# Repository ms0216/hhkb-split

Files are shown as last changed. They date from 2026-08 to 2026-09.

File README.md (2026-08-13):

# hhkb-split

**HHKB Professional HYBRID Type-S（PD-KB800WNS / US配列 / 無刻印）の使い勝手を、
完全分割型で再現する自作キーボード。**

> **開発中です。** 実機での動作確認はまだ済んでいません。
> 現状は「CAD とファームウェアがビルドを通り、寸法と配列が実機調査で裏付けられている」段階です。
> 3Dプリント・基板発注・組み立ては未実施。

## 基本方針

**HHKB オリジナルの使い勝手を極力踏襲する。** 分割にするために必要な変更だけを加え、
それ以外は変えない。この方針は [tools/test_invariants.py](tools/test_invariants.py) に
テストとして書き下してあり、設計の都合で妥協しようとすると機械的に落ちる。

守っているもの:

| 項目 | 値 | 根拠 |
|---|---|---|
| キーピッチ | 19.05mm | 実機公称 |
| 打鍵面の傾斜 | 7.3° | 実機ノギス実測 |
| 手前端の高さ | 17.5mm | 実測 17mm と別レビュー約18mm の中間 |
| キートップ高さ（各段） | 26.7 / 29.2 / 31.6 / 35.6 / 40.0mm | 公称全高 40mm から導出 |
| チルト脚 | 0 / 3 / 6° の3段階 | 実機と同一 |
| 行ずれ | HHKB と同一（格子配列にしない） | 実機 |
| 最下段 | 外側 1u / スペース寄り 1.5u | QMK info.json + KLE 図 |
| 電源 | 単3 × 2 | 実機と同じ思想（リポにしない） |

変更したもの:

- **打鍵感** — 静電容量無接点（Topre）→ MX 互換 + ホットスワップソケット
- **分割** — 6u スペースを 3u + 3u に分割。**左右とも Space**。キーは増やさない（60 → 61）
- **Mac/Win 切替** — 実機の DIP スイッチ相当をソフトウェアで実現
- **無線** — 左右間も Bluetooth。TRRS 有線は障害時の予備でしかない

## 構成

```
layout/        HHKB オリジナルと分割版のキー配列（JSON）
tools/         配列読み込み・CAD生成・検証（Python / build123d）
config/        ZMK ファームウェア設定
docs/hardware/ 実機の寸法調査と、その出典・失敗した調査経路の記録
build/         生成された STL（未印刷）
```

### tools/

パラメトリック CAD。`build123d`（OCCT）でモデルを生成し、`trimesh` で
メッシュ健全性を、OrcaSlicer CLI で実際にスライスできるかを検証する。

```bash
python -m pytest tools          # 全検査（約 14 分。件数は --collect-only で数える）
python tools/gen_case.py        # ケースを生成
python tools/verify.py          # メッシュとスライスの検証
```

[tools/interface.py](tools/interface.py) は**プレート・ケース・基板が共有する境界**を
1 箇所に集めたもの。ケースは刷り直せるが基板は発注し直すと高くつくので、
ここを凍結してから発注する。

### config/

ZMK。ボードは **Seeed Studio XIAO nRF52840**（技適 211-220207）。
XIAO は GPIO が 11 本しかなく普通のマトリクスに 1 本足りないため、列の駆動に
シフトレジスタ **SN74LVC595APWR** を使う（ZMK 公式が推奨する手段）。**74HC595 では打ち止め時に規格外**（動作電圧の下限 2.0V に対し、レールは 1.8V まで下がる）と分かって差し替えた。キーごとにダイオード 1 個の
ごく普通の行×列マトリクスなので、同時押しでゴーストが出ない。
当初はチャープレックス方式で設計していたが、基板発注前に破棄した
（[判断根拠](docs/hardware/decisions/2026-08-07-keyscan.md)）。

| シールド | 用途 |
|---|---|
| `hhkb_split_left` / `hhkb_split_right` | 本番。4レイヤー × 61キー |
| `proto_direct` | 疎通確認（XIAO 1個・キー2個）（[手順書](docs/hardware/task-c1-smoke-test.md)）✅ 実機確認済 |
| `proto_matrix` | マトリクス配線とゴースト試験の治具（[手順書](docs/hardware/task-c2-keyscan.md)）✅ 実機確認済 |

ビルドは GitHub Actions（ZMK 公式の再利用ワークフロー）。Actions の成果物から
`.uf2` をダウンロードして書き込む。

### 検証タスクの手順書

実機で確かめる作業は、配置図と判定基準つきの手順書にしてある。

| タスク | 内容 | 状態 |
|---|---|---|
| [C1](docs/hardware/task-c1-smoke-test.md) | 疎通確認（XIAO・書き込み・ZMK が実機で動くか） | ✅ 合格 |
| [C2](docs/hardware/task-c2-keyscan.md) | キースキャン（マトリクス・ゴースト・シフトレジスタ。治具は 74HC595、本番は 74LVC595） | ✅ C2-a 合格 / ⬜ C2-b |
| [C3](docs/hardware/task-c3-ble-split.md) | BLE 分割（左右同時押しが崩れないか） | ⬜ |
| [C4・C5](docs/hardware/task-c4-c5-power.md) | 乾電池給電・逆流の測定・電池残量 | ⬜ |
| [C6](docs/hardware/task-c6-confirm-on-real-hhkb.md) | 実機の DIP スイッチとキーマップを確認 | ⬜ **部品不要** |
| [B3](docs/hardware/task-b3-print-and-compare.md) | 3Dプリントして実機と比べる | ⬜ **部品不要** |

書き込みでつまずいたときは [xiao-flash-recovery.md](docs/hardware/xiao-flash-recovery.md)。

### docs/hardware/

実機を分解せず、公開情報だけから寸法を確定させた記録。
[reference-sources.md](docs/hardware/reference-sources.md) には**失敗した調査経路 11 件**も
残してある（例: PFU 公式記事に載っていた側面写真 4 枚が、よく見ると HHKB ではなく
MX 軸のキーボードだった）。同じ穴に落ちないため。

## 進捗

| フェーズ | 状態 |
|---|---|
| A. 実機寸法の確定 | ✅ 完了 |
| B. 機構設計（プレート・ケース） | ✅ STL 生成・検証済み / ⬜ 未印刷（[B3](docs/hardware/task-b3-print-and-compare.md)） |
| C. 電気・ファームウェア検証 | 🔶 進行中（**C1・C2-a 合格**。C2-b は 74HC595（治具用。本番は 74LVC595）待ち、C3〜C5 は部品待ち） |
| D. 基板設計（KiCad → JLCPCB） | 🔶 D1・D2a 完了（外形・キー配置・マトリクス）。[詳細](pcb/README.md) |
| E. 組み立て・実機調整 | ⬜ 未着手 |

## ライセンス

未定。

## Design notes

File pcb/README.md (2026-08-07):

# 基板（KiCad）

## 現在の状態

| 段階 | 内容 | 状態 |
|---|---|---|
| D1 | 外形・キー配置・取付穴 | ✅ 完了。DRC 違反 0 |
| D2a | マトリクス（61キー ＋ 61ダイオード ＋ 行列のネット） | ✅ 完了 |
| D3a | マトリクスの配線（行・列・スイッチ→ダイオード） | ✅ 左は違反 0 / ⚠️ 右に 5 件（下記） |
| D2b | XIAO・74HC595・電源の搭載 | ⬜ 3D 実装の検討が要る（下記） |
| D3 | 配線（行・列・電源） | ⬜ |
| D4 | JLCPCB 向け出力（ガーバー・BOM・CPL） | ⬜ |

マトリクスは配線済み（**未配線 0**）。左半分は DRC 違反 0。

### 右半分に残る 5 件

すべて `hole_clearance`（配線が穴に近すぎる）で、原因は特定済み。

列のバスは行間の空きを横に渡るが、**スタビライザーの穴がその帯に食い込んで
いる**（キー中心 +6.2〜10.2mm）。9 列ぶんの通り道を 0.8mm 間隔で並べると、
穴を避けきれない列が出る。

取りうる手:
  1. 穴に当たる区間だけ迂回させる（自動配線の作り込み）
  2. 配線幅と間隔を詰めて通り道を増やす（JLCPCB の最小は 0.127mm）
  3. 該当箇所だけ KiCad の GUI で手直しする

**左半分が完全に通っているので、方式の問題ではない。**

### D2b でまず決めること — XIAO をどこに置くか

XIAO は基板の**裏面**に付く（表に置くとキーキャップと当たる）。ところが
USB-C は実機と同じく**背面**に出す必要があり、基板の裏の背面側には
**電池室（幅 109mm）**が横断している。左半分では電池の外側に
15mm ほどしか残らず、XIAO の 17.8mm が入らない。

取りうる案:
  1. USB-C を基板端のコネクタとして別に載せ、XIAO は空いている隅に置く
  2. 電池を左右に振り分けて中央を空ける（ケースの作り直しが要る）
  3. USB の位置を実機と変える（使い勝手の方針に反するので最後）

**ケースの 3D モデルと合わせて検討する必要がある。** 実測（Task C4）で
電源部の構成が確定してから着手するのが順序として正しい。

## 生成のしかた

`pcbnew` は KiCad 同梱の Python にしか無いので、そちらで動かす。

```bash
/Applications/KiCad/KiCad.app/Contents/Frameworks/Python.framework/Versions/3.9/bin/python3.9 \
    tools/gen_pcb.py
```

## 検証のしかた

```bash
# デザインルール検査（違反があれば終了コードが非 0）
/Applications/KiCad/KiCad.app/Contents/MacOS/kicad-cli pcb drc \
    --severity-error --exit-code-violations pcb/hhkb_split_left.kicad_pcb

# 生成物が設計値と一致するか（通常の pytest から実行できる）
python -m pytest tools/test_pcb.py

# 目で見る
/Applications/KiCad/KiCad.app/Contents/MacOS/kicad-cli pcb render \
    --output /tmp/pcb.png --side top pcb/hhkb_split_left.kicad_pcb
```

`.kicad_pcb` はテキスト（S 式）なので、`tools/test_pcb.py` は pcbnew 無しで
読める。**生成した基板を読み返して、プレート・ケースと突き合わせる**のが要点。
別々に生成される以上、同じ設計値から導いていても座標変換を間違えれば静かに
ずれる。ずれたまま発注すると数万円が無駄になる。

## 寸法

| | 左 | 右 |
|---|---|---|
| 基板 | 140.36 × 102.00mm | 173.70 × 102.00mm |
| スイッチ | 27 | 34 |
| スタビライザー | 2 | 2 |
| 取付穴 | 7 | 7 |

外形はプレートより片側 3.0mm 小さい（`interface.PCB_INSET`）。ケースの
側壁 2.4mm の内側に収める必要があるため。

奥行 102.00mm ＝ プレート 108.00mm − 6.0mm。プレートの 108.00mm は
HHKB 実機の本体奥行そのもの。

## ライブラリ

`lib/` を参照。KiCad 標準に無い 3.00u とホットスワップソケットだけを
kiswitch から取り込み、寸法を規格値と照合してある。

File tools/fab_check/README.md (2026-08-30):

# 発注前の結線検証（fab-checklist §6・§7 の視点 B）

板の実体から全パッドの位置とネットを抜き、外部資料（TI / Seeed / Hirose）と
ファームの dtsi に突き合わせて、証拠ページを作る。2026-08-28。

    KPY=/Applications/KiCad/KiCad.app/Contents/Frameworks/Python.framework/Versions/3.9/bin/python3.9
    "$KPY" tools/fab_check/dump_pads.py       # → build/fab_check/pads.json
    .venv/bin/python3 tools/fab_check/evidence.py   # → evidence.json と注釈画像
    .venv/bin/python3 tools/fab_check/report.py     # → build/fab_check/report.html

1:1 印刷用 PDF は `kicad-cli pcb export pdf --layers "Edge.Cuts,B.Cu,F.Cu,B.Fab,F.Fab,B.SilkS,F.SilkS"`。

## 1:1 PDF を測り直すとき（2026-08-30）

`build/fab_check/*_1to1_*.pdf` は `--scale 1`（既定）で **実寸**。300dpi に
ラスタライズして外形（Edge.Cuts）を測ると設計値と一致する:
left 138.52×97.45（設計 138.36×97.40）、daughterboard 21.08×32.09（設計 21.0×32.0）。
差の 0.1mm 弱は外形線の太さ（0.1mm）が線の外側にはみ出す分。

⚠️ **二値化のしきい値に注意。**角の円弧は細くアンチエイリアスされるので、
`< 200` で拾うと角が落ち、**left が 131×93、daughterboard が 18×30 に見えて
「1:1 でない」という誤った結論が出る**（実際に一度出した）。**`< 250` で拾うこと。**
測り方そのものは 100mm 角の合成 PDF で校正した（誤差 0.01mm）。

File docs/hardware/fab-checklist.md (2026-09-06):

# 発注の直前に見るもの

**ここに記録が無いと `pytest` が落ちる。**製造ファイル（`pcb/fab/`）が
存在するのに、下の各節が書かれていなければ
`tools/test_invariants.py` が止める。**黙って発注できないようにしてある。**

書いたら消さないこと。次に発注するときの記録になる。

---

## 発注履歴

| 日付 | 対象 | 実装枚数 | 表面処理 | 備考 |
|---|---|---|---|---|
| **2026-09-03** | **左・子基板**（右は未発注） | 左 5 / 子基板 5 | 有鉛 HASL | §1 の目視確認済みで発注。注文番号は非公開（このリポジトリは公開）。右は左の検証を経てから。**2026-09-04: JLC エンジニア調整後の「Confirm Parts Placement」図を拡大して再照合**——左 D1/D11/D12 の帯が下端・U1 の Pin 1 が右下・J_DB 口が奥、子基板 D_PWR の帯が左端・J_MAIN 口が手前。発注前の図・KiCad のパッド座標と全一致。子基板 Assembled 4 / Unassembled 0 |

---

## 0. 発注フォームで選ぶもの（**ファイルには入っていない**・2026-09-02）

ガーバー・BOM・CPL に書かれず、**発注ページで人が選ぶ値**。ここに無いと
毎回思い出すことになる。

| 項目 | 値 | 根拠 |
|---|---|---|
| 層数 / 厚さ | **2 層 / 1.6mm** | `envelopes.PCB_T = 1.6`。ケース・プレート・ソケットの落ち込みが全部この値で計算されている。**1.2 や 2.0 を選ぶとプレートからソケットまでの寸法が狂う** |
| 銅厚 | 1oz（既定） | `pcb_rules.JLC` は 1oz の能力値 |
| 表面処理 | **HASL（有鉛・¥0）**。無鉛 HASL は +¥222（2026-09-03 実測）。ENIG は任意 | 最細ピッチは FFC の 0.5mm。HASL で実装実績のある範囲。板はケースの中で、部品はんだは JLC が付けるので有鉛で機能上の差なし（2026-09-03 に利用者が有鉛を選択） |
| 注文番号の印字 | **Remove Order Number** を選ぶ（または任意の場所） | 選ばないと JLC が空いた所にシルクで番号を刷る。表面はキーの下で見えないが、裏面のシルクに重なりうる |
| 実装面 | **Bottom（裏面のみ）** | 3 枚とも SMD は全部 B.Cu。F_Paste は空（→ 1b） |
| 実装枚数 | 主基板は板 5 枚のうち **2 枚**を実装（→ 5.）。**子基板は 5 枚全部**（1 台に 2 枚要るので 2 枚だと予備 0。部品が安く差額は数百円。2026-09-03） | |
| 「Confirm Parts Placement」 | **Yes** | 第 1 節の目視はここで出るプレビューでやる |
| PCBA の区分 | **Economic**（Standard を選ばない） | Standard は部品〜板端 ≥2.5mm と 70×70mm 以上が条件。実測: 左 D24・右 D9/D31 が板端 1.40mm、子基板 J_MAIN 0.55mm、子基板は 21×32mm。Economic は 0.3mm・10×10mm〜・片面で、3 枚とも B 面のみなので足りる（[JLC PCBA capabilities](https://jlcpcb.com/capabilities/pcb-assembly-capabilities)・2026-09-02 §8b） |

## 0b. ⚠️ 実際の発注道具（Fabrication Toolkit）を本番の板に通した（2026-09-02）

**`export_fab.py` で直しても、発注は別の道具で作る**（#52）。その道具
（bennymeg/JLC-Plugin-for-KiCad。`~/Documents/KiCad/10.0/3rdparty/plugins/`）
の CLI を **本番の板 3 枚に実際に通して出力を読んだ。**3 つ出ていた:

| 出ていたもの | 何が起きたか | 直し |
|---|---|---|
| **BOM の LCSC Part # が全行空** | 番号は `parts.py` にしかなく、板には無かった。JLC は値と footprint から自動で候補を出すが、**FH12・BAT46W・74LVC595 は別品が当たりうる** | フットプリントに `LCSC` フィールドを焼き込む |
| **ソケット 61 個が CPL で `top`** | プラグインは `fp.GetLayer()` で面を決める。**1b と同じ穴・道具違い** | `FT Layer Override = bottom` フィールド（プラグインが読む上書き） |
| **XIAO（U_MCU）が BOM と CPL に載る** | 利用者がピンソケットで載せる部品。JLC に実装させない | `exclude_from_bom` `exclude_from_pos_files` 属性 |

道具は `tools/fab_fields.py`。`finalize_pcb.py` と `gen_daughterboard.py` が
保存前に呼ぶ。**直した板でもう一度プラグインを通し、BOM 全行に番号・
CPL 134 点すべて `bottom`・XIAO 無しを確認した。**さらに
**プラグインの CPL（回転・座標・面）と `export_fab.py` の CPL を 134 点
突き合わせて差 0**——別の作者の実装どうしが一致した。

検査: `test_every_assembled_part_carries_its_lcsc_number_on_the_board` /
`test_parts_soldered_on_the_other_side_say_so_for_the_fab_tool` /
`test_the_xiao_is_not_handed_to_the_assembler`。**3 つとも故意に壊して
赤になることを確認した。**

**実際に回したコマンド（2026-09-03・左と子基板）**。`cli.py` は相対 import なので
**プラグインのディレクトリからモジュールとして**呼ぶ。出力先は `pcb/production/` 1 か所で
**板ごとに上書きされる**ので、1 枚回すたびにサブフォルダへ移す。最後に wxWidgets の
assert が出るが出力はできている（出来た物を見て判定する）。

```
cd ~/Documents/KiCad/10.0/3rdparty/plugins
KPY=/Applications/KiCad/KiCad.app/Contents/Frameworks/Python.framework/Versions/3.9/bin/python3.9
"$KPY" -m com_github_bennymeg_JLC-Plugin-for-KiCad.cli -p <repo>/pcb/hhkb_split_left.kicad_pcb -t -nI
mv <repo>/pcb/production/{bom.csv,positions.csv,designators.csv,netlist.ipc,hhkb_split_left.zip} <repo>/pcb/production/left/
```

発注ページへ上げるのは zip・`bom.csv`・`positions.csv` の 3 つ。`designators.csv` は使わない
（XIAO が載っているが BOM/CPL には無い）。

⚠️ プラグインは **`-t`（Apply automatic position/rotation translations）を
付けて**回すこと。付けないと TSSOP の 270° 補正が入らない（CLI では `-t`、
GUI ではチェックボックス）。

## 1. 配置プレビューで部品の向きを見る（**機械では確認できない**）

**KiCad のフットプリントの向きと JLCPCB のライブラリの向きは一致しない。**
`tools/export_fab.py` は共有されている補正表（matthewlai/JLCKicadTools）を
当てているが、**それが JLCPCB にとって正しいかは、こちらからは検証できない。**

JLCPCB の発注ページに部品を並べた**配置プレビュー**が出る。そこで見る。

| 見るもの | 何が起きうるか |
|---|---|
| **74LVC595（U1・右は U2 も）** | 補正 270 度を当てている。**ずれていたら 90 度単位で回っている** |
| **ダイオード 62 個（D1〜61 + D_PWR）** | **向きが逆だと 1 つも反応しない。**カソード（帯）が行の側。**2026-08-16 判明・未対応**: `ROTATION_DB`（出典 matthewlai/JLCKicadTools）に SOD 系の補正値が 1 件も無く、無補正のまま出している。同ツールの Issue #28 で「同じ SOD パッケージでも LCSC 品番により向きが違う」既知の限界が報告済み。JLCPCB の配置プレビューで D_PWR（B5819W・C7420330）を目視すると「+」マークが出るが、**これが Pin 1 を指すのか、KiCad 側のカソード位置と何度ズレているのかは未確定**（JLCPCB の UI にツールチップ等の裏付けが無い）。**この基板は `export_fab.py` を使わず、別の KiCad プラグインで CPL を作る運用**なので、このリポジトリの `ROTATION_DB` を直しても実際の発注には効かない。**発注前に必ず配置プレビューで目視し、カソード（帯）が V3V3 側に来ているか確認すること**（[open-gaps #52](open-gaps.md)。旧 #42・GND スタブの #42 と衝突していたので 2026-08-24 に改番） |
| **FFC コネクタ（J_DB・J_MAIN）** | ⚠️ **「向き」には 2 つの意味がある**（2026-09-01・利用者の指摘で分けた）。**①ピン配置は確認済み**——KiCad 公式フットプリントのピッチ 0.500mm・12 極が Hirose の公表スペック（12 極 / 0.5mm / 全長 10.1mm / bottom contact）と一致し、**J_MAIN pin n ↔ J_DB pin 13−n が 12 本すべて同じネット**（→ §7）。**②実装の回転だけが未確認**——補正表に無く、JLCPCB が何度回して載せるかはこちらから検証できない。**配置プレビューで見るのはこちら** |
| **ホットスワップソケット（SW1〜）** | **補正表に無い。**確認していない。61 個ある。⚠️ **2026-09-01 追加: 面も見ること。**このリポジトリの `export_fab.py` は**ソケット 61 個を `top`（表面）と書いていた**（→ 1b）。直したが、**実際の発注は別プラグインで作る運用**（#52）で、**そちらも同じ間違いを出していた（2026-09-02 に実際に通して確認・→ 0b で修正済み）**。**配置プレビューを裏面（Bottom）に切り替えて、ソケット 61 個がそこに並ぶことを見る。**表面に並んでいたら CPL の Layer 列を手で `bottom` に直す |

0805 と 1206 の受動部品は向きが無いので見なくてよい。

**2026-08-30: SOD-123 は 62 個すべて同じフットプリント**（マトリクスの BAT46W も D_PWR の B5819W も `D_SOD-123`・パッド 1=K）。**どれか 1 個で向きが読めれば、62 個すべてに同じ結論が使える。**

| 見る部品 | 面 | 回転 | 帯(K)が来る側 |
|---|---|---|---|
| 子基板 D_PWR | B.Cu | 180° | V3V3 側（+X） |
| 左 D1 / 右 D1 | B.Cu | 90° | ROW 側（+Y・手前） |

逆向きだと **D_PWR は電池で動かず**（USB では動く）、**マトリクスはキーが 1 つも入らない**。

### 確認したら、ここに書く

<!-- 下の見出しをそのまま残して、日付と結果を書くこと -->

**2026-09-03 確認済み（左・子基板。発注ページの 3D 配置プレビュー・Bottom 表示・利用者のスクリーンショットを私が KiCad の板のパッド座標と突き合わせた）**

前提: JLCPCB の Bottom 表示は**裏から見た絵**（X だけ裏返り、Y はそのまま。裏面シルク "SSKB LEFT" が正しく読める）。

| 部品 | KiCad の板（pcbnew でパッド座標を読んだ） | JLCPCB の 3D プレビュー | 判定 |
|---|---|---|---|
| **左 D1**（BAT46W・SOD-123・62 個の代表） | Pin 1=K（ROW_C）が y=65.55、Pin 2=A（SW1_D）が y=62.25 → **帯は手前（画面の下）** | 3D 本体の灰色の帯が**下端**。シルク枠も下端だけ閉じている。「+」はアノード側の上パッド | ✅ 一致 |
| **子基板 D_PWR**（B5819W・同じ SOD-123） | Pin 1=K（V3V3）が x=153.16（+X）→ Bottom で裏返って**画面の左端** | 帯（白線）と三角の先が**左端**。「−」が左・「+」が右 | ✅ 一致 |
| **左 U1**（74LVC595・TSSOP-16） | Pin 1（COL1）が (192.28, 91.0) ＝ 左下 → Bottom で**右下** | 3D の Pin 1 の黒点が**右下**。シルクの三角も右下 | ✅ 一致 |
| **左 J_DB**（FH12） | パッド列 y=85.38 が中心 83.525 より手前 → **口は奥向き** | 金色のピンが下（手前）、口が上（奥） | ✅ 一致 |
| **子基板 J_MAIN**（FH12） | パッド列 y=109.15 が中心 111.0 より奥 → **口は手前向き**（J_DB と逆で、2 枚を並べるとケーブルが直線） | ピンが上（板の内側）、口が下（板の端） | ✅ 一致 |
| **ソケット 27 個** | パッドは B.Cu | Bottom にマゼンタの形で 27 個。3D モデルが無いだけで実装対象（CPL 57 点＝27+27+3） | ✅ |
| **XIAO（U_MCU）** | 発注しない | BOM・CPL とも無し。14 穴は空 | ✅ |

**「+」マークの意味（#52 の未確定だったもの）**: 62 個ともアノード側のパッドに「+」、D_PWR にはカソード側に「−」が出た。**「+」＝ Pin 1 ではなく、＝アノード**。判定は 3D 本体の帯で行い、「+」はその裏付けにだけ使った。

右基板は未発注（今回は左＋子基板だけ）。右を出すときは U1/U2 と D1 と J_DB を同じ手順で見ること。

---

## 1b. ⚠️ CPL の実装面が間違っていた（2026-09-01 発見・修正済み）

**61 個のホットスワップソケットが「表面に実装せよ」という指示で出ていた。**
実際にはんだ付けするのは**裏面**（パッドが B.Cu にある）。

**原因**: `export_fab.py` が実装面を `fp.IsFlipped()` で決めていた。
それは**フットプリントを置いた側**であって、**はんだ付けする側ではない**。
ホットスワップソケットはこの 2 つが食い違う——上流 perigoso のフットプリントは
`(layer "F.Cu")` に置きつつ、パッドを `(layers "B.Cu" "B.Mask" "B.Paste")` と
裏に宣言している（**キーは表から挿し、ソケットは裏から付ける**部品だから）。

**噛み合っていなかった証拠**: ペーストは `B_Paste` にしか無く
（左 140 / 右 186 / 子 20 フラッシュ）、**`F_Paste` は 3 枚とも空**。
それなのに CPL は左 27 点・右 34 点を `top` と書いていた。

**直し方**: **SMD パッドが実際にどちらの銅箔に載っているか**（`IsOnLayer(B_Cu)`）で
決めるようにした。⚠️ **`pad.GetLayerName()` は使えない**——
裏面のパッドでも `F.Cu` を返す（`build/fab_check/pads.json` もこれで
誤った面を記録している）。`IsOnLayer()` で見ること。

**確認**: 3 枚 134 点すべてで「CPL の面 ＝ パッドの面」を照合し、**食い違い 0**。
CPL は全点 `bottom` になり、`B_Paste` しか無いことと噛み合った。

⚠️ ソケットの回転が 0.0 → 180.0 に変わった（裏面の式 `(-rot+180)%360`）。
**ソケットは `ROTATION_UNVERIFIED` に入っているので、いずれにせよ
配置プレビューでの目視が要る**（第 1 節）。

## 2. 在庫と価格をもう一度見る

```
.venv/bin/python3 tools/jlcpcb_lookup.py --parts
```

**在庫は動く。**FFC コネクタ（C88360）が最も薄い。前回 2,868 個で、
必要なのは 15 個。**在庫 0 の部品を指定しかけたことが実際にある。**

| 確認日 | 結果 |
|---|---|
| 2026-08-24 | **全 7 品番在庫あり。**最薄は C88360（FFC）2,408 個。ほか C52287685（595）2,443 / C49352235（ソケット）21,949 / C54110（BAT46W）30,501 / C8598（B5819W）628k / C49678・C17514（0805）3.2M〜18.8M |
| **2026-08-31** | **全 7 品番在庫あり。**最薄は C88360（FFC）**1,916 個**（→ 2b）。ほか C52287685（595）2,326 / C49352235（ソケット）22,981 / C54110（BAT46W）25,497 / C8598（B5819W）589k / C49678・C17514（0805）2.9M〜18.2M。**5 セット実装しても在庫倍率は最小 75 倍**（ソケット）で数量は問題ない |

## 2b. ⚠️ FFC コネクタ（C88360）の在庫が減り続けている（2026-08-31 発見）

**数量は足りている。危ないのは「板を作ってから品切れる」こと。**

| 日付 | 在庫 |
|---|---|
| 2026-08-11 | 2,868 |
| 2026-08-24 | 2,408 |
| **2026-08-31** | **1,916** |

**20 日で 952 個減（1 日 48 個）。このペースなら約 40 日で 0。**
必要なのは 1 セット 3 個／5 セット 15 個なので**数量は全く問題ない**が、
**Extended 部品は再入荷が読めない。**

**なぜ他の部品と違って危ないか**: このフットプリントは
**Hirose FH12-12S-0.5SH の形に固定されている**（信号パッド 12×0.5mm ピッチ・
金具 2 個が (±4.65, +1.4)・パッド列は中心から y −1.85）。
JLCPCB には 12P 0.5mm の代替が多数あるが（05A20L12P・0.5K-A-12PB など、
在庫 1 万個超で単価も 1/3）、**どれも金具の位置やピンの並び（staggered など）が
違い、そのままでは載らない。**代替に替えるなら**基板の作り直し**になる。

**→ 対策は「在庫があるうちに発注する」だけ。**
⚠️ **この部品は JLCPCB が実装してくる。**利用者が別途買うものではない
（2026-09-01 に「確保とはどういうこと？」と聞かれた。**書き方が悪かった**）。
心配しているのは **JLCPCB の在庫**で、**発注が遅れて 0 になると
「その部品だけ実装されずに届く」か「発注できない」**という話。

**いま 1,916 個・必要 15 個・1 日 48 個減 → 数週間以内に発注すれば問題ない。**

## 2c. 在庫が切れたときの代替（2026-09-01 に調べた）

**「在庫があるか」だけでなく「切れたらどうするか」まで見た。**
Extended 部品は再入荷が読めないので、代わりが効くかどうかで危険度が変わる。

| 部品 | 在庫の減り | 代替 | 危険度 |
|---|---|---|---|
| **FFC コネクタ** C88360 | **1 日 48 個・約 40 日で 0** | **無い。**12P 0.5mm の代替は多数あるが（在庫 1 万個超・単価 1/3 の品もある）、**金具の位置とピンの並びが違って載らない**。替えるなら基板の作り直し | **★★ 高** |
| 74LVC595 C52287685 | 1 日 17 個・約 137 日で 0 | **ある。[C426713](https://jlcpcb.com) Nexperia 74LVC595APW,118 / TSSOP-16・在庫 3,592（本命より多い）・$0.2806。**同じ TSSOP-16 でピン配置も同じ。電源範囲 **1.2〜3.6V** でレール下限 1.83V の内側（TI は 1.1V。どちらも足りる） | 低 |
| ソケット C49352235 | 在庫 22,981（必要 305） | 未調査だが在庫が厚い | 低 |
| BAT46W C54110 | 在庫 25,497（必要 305） | バックアップは 1N4148W（C81598・Basic）。**`circuit.MATRIX_DIODE_VF` を 0.55 へ戻すと打ち止めが 1.20V/本に上がる**（parts-audit §2） | 低 |
| 0805・B5819W | 数十万〜数百万 | いくらでもある | 無 |

**→ 危ないのは FFC コネクタ 1 つだけ。**ただし**やることは「早めに発注する」だけ**で、
**利用者が別途買うものは無い**（7 品番すべて JLCPCB が実装してくる）。
在庫が切れて困るのは、**代替が無い**この 1 品番だけ、という意味。

## 3. FFC ケーブルの向き

`open-gaps` #19。**✅ 2026-08-16 決着: A タイプ（同面）・80mm**
（uxcell 20 本入り）。買うだけ。残りは `FFC_RIBBON_W` / `FFC_SLACK` の実測。

## 4. アンテナの risk を承知する

`open-gaps` #23。**✅ 2026-08-23 決着**——手 0（アルミ箔で地板を模擬・実測）で
E の差 −7dB・共振なしを確認し、**「### 承知して発注する」の節は作成済み**
（`pytest` と `export_fab.py` の門は開いている）。発注時に読み直すだけ。

## 4b. 生成のリハーサル（記録）

| 日付 | 結果 |
|---|---|
| 2026-08-25 | `export_fab.py` を通しで実行: **3 基板とも門 3 つ（アンテナ承知・部品表・回路図一致）を通過**。左 ガーバー 11 / BOM 5 行 / CPL 57 点、右 11 / 5 / 73、子基板 11 / 3 / 4。警告は「回転が未確認」（FFC コネクタとホットスワップソケット）のみ＝第 1 節の目視項目そのもの。出力は発注時に作り直すので削除した（残すと第 1 節の記録が無い限り pytest が落ちる） |
| 2026-08-27 | #49 露出後の板で再実行: 3 基板とも門を通過（左 11 / 5 / 60、右 11 / 5 / 73、子基板 11 / 3 / 4）。**B.Mask ガーバーに露出ビアの開口があることを座標で確認**（左 5 点・右 6 点すべて）。警告は前回と同じ回転未確認のみ。出力は削除 |
| 2026-08-28 | SPARE/SPARE2 露出＋右ビア径統一後に再実行: 3 基板とも門を通過（左 11 / 5 / 57、右 11 / 5 / 73、子基板 11 / 3 / 4）。**B.Mask の開口を SPARE/SPARE2 の 4 点で座標確認。**警告は回転未確認のみ。出力は削除 |

## 6. 595 と XIAO のピン配置を、独立した 4 視点で確認する（**A・B・D 済・2026-08-30**）

**利用者の指示（2026-08-28）: 「0Ω では救えない。その代わり、絶対に間違えが
ないことを複数の視点で確認する」。**間違っていたら板の作り直しになる 2 部品。
1 つの視点が壊れても別の視点で捕まるよう、**情報源が互いに独立**なものを選ぶ。
済んだ視点は日付と見た物を書く。

| 視点 | 何と何を突き合わせるか | 済 |
|---|---|---|
| A. データシート ↔ `pinmap.py` | TI SCASE93A Table 4-1 と [tools/pinmap.py](../../tools/pinmap.py)（ピン名→番号）。Seeed 公式ピン配置図と `XIAO_nRF52840.kicad_mod`（座標・名前） | 2026-08-28 機械照合（前回の回答）。**ただし同じ人が同じ表を読んだ 1 視点** |
| B. フットプリントの 1 番ピンの位置 ↔ 部品の実物写真 | `render_pcb.py --zoom U1`（右は U2 も）で 1 番ピンの丸印と、**LCSC C52287685 の商品写真のマーク**の向き。SPI_SCK が 11 番、VCC が 16 番に来ているかを**シルクの位置で**読む | |
| C. 回路図 ↔ 板（KiCad の突き合わせ） | `export_fab.py` の門 3「回路図一致」＋ **KiCad GUI で U1 の各ピンをクリックしてネット名を読む**（表示はデータシートのピン名で出る） | |
| D. Seeed 公式 KiCad ライブラリ（別の作者・別の出所） | `Seeed-Studio/OPL_Kicad_Library` の `XIAO-nRF52840-DIP.kicad_mod`（14 穴の座標）＋ `Seeed_Studio_XIAO_Series.kicad_sym`（ピン番号→名前: 1=D0 … 11=D10, 12=3V3_OUT, 13=GND, 14=VBUS）＋ フットプリントの USB の出っ張り（+x 端）を、自作 `XIAO_nRF52840.kicad_mod` と**鏡像・回転 8 通りで照合**。**鏡像なし・90° 回転で 14 穴すべて誤差 0.000mm、USB は自作の奥側**（`build/fab_check/xiao_vs_seeed.json`）。1:1 印刷案は取り下げ（足のパターンが対称で向きの誤りを検出できない） | **2026-08-30 済** |

視点 A が私の照合、B〜D は**別の物理的な情報源**（写真・GUI・実物）。
**2026-08-30 再実行（#19/#49 後の板で）**——`tools/fab_check/` の 3 本を通し、**595 48 パッド全一致（左 U1・右 U1/U2）・XIAO 14 パッド全一致（Seeed 座標と誤差 0.000mm）・キー 61 個の経路が dtsi と全一致・FFC 12 本が鏡像で 1 対 1**。板を作り直しても結線は不変であることを確認した。
**1:1 PDF も 6 本すべて出し直した**（08-28 のものは #19/#49 前の板だった）。実寸であることを外形の実測で確認（left 138.52×97.45 / 設計 138.36×97.40）。
**2026-09-03 再々実行（#53 のスタビ回転・#56 のスペース移動後の板で）**——`tools/fab_check/` の 3 本: **595 48 パッド一致・XIAO 14 パッド一致・61 キーの経路が dtsi と一致**（`evidence.json` の `u595_ok / xiao_ok / chain_ok` すべて true）。1:1 PDF 6 本も出し直し、Edge.Cuts だけを 300dpi で測って **left 138.51×97.45 / right 171.79×97.45 / 子基板 21.08×32.09**（設計 138.36 / 171.70 / 21.0。差は線の太さ分）。⚠️ 全層入りの PDF で測ると F.Fab の `MountingHole` の文字が外形の外にはみ出して **147.4mm に見える**——測るときは Edge.Cuts だけを出すこと。
**2026-08-28: 視点 B の機械版を実施**——板の全パッドを抜いて TI / Seeed の表と突き合わせ、48+14 パッド一致・61 キーの経路がファームと一致（`tools/fab_check/`・証拠ページ `build/fab_check/report.html`）。1:1 PDF は `build/fab_check/*_1to1_*.pdf`（取付穴間隔 16.00mm で確認済み）。
**2026-08-30 追加: 視点 E（外部ソースでの独立確認）。**A〜D とは別に、
**このリポジトリの外**の一次情報と突き合わせた。**A と evidence.py は同じ TI の表を
同じ人が読んだものなので、その読み違いは両方に同じように入る**（共倒れの穴）。
そこを別の出所で塞いだ。

| 何を | 何と突き合わせたか | 結果 |
|---|---|---|
| 595 の 16 ピン | **KiCad 公式 `74xx.kicad_sym` の `74HC595`**（KiCad ライブラリアンが独立に起こしたもの） | **16 本すべて `pinmap.py` と一致。**電気的種別まで一致（QH' が output で tri_state でないことも） |
| 595 の ~SRCLR / ~OE | 同上（能動 Low であること） | ~SRCLR→V3V3（解除）・~OE→GND（出力有効）。**3 個とも正しい** |
| 数珠つなぎの並び | **ZMK 実物のドライバ `app/module/drivers/gpio/gpio_595.c`**（"lowest byte is for the first in the chain" ＋ MSB first） | **index 8 → 鎖の奥 = U2 の QA。**基板は COL8 を U2.QA(15番) に配線。**index 0..8 が COL0..COL8 に一致** |
| SPI がどの足に出るか | **Zephyr 上流 `boards/seeed/xiao_ble/xiao_ble-pinctrl.dtsi`** | spi2 = SCK **P1.13** / MOSI **P1.15** / MISO P1.14 |
| D 番号 → 物理ピン | **Zephyr 上流 `seeed_xiao_connector.dtsi`** | D7=P1.12・D8=P1.13・D10=P1.15。→ **SCK=D8 / MOSI=D10 / CS=D7 が上流の定義で裏付く**（それまでは自分の dtsi のコメントだけが根拠だった） |

**2026-08-31 追加: フットプリントの出所を全部数えた。**
「複数の視点が一致すれば保証できるのでは」という問いに答えるには、
**まず自作（＝外の照合が無いもの）が何個あるかを数える**必要がある。数えた。

| フットプリント | 出所 | 外との照合 |
|---|---|---|
| XIAO_nRF52840 | **自作** | ✅ 視点 D。Seeed 公式ライブラリと 14 穴 0.000mm |
| SW_Hotswap_Kailh_MX ×5 | **perigoso/keyswitch-kicad-library**（⚠️ 当初「自作」と書いたが誤り。3D モデルの参照先で分かった） | ✅ **2026-08-31 に照合。**上流と**パッド完全一致**（5 サイズとも diff 差分なし）。加えて Cherry MX の公開規格（ステム φ4.0・位置決め ±5.08・端子 (-3.81,-2.54)/(2.54,-5.08)）とも一致。MX は無極性なので 1/2 の割り当てで壊れようがない |
| Stabilizer_Cherry_MX ×2 | **perigoso/keyswitch-kicad-library** | ✅ **2026-08-31 に照合。**上流と**穴 4 つが完全一致**（2.00u・3.00u とも）。⚠️ **「電気的接続が無いから確認不要」は誤り**——穴の位置がずれれば**スタビが入らず板の作り直し**になる。位置も見た（下記） |
| Hirose FH12-12S-0.5SH | **KiCad 公式** | ✅ **2026-08-31 に照合。**3 個（J_MAIN・左右 J_DB）とも公式と**0.0000mm 一致**。各々ひとつの変換でのみ一致＝向きも一意 |
| D_SOD-123 / TSSOP-16 / 0805 / MountingHole | **KiCad 公式** | 公式そのもの |

→ **真に自作なのは XIAO のフットプリントだけ**（視点 D で照合済み）。
ほかは KiCad 公式か perigoso で、いずれも上流と一致することを確認した。

**スタビライザーの位置（2026-08-31・利用者の指摘で確認）**

「電気的接続が無いから確認不要」と書きかけたが**誤り**。穴の位置がずれれば
**スタビが入らず、板の作り直し**になる。見た。

| 見たこと | 結果 |
|---|---|
| 上流との一致 | 2.00u・3.00u とも**穴 4 つが完全一致**（diff で差分なし） |
| スイッチとの同心 | 4 個すべて**ずれ 0.000mm**（ST19↔SW19・ST27↔SW27・ST24↔SW24・ST32↔SW32） |
| **付く場所が正しいか** | 幅 ≥2u のキーだけに付いている。**LSHFT 2.25u・RET 2.25u・SPACE 2.75u×2**（2026-09-02 再確認: スペースを内側端へ動かした後の板でも 4 個とも同心ずれ 0.000mm・スタビは 2.00u・最下段の 2 個は 180°・穴の縁→板前縁 2.14mm。→ [open-gaps #56](open-gaps.md)） |
| **付いていないキーが正しいか** | **BSPC は実機 HHKB では 1.50u**（標準キーボードの 2u ではない）、**RSHFT は 1.75u**。どちらもスタビ不要で正しい |
| 銅との干渉 | パッド・ビア・配線のいずれとも**近すぎ 0 件** |

⚠️ **HHKB の幅は標準配列と違う。**BSPC を 2u、RSHFT を 2.75u と思い込むと
「スタビが足りない」という誤った結論になる（実際に一度そう疑った）。
基板の 10 個の幅は**実機と全一致**（SPACE のみ 6u を左右 3u に分割）。

**視点 E で新たに分かったこと**（機械では気づけていなかった）:
`export_fab.py` の `ROTATION_UNVERIFIED` に **`D_SOD-123` が漏れていて、
62 個のダイオードが警告なしで出ていた**。§1 と open-gaps #52 は「目視せよ」と
書いてあるのに、**発注時に読む道具だけが黙っていた。**足した。

**4 つのうち 3 つが済むまで「確認した」と書かない。**（2026-08-30: A・B・D 済。C＝KiCad GUI でピンをクリックは利用者・任意）

## 7. FFC の接続関係を、独立した 4 視点で確認する（**A・B 済。C は組立時・D は通電前**）

**利用者の指示（2026-08-28）: FFC も XIAO・595 と同様に絶対に間違えてはいけない。
基板間の接続関係も含めて複数視点で。**逆なら 12 本が全部入れ替わる（GND↔ROW_E、
3V3↔ROW_D …）。板は無傷でもケーブル（A/B タイプ）の買い直しと日数を失う。

| 視点 | 何と何を突き合わせるか | 済 |
|---|---|---|
| A. 回路の宣言どうし | `circuit.py` の J_DB（主基板）と J_MAIN（子基板）のピン表が鏡像で 1 対 1（`test_the_two_boards_agree_on_the_cable` / `test_the_cable_pinout_table_matches_the_circuit`） | 検査は緑（2026-08-30）。**自分の生成物どうしの一致**なので 1 視点 |
| B. 幾何（板の上のピン 1 の側） | `render_pcb.py --zoom J_DB` と `--zoom J_MAIN` で **両コネクタのピン 1 の位置**と実装面（両方 B.Cu）を読み、**A タイプ（同面接点）でピン 1 がピン 1 に来る向き**かを紙の上で追う。FH12 は**下接点**（データシートの図で確認） | **2026-08-30 済**: J_DB を奥向きに回して直線経路に。J_MAIN ピン 1(+X) ↔ J_DB ピン 12(+X)、表は鏡像。組立モデル断面で目視 |
| C. 1:1 印刷＋実物 | 2 枚を 1:1 で印刷してケースの配置どおりに置き、**実物の FFC（買ったもの）を実際に渡して**、接点面と 1 番の側が両端で合うか | |
| D. 通電前の導通試験（**最終の門**） | 実装後・電池を入れる前に、テスターで **GND↔GND・3V3↔3V3 が導通、3V3↔GND が非導通、SCK が 595 の 11 番に着いている**ことを確かめる。**これが通るまで電源を入れない** | |

**2026-08-28 視点 B の結果 → 同夜に設計を直した**（[open-gaps #19](open-gaps.md)）。J_DB の口を奥向きに回し、
経路は J_DB → J_MAIN の直線。**A タイプで正しい。**J_DB のピン番号は J_MAIN の鏡像（13−n）。
✅ 2026-08-30 右も引き直し済み・右 J_DB は 1.63mm 手前。3 基板とも DRC 0。

ひねり（180°）は「接点面の反転 ＋ 1↔12 反転」を同時に起こすので、
B タイプの代用にはならない。実験で向きの種類を特定する用途だけ。

## 4c. ⚠️ ファームが 2 週間ビルドされていない（2026-09-01 発見）

**基板の発注はせき止めない**が、**板が届いてから焼けないと分かると痛い**ので書く。

**最後に CI が走ったのは 2026-08-16。**そのあと
`config/` `firmware/` に **10 コミット**入っているが、**一度もビルドされていない**。

| 何が入ったか | 規模 |
|---|---|
| `firmware/src/status_led.c` | **新規 560 行**（実機の LED インジケーター再現） |
| `firmware/Kconfig` | +29 行 |
| `firmware/CMakeLists.txt` | +5 行 |
| `hhkb_split_right.overlay` / `.conf` | 列割り当ての整理ほか |

**なぜ走っていないか**: `main` が origin より **138 コミット先行**していて、
**push されていない**（CLAUDE.md のとおり `config/` `firmware/` `build.yaml`
`zephyr/` を触った push だけが `.uf2` を作る）。

**手元でできること・できないこと**:

| | |
|---|---|
| ✅ 静的な整合 | `check_zmk_config.py` 問題なし（transform 61 箇所 × 4 レイヤー一致）。`test_firmware` / `test_keyscan` / `test_pinmap` **39 件緑** |
| ❌ **実際のコンパイル** | **手元に Zephyr SDK が無い**（CLAUDE.md）。**560 行の新規 C が通るかは未確認** |

**→ 板を発注する前後どこかで push して CI を通すこと。**
`.uf2` が出れば「焼ける」ことは確かめられる。**基板とは独立に進められる。**

## 4d. 検査に検出力があることを機械で確かめた（2026-09-01）

**「検査が緑」は「正しい」を意味しない。**通るだけの検査かもしれない。
`tools/mutate.py` は**定数を 1 つずつ故意に壊して、検査が気づくか**を測る。

    .venv/bin/python3 tools/mutate.py      # 遅い（数十分）

**結果: 検出 106 / 生存 0。**壊した 106 個すべてを検査が捕まえた。
**素通りする定数は 1 つも無い。**

個別にも、発注に効く誤りを故意に仕込んで赤になることを確認した:

| 壊したもの | 結果 |
|---|---|
| 595 の SH_CP ↔ ST_CP（SCK と CS の入れ替え） | **4 件赤** |
| マトリクスダイオードの K/A 逆転 | **4 件赤** |
| D_PWR の A/K 逆転（回路図側） | **子基板で赤** |
| 子基板のシルクを 1 本 0.12mm へ | **赤** |
| 子基板の `min_track_width` を 0.05 へ | **赤** |
| R-Space の x を 0.25u ずらす（キーの隙間） | **赤** |

**→ ピン配置・向き・製造規則のいずれも、壊れれば検査が止める。**

## 5. 実装する枚数を決める

**5 セット実装しても使い道が無い。**2 セットで 1 台分の予備が残る。
板は最低数量の 5 枚来るので、残りは未実装の予備になる。
約 ¥2,700 の差（[cost-estimate.md](cost-estimate.md)）。

## 8. 発注前の独立監査（2026-09-02・Fable 5 で 3 系統）

**「もう残っていない」と言うために、3 つの視点を別々の agent に読み取り
専用で回した。**結果は見つかったものだけを書く（通ったことは証拠にならない）。

### 8a. 電気（電源経路・電圧範囲・595・kscan・ADC・復旧）— **基板を作り直す欠陥なし**

外部事実と突き合わせたもの: SGM2040 データシート（LDO 出力への逆給電・
0.4µA 級）、ZMK `gpio_595.c`（MSB-first → `&shifter 8` = U2.Q0 = COL8）、
ZMK `battery.c`、TI SCASE93A のピン表。

| 見つかったもの | 基板に効くか | どうした |
|---|---|---|
| 打ち止め soft-off が ZMK の事象の出方（% が変わったときだけ）と噛み合わず、0% 張り付きで止まらない | **効かない**（ファーム） | [open-gaps #25b](open-gaps.md) 冒頭に記録。Task C4-4 の前に直す |
| 左 overlay の行対応の注記が実値と逆（行 0 以外全部） | **効かない**（板は実値から生成・DRC 0） | 注記に実値を追記。根拠は `circuit.py` 側 |
| D9（SPARE2）が xiao_spi の MISO として浮き入力のまま露出ビアまで伸びる | 効かない（µA 級の可能性のみ・記録済み） | 変更なし |

### 8b. JLCPCB の DFM（ガーバー・ドリル・BOM・CPL・在庫）— **受け付けられない項目なし**

Fabrication Toolkit の出力 3 枚を展開して数えた（Edge.Cuts 閉じている・
F_Paste 空・B_Paste = SMD パッド数・B_Cu/B_Mask/B_Paste のアパーチャ別個数
一致・NPTH 最小 1.75・ビア→板端 ≥0.60・外形外の穴 0）。部品 7 品番は
JLC API で在庫と区分を再確認（C88360 は **1,741** に減少中 → §2b）。

**発注ページで人が見ないと事故になりうるもの:**

| 何 | なぜ | どうする |
|---|---|---|
| PCBA 区分 | Standard だと板端 2.5mm・70×70mm に抵触 | **Economic** を選ぶ（§0 に足した） |
| **ソケット 61 個の CPL 座標が「パッド中心」ではなく「φ4.0 穴の中心」**（perigoso のフットプリントの原点）。パッド 2 枚の中心から約 **3.86mm** ずれている | JLC のライブラリ原点がソケット本体中心なら、プレビューでソケット像が 3.9mm ずれて出る。§0b の「export_fab と 134 点一致」は両方が同じ原点なので**検証にならない** | 「Confirm Parts Placement」のプレビューで**ソケット像がパッドに乗っているか**を見る。ずれていれば JLC のエンジニアにパッド基準で合わせてもらう（通常はそうする） |
| ソケットは F.Cu 置き・パッド B.Cu なので、裏面式 `180 − rot` に X 鏡像がかかっていない | パッドが非対称（(−7.085,−2.54)/(5.842,−5.08)）なので、向き違いは実装不能か誤実装 | §1 の目視に含める（同じプレビュー） |
| スタビ穴 φ3.988（NPTH）の縁が板端まで **0.381mm**（左右 2 穴ずつ） | 外形公差 ±0.2mm に対し薄い | **✅ 同日 #53 で解消**（スタビを 180° 回して 2.14mm） |
| 子基板のシルク文字が 0.8mm（参照記号 9 個・「USB」は線幅 0.12） | JLC 最小 1.0mm/0.15mm 未満。**かすれるだけで製造は止まらない** | 変えない（子基板は読めなくても困らない） |
| 右基板に 1 個だけ φ0.56 のビア（V3V3・(77.24, 89.22)、他 1,289 個は 0.6） | リング 0.13mm で JLC 最小は満たす。配線凍結時の名残 | 変えない |

### 8c. 機械・組立（干渉の網羅・板厚・取付穴・FFC・USB・スタビ・外形）— **要判断 1 件**

3 基板の全フットプリントが `pcb_parts.json` の STEP bbox で `gen_assembly`
に入っていること、ネジ頭 φ3.8 → 最寄りの裏面部品 1.10mm・頭の下は GND だけ、
FFC 口の直線距離 左 17.1／右 21.5mm（+SLACK 25 ≤ 80）、板厚 1.6 の一致、
角 R3.0 の一致、を数字で確認。

| 見つかったもの | 基板に効くか | どうした |
|---|---|---|
| **スペースのスタビ大穴の縁が板前縁まで 0.381mm**（8b と独立に同じ数字） | **効く。板を出してからでは直せない** | **✅ 同日決着**: 利用者が (b) を採用。スペースのスタビ 2 個を 180°（ワイヤ奥）に回し、縁まで 2.14mm。検査を足した → [open-gaps #53](open-gaps.md) |
| 左 J_DB が J_MAIN と X で 1.40mm ずれている（右は 0.00） | 効かない（コネクタの姿勢で吸収・組んで見る） | [open-gaps #54](open-gaps.md) |
| #19 節の「余り 26mm」「pad 1..12 が完全一致」は決着前の古い数字 | 効かない | #19 の本文は触っていない（数字は #54 と 8c に） |
| 未モデルのもの: 子基板裏の電池線パッドの半田盛り（床まで 4.0mm）・FFC の余り 33〜38mm の折り返し・スタビのクリップの板下 1.2mm（最寄り部品まで 2.08mm） | 効かない | 記録のみ |

### 8d. 物理適合を外部事実と照合（2026-09-02・4 系統目）— **板を作り直す欠陥なし・要判断 1 件は (a) で決着**

8a〜8c と #50/#53/#54 の**外**を探した。突き合わせた先は Cherry MX 規格・
Kailh 推奨ランド（parts-audit §8）・KiCad 公式 FP・Fabrication Toolkit の実コード・
JLC capabilities ページ。手元の生成物どうしの一致は数えていない。

| 見つかったもの | 基板に効くか | どうした |
|---|---|---|
| **子基板の電池線・スイッチ線のランド（`BT1_-`・`SW_PWR_1`）が SMD 2.0×2.0 のみ**（`gen_pcb.py` の `TestPoint_Pad_2.0x2.0mm`・スルーホール無し） | **穴は後から開けられない。**線を引っ張るとパッド剥離 | **✅ 2026-09-02 利用者が (a) を採用: このまま（SMD 2.0×2.0）。**組立時にリード線をケース側で固定して引っ張りを逃がす（組立手順に足す） |
| `pcb/hhkb_split_daughterboard.zip`（08-15 版・.gitignore 対象）が本番の隣に残っていた | 発注時に古い方を上げうる | **消した** |
| NPTH 穴縁 → GND ベタ 0.251mm（3 枚とも・左 SW25／右 H6／子 H1）。JLC 明記は「穴→配線 0.28」で NPTH→ベタは明記なし | ドリルが掠ってもベタなので機能は壊れない | 変えない。JLC が指摘したら「そのまま」 |
| シルクが銅・板端に掛かる 6 件（左 D12 が J_DB 金具上・ST27/ST32 が φ4 穴上・D24/D9/D31 が板端）。`--severity-all` で初めて見える | JLC がパッド上のシルクを自動で削る | 変えない（§1 の目視には影響なし） |

**問題なしを確認したもの（母数）**: ソケット FP 61 個の端子位置・パッド・
ホール間隔は Cherry/Kailh と 0.000（差は φ3.05/φ1.75 の +0.05 だけ）／
`PLATE_T 1.5 + PLATE_TO_PCB 3.5 = 5.0`（MX 規格）／SW 61 個の位置が layout と
0.0000・幅→FP 一致・回転 0°・取付穴 左 6 右 8 一致／スタビ FP は Cherry と最大
0.038mm・4 個とも SW 中心・プレートと基板が同じ `stab_flipped()` を読む／
板厚 3 枚 1.6／DRC 全重要度で error 0（warning は #50・#49・上表のシルクのみ）／
外形 1 輪郭閉・銅は Edge.Cuts 無し・ビア in パッド 0・最小パッド間隔 0.20（FFC）。
**見ていないもの**: Kailh の一次 PDF（404）・JLC の NPTH→銅の明示値。
実形状の干渉検査（`nothing_bites`）は #53 の反転後に左右とも通過（18 分）。

**#50 の補足**: JLC の表の「Via Hole-to-Hole 0.2mm」は φ0.3 ビアで中心どうしなら
成立しない → 表は**縁どうし**。0.4398 は本当に 0.01 不足。ただし製造前に
連絡が来る類で、**発注後に直せない誤りではない**。

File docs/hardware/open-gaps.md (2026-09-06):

# 実機とまだ違うところ

**差があること自体は必ずしも悪くない。悪いのは、差があるのに気づけないこと。**

この案件では「要求を守っているように見えて、守っていない値」を固定した
テストが 2 つあり、どちらも利用者の問いかけで初めて分かった。

- `PLATE_TOP_FRONT == 17.5` — 実機の**ベゼル**高さをプレート面と取り違えていた。
  全段のキートップが 3.5mm 高かった
- `test_keytop_heights_match_the_real_machine` — 参照モデルを検査しており、
  **設計そのものは検査していなかった**

以後、実機と違うところはここに書く。
[tools/test_invariants.py](../../tools/test_invariants.py) が、この表と
設計値がずれたら落ちるようにしてある。差が無くなったら行を消す。

---

## いま残っているもの（2026-08-11 に棚卸し）

**この節が無かったせいで、#1・#8・#17 は解決済みなのに 4 日間
「未解決」として残っていた。**#1 に至っては、古い主張のほうを検査が
固定していた。**節を書き換える人と、一覧を見る人が別人になる。**

### ★ 発注をせき止めているもの

| # | 何 | 次の一手 |
|---|---|---|
| ~~**#23**~~ | ~~アンテナが地板に挟まれている~~ **✅ 2026-08-23 決着。**利用者が手 0（アルミ箔で地板を模擬・¥0・当日）で実測。**E の差 −7dB で、判定基準の 20dB を大きく下回る**（A のふらつき幅 7dB と同じ大きさ）。共振も起きていない（40/80mm が完全に同値）→ `FFC_LENGTH = 80mm` を決め打ちにできる。`export_fab.py` の門も開いた（「### 承知して発注する」）。→ [実測結果](#アンテナの実測結果2026-08-23) | **無し**（組み上げてから §6-6 で測り直す） |
| ~~[#30](#-未解決-メスがケースの外へ-026mm-はみ出す23-と一体2026-08-11)~~ | ~~メスが 0.26mm はみ出す~~ | **#23 と一体だったので一緒に消えた** |
| ~~**#53**~~ | ~~スペースのスタビ大穴の縁が基板前縁まで 0.381mm~~ **✅ 2026-09-02 決着。**利用者「b を採用して」。左 ST27・右 ST32 を 180° 回した（ワイヤ奥）。小穴が手前に来て縁まで **2.14mm**。3 基板 DRC 0・警告数不変。`test_every_hole_keeps_its_distance_from_the_board_edge`（NPTH の縁 ≥1.0mm）を足し、回す前の板で 0.381 を検出することを確かめた。プレート開口・ネジ探索も `interface.stab_flipped` を見る | 無し |
| ~~#53（旧・2026-09-02 の (b) で決着。上の行）~~ | ~~スペースのスタビ大穴（φ3.988・NPTH）の縁が基板前縁まで 0.381mm~~（2026-09-02・監査 2 系統が独立に検出）。左 ST27・右 ST32 の 2 穴ずつ。JLC の外形公差 ±0.2mm を引くと **最悪 0.18mm の FR4 の橋**で、そこにスタビのクリップが力を掛ける。他の穴はすべて ≥2.4mm。**3u のときから同じ**（穴の y は段で決まる）で、2.75u 化の回帰ではない。→ [#53](#53-2026-09-02-スペースのスタビ大穴が基板前縁まで-0381mm) | ~~発注前に利用者が決める~~ **→ (b) に決めた（上の行）。**当時の選択肢: (a) 承知して出す（欠けたら手直し）／(b) 最下段のスタビ 2 個だけ 180° 回す（大穴が奥へ行き、縁まで 2.09mm。多くの基板でスペースのスタビは「ワイヤ奥」で、これが普通）——プレート開口・組立検査・スタビの実体も一緒に回す必要あり |
| ~~**#52**~~（旧 #42） | **✅ 2026-09-03 決着。**発注ページの 3D 配置プレビュー（Bottom）で左 D1・子基板 D_PWR・U1・J_DB・J_MAIN を目視し、pcbnew で読んだパッド座標と全部一致（[fab-checklist §1](fab-checklist.md)）。「+」マークは Pin 1 ではなく**アノード**を指していた。左＋子基板をカートへ。<br>（元の記録）**D_PWR（ショットキー B5819W・SOD-123）の実装向きが JLCPCB の配置プレビューで疑わしい**（2026-08-16）。⚠️ **GND スタブの #42 と番号が衝突していたので 2026-08-24 に #52 へ改番**（中身は不変）。KiCad 側（回路定義・pinmap・3D モデル）は「カソード＝V3V3 側」で一貫しているが、**JLCPCB がその意図をどちらの物理向きで実装するかは検証できていない**。JLCPCB の配置プレビューで「+」マークが出るが、Pin 1 を指すのかは未確定（ツールチップ等の裏付けが無い）。matthewlai/JLCKicadTools の Issue #28 で「同じ SOD パッケージでも LCSC 品番によって向きが違う」既知の限界が報告されている。⚠️ **この基板は `tools/export_fab.py` を使わず、別の KiCad プラグインで BOM/CPL/ガーバーを作る運用。**このリポジトリの `export_fab_rotation.py` を直しても実際の発注ファイルには反映されない（2026-08-16、`ROTATION_DB` に `D_SOD-123: 180` を一度足して検証したが、運用と合わないため revert 済み）。**2026-08-30 追記: 対象は D_PWR 1 個ではなく 62 個。**マトリクスのダイオード BAT46W（C54110）も**同じ SOD-123**で、フットプリントも同じ `D_SOD-123`（パッド 1=K の向きも同一。回転だけ違う）。→ **配置プレビューでどれか 1 個の向きが読めれば、62 個すべてに同じ結論が使える。**逆向きなら D_PWR は電池が使えず、マトリクスは**キーが 1 つも入らない**。⚠️ **`export_fab.py` は 2026-08-30 まで、この 62 個について警告を 1 つも出していなかった**（`ROTATION_UNVERIFIED` に Hirose と Kailh しか無く、`D_SOD-123` が漏れていた）。**記録は「目視せよ」と書いてあるのに、発注時に読む道具の側が黙っていた。**足した（運用が別プラグインである以上、出力は変わらない。**目に入る場所に出すためだけ**の変更） | **発注前に必ず**: (a) 使っているプラグインの発注ページ配置プレビューで D_PWR を目視し、配線を辿ってカソード（+マーク側）が V3V3 側に来ているか確認する、(b) 確信が持てなければ JLCPCB サポートへ「D_PWR（LCSC C7420330・SOD-123）の Pin1（カソード）はどちら向きになるか」を問い合わせる、または (c) 同ロットで安価な単体ダイオードを先に少量発注し実測する |

### シルクの線幅 — **✅ 2026-08-31 に子基板も直した**

**子基板のシルク 23 本が 0.12mm のまま出ていた**（KiCad 標準。JLCPCB の
最小は 0.15mm で、細いと**かすれるか印字されない**）。
対象は D_PWR / R_HI / R_LO / J_MAIN / BT1_- / SW_PWR_1。

**原因**: `gen_pcb.py` には「部品を置き終えたあとにシルクを太らせる」
処理があるが、**`gen_daughterboard.py` には無かった**。片方だけ直して
もう片方を忘れた形。

**なぜ今まで気づかなかったか**: `test_the_silkscreen_is_thick_enough_to_print`
が **`["left", "right"]` しか見ていなかった**。
CLAUDE.md「**検査対象に入っていない部品は、検査していないのと同じ**」。

**対応**: 生成器に処理を足し、本番の子基板（2026-08-22 の autoroute 由来・
配線は凍結）はシルクだけその場で太らせた。検査は 3 枚とも見るようにした
（**故意に 1 本 0.12 に戻すと落ちることを確認**）。

⚠️ **副作用として `silk_overlap` が 1 件出た**（D_PWR の名札と自分の外形が
0.1423mm・規定 0.15mm）。**同じ部品どうしなので読み違えは起きない。**
印字されないより良いと判断した。

### 本体基板の配線 — **✅ 2026-08-23 に決着（#46 のファームも済んでいた）**

**左右とも 違反 0 / 未配線 0 / dangling 0 / isolated_copper 0。**
子基板も 0。`CLAUDE.md` の「3 基板とも DRC 0」が事実に戻った。

| # | 何 | 次の一手 |
|---|---|---|
| ~~**#48**~~ | ~~COL → U1/U2 を表面のレーンで戻す~~ **✅ 2026-08-23 完了。**利用者が扇形を含めて手で引き、私が写して再現できるようにした（`pcb/matrix_routing.json` ← `export_matrix_routing.py`）。**左右とも 完全な順序・間隔 0.95mm 均一・エラー 0 / 未配線 0 / dangling 0。**⚠️ **右は昇順、左は降順**（U1 のパッドの並びが鏡像だから）。⚠️ **私の判定は 2 回壊した**——ビアも枝も「端点しか見ない」判定で経路を落とした。**KiCad は端点どうしの接触しか数えないが、電気は線の途中でも繋がる。**最終的に**加工の判定は書かず、利用者が板から消したものを写すだけ**にした | **無し** |
| ~~**#47**~~ | ~~本番の `pcb/` を作り直していない~~ **✅ 2026-08-23 完了。**`tools/finalize_pcb.py` を書いた（`pcb/matrix_only/` → `pcb/` ＋ GND ビア。**Freerouting は通さない**——配線は確定済み）。**3 基板とも 違反 0 / 未配線 0 / isolated_copper 0。**⚠️ **プロジェクトファイルも一緒に運ぶ**（DRC は隣の `.kicad_pro` から規則を読む）。⚠️ **板を出すと `pcb_parts.json` / `pcb_product_groups.json` が古くなる**ので、続けて `pcb_parts.py --write` と `--write-groups` を回すこと | **無し** |
| ~~**#46**~~ | ~~最下段の列の割り当てが物理位置と合っていない~~ **✅ 2026-08-17 に修正済みだった（この一覧だけが古かった。2026-08-23 に棚卸しで発見）。**左は利用者の指定どおり `RC(4,0) RC(4,1) RC(4,3)`（コミット 25d9168。私の案 COL1/2/4 より良い——「一番左のキーに一番左の列」の素直さ）。右も「行内の順番＝列番号」＋ SW33/34 例外で修正済み（コミット 3be9698）。配線も dtsi に合わせて引き直し済み（#48）。`test_keyscan / test_firmware / test_pinmap` 39 件緑を確認。<br>（元の記録）最下段の列の割り当てが物理位置と合っていない（2026-08-17・利用者「本当に、SW26 が COL3 であるべきだと思う？」）。`hhkb_split.dtsi` の `RC(4,1) RC(4,3) RC(4,5)` は、**キーの真上を通らない列**を選んでいる。実測（左）: Meta は範囲 47.6〜76.2 に **COL1/COL2** が通っているのに **COL3**(90.5) を指定。L-Space は COL4 なら中心とのずれ 4.76mm のところ **COL5** で 14.29mm。このため列のバスが最下段だけ長い横断になる。**⚠️ 私は当初「割り当ては妥当」と報告したが誤り**——コードと dtsi の一致しか見ておらず、**dtsi 自体（自分たちの生成物）が妥当かを見ていなかった**。最良は **COL1, COL2, COL4**（最大ずれ 16.67→14.29mm・合計 40.48→28.58mm）。Alt の 14.29mm はどう選んでも残る（配置由来） | **無し。**⚠️ **2026-08-31 に一覧を直した**——「次の一手」に古い作業（dtsi を `RC(4,1) RC(4,2) RC(4,4)` へ）が残っていたが、**その修正は 2026-08-17 のコミット 25d9168 で既に入っている**（いまの dtsi は左最下段 `RC(4,0) RC(4,1) RC(4,3)`＝利用者の指定どおり）。`test_keyscan / test_firmware / test_pinmap` **39 件緑**で firmware と板の一致も確認済み。**行の頭は「済」なのに次の一手だけ古いまま**という、この文書の冒頭が警告している状態そのものだった |
| ~~—~~ | ~~本番の right に 未配線 1・via_dangling 2 が出る~~ **✅ 2026-08-23 解消。**配線を全部手で引き直し（Freerouting を使わない）、`finalize_pcb.py` で本番へ出した結果、**3 基板とも 違反 0 / 未配線 0 / dangling 0**。原因（Freerouting の収束不足か DSN の制約か）は**追わずに済んだ**——自動配線そのものを使わなくなったため | **無し** |

### 物を買う・刷るまで進まないもの

**買う物は [shopping-list.md](shopping-list.md) に統合した**（2026-08-11。
型番・店・届いたら確かめることまで。**種類だけで買わない**）。

| # | 何 | 要るもの |
|---|---|---|
| [#11](#11-公差が一律-02mmクーポンは用意した刷るのが残り) | 公差 `CLEARANCE` | クーポンを 1 枚刷る |
| **[#55](#55-2026-09-02-右にトラックボールpmw3610を付ける案b--d0-を-motion-に転用)** | 右にトラックボール（PMW3610）を付けるなら 3 本目の GPIO をどこから出すか。**B 案（右の D0 を MOTION に転用・電池は nRF 内蔵の VDD 測定）で進める方向**（2026-09-02・利用者） | **基板は左右・子基板とも変えない。**発注後、ブレッドボードで右の電流を実測してから ZMK 側（右の overlay）を組む |
| ~~[#12](#12-上ケースを奥で留める方法が未解決)~~ | **✅ 2026-09-05 設計で決着（案 A）。**上シェルは側壁を外から被るスカートで位置決めし、奥は**奥板の上縁リップ**が天井を押さえる。`test_the_rear_plate_locks_the_top_shell` が「押さえる」と「外せる」を両方見る。記録: decisions/2026-09-05-case-redesign-plan-a.md | 刷って組む |
| [#36](#36-重大-本体基板キーの基板に固定具が-1-つも無い) | 本体基板の固定（**2026-08-12 対応済み**。取付穴 左 6 / 右 8 ＋ プレート裏の柱と M2）。**電池箱も 2026-09-05 に締結へ**（箱の床の穴 2 個から仕切り壁へ M2×2） | **刷って組み、基板が締まるか見るだけ。**DRC は 3 基板とも 0/0 |
| [#35](#35-重大-電池蓋が外から開かない電池交換のたびに分解することになる) | 電池蓋の着脱。**2026-09-05 に作り直し（案 A）**: スライド＋ビードをやめ、**奥板を M2×2** で上シェルの桟へ。データシートで箱は**上面から入れる樋型**と判明し、横倒しにして開口を奥へ向けた | 刷って着脱を確かめる |
| [#18](#18-電源スイッチの実部品が未選定調査済み購入待ち) | 電源スイッチ（**2026-08-12 に品番確定**。SS12D01G4-G／秋月 112723） | 買ってノギスで `SW_PWR_*` を実測値に入れ替える |
| ~~[#19](#19-ffc-ケーブルの向き2026-08-16-決着a-タイプ80mm)~~ | **✅ 2026-08-30 決着。**J_DB の口を奥向きに回し（A タイプで正しい）、右 J_DB を 1.63mm 手前へ、左右の配線と露出ビアを引き直し。**3 基板とも DRC 0・検査 460 緑。**露出ビアも左右全ネット | **無し** |
| [#21](#21-一部未解決-キーキャップ下-3-段-dsa--上-2-段は背の高いもの品番未特定) | 上 2 段のキャップ | **候補調査済み（2026-08-11）。**±0.3mm 内で確定できる品は無し。**SP の SA Row 1/2/3 を各 1 個（$3×3）買って実測**が最短 |
| [#22](#22--2026-08-11-決定-本番の電池は一直線型のボックスbh-325-1a150) | 電池ボックス | **品番は決めた**（BH-325-1A150）。買って測る |
| [#25](#25-ブレッドボードのチャタリング本番基板では未確認) | チャタリング | 本番基板で再現するか |
| [#27](#27-ソケットは入る隙間-013mm-で入らないは保守平面の誤読だった2026-08-11) | **ソケット（普通のメス 1×7 × 4 本）** | **プロトタイプ期はソケット**（2026-08-12・利用者が承知で決定。アンテナ 0.72mm を許容）。買って座高を測り `DB_SOCKET_SEAT` に入れる。**脱プロトタイプで 0 に戻し、ケースを刷り直す** |
| [#28 残](#まだ残っていること) | 公差・片持ち・組み立ての順番 | 刷って組む |
| — | [provisional-values.md](provisional-values.md) の暫定値 | 上の全部の合流点 |

### まだ決めていない判断（物が要らないもの・要るもの）

**ここは「買う・刷る」の一覧に入らないので、抜け落ちやすい。**

| # | 決めること | いつ決まるか |
|---|---|---|
| ~~[#23](#23-未解決-アンテナが地板に挟まれている発注前に必ず読む)~~ | ~~案 C のまま／案 A／案 B のどれにするか~~ **✅ 2026-08-23 決着: 案 C のまま**（手 0 の実測で E の差 −7dB・共振なし。冒頭の ★ 表と `export_fab.py` の門「承知して発注する」に記録） | **無し** |
| ~~#12~~ | ✅ 2026-09-05 決着（上の一覧） | — |
| ~~[#44](#44-2026-08-16-深いスリープ中は電源を切ってもすぐには切れないバルクコンデンサの電荷)~~ | ~~深いスリープ中に電源を OFF→ON してもリセットされない（53 秒）~~ | **✅ 2026-08-16 決着。バルクコンデンサ C_BULK を削除した**（実測で「守る相手が存在しない」と判明）。待ち時間は**数秒**になり、**部品も 2 個減った**。[decisions/2026-08-16-remove-bulk-cap.md](decisions/2026-08-16-remove-bulk-cap.md)。⚠️ **消したのはバルクだけ**（役割が別）。**残り: 実機で待ち時間を再測定する**（¥0） |
| ~~**#45**~~ | ~~子基板のパスコン `C_DB` は誰を守っているのか~~ | **✅ 2026-08-16 決着。`C_DB` を削除した。****負荷の直近にいないパスコンだった**——3V3 の負荷は 2 つとも子基板の外にいて（XIAO 内部の nRF52840・主基板の 595）、どちらも自分の直近に別のパスコンを持っていた（内蔵 2.2µF ×5・C_U1/C_U2 で分流 58:1）。**部品がさらに 2 個減り、子基板のコンデンサは 0 個になった。**[decisions/2026-08-16-cdb-has-no-local-load.md](decisions/2026-08-16-cdb-has-no-local-load.md)。**残りは無い**（DRC 0/0/0・検査あり） |
| ~~[#49](#49-2026-08-23-配線にオシロを当てるつもりだったが当てられない)~~ | **✅ 2026-08-30 決着。**左右とも SCK/MOSI/CS/V3V3/SPARE/SPARE2/GND（右は U1_U2 も）を**既存ビアの露出**で用意。部品ゼロ | **無し** |
| **[#50](#50-2026-08-23-hole_to_hole-61-件--規定は自前の値が厳しすぎた) 🔴 発注時** | **`hole_to_hole` が JLCPCB 公式値 0.45mm を 0.0097mm 下回る**（実測 0.4398mm・左 27 / 右 34 ＝ キーの数だけ）。Kailh ホットスワップのフットプリント内部で、5 ピン用の穴 φ1.75 とソケット穴 φ3.05 が近い。**穴は残す**（5→3 は切れるが 3→5 は作れない） | **こちらでやることは無い**（自前の過剰な値 0.50 は 0.45 へ直した。3 枚とも規則を揃えたことを故意に壊して確認済み）。**残るは JLCPCB の判定待ち**——公式値が縁どうしか中心どうしかは明示が無く、**中心どうしなら 6 倍の余裕でそもそも問題なし**。縁どうしでも**最悪で発注が数日遅れるだけ**（製造前に連絡が来る） |
| **[#43](#43-2026-08-16-実機の-led-インジケーターが部品表にもケースにも無い)** | **実機の LED を外からどう見せるか**（上ケースの窓／導光／前面に外付け）。ファームは 2026-08-16 に実装済みだが、**XIAO 基板上の LED はケースの中で見えない** | ~~実機の LED の位置を実測してから（¥0）。外付けにするなら基板に影響するので、発注前に方針だけ決める~~ **✅ 2026-08-24 に方針決定（下の「承知した差」の行）: XIAO 直上のコブ上面に小窓・部品追加なし → 基板には影響しない。**窓の実装はケースの改善サイクルで |
| ~~**#51**~~ | ~~プリンタが A1 mini に変わったら右の大物 3 点をどう刷るか~~ **✅ 2026-08-24 決着。左右とも同一断面（余白 3.125・隙間 0.9・ベゼル壁 1.2・側壁 2.4）で、幅は 左 144.4 / 右 177.7mm。**右 177.7 はベッド端の試し板（177.6）で実測済み。左のスイッチ帯は受け箱の壁 1.6→1.2 と蓋の口の逃げ 0.5→0.3 で確保（蓋の掛かり代は無傷）。アンテナ・電池の要件は実測 D'/D''（8.5/5mm で RSSI 変化なし）で 10→5mm に。右の J_DB 周り 9 ネットは利用者が引き直し、**3 基板とも DRC 0/0**。経緯は [a1-mini-feasibility.md](a1-mini-feasibility.md)。⚠️ 残タスク: C_U2→U2 の銅距離 7.11mm > 上限 6.0（利用者が C_U2 を約 1.2mm 寄せる）・試し刷りでベゼル壁 1.2 の剛性確認（発注前） | **試し刷り（topcase_right 印刷中）と C_U2 の 1.2mm** |
| **[#33](#33-寒いと電池が残っていても起動しないかもしれない未試験)** | 打ち止めを温度で補正するか | **未試験。**冷蔵庫で測れる（¥0）。基板に影響しない。測ったら `BOOT_MARGIN` に反映（#34 は 2026-08-11 に決定: 打ち止め＝max(維持, 起動)・値 2.40V 維持） |
| ~~[#41](#41-2026-08-14-電源まわりを作り直した残りは左の未配線-2-本)~~ | ~~左の未配線 2 本を塞ぐか~~ **✅ 2026-08-23 の全面引き直し（#48/#47）で消えていた**——現 DRC 記録は左 違反 0・未配線 0（2026-08-24 の棚卸しで確認。この行だけが古かった） | **無し** |
| ~~[#23](#23-未解決-アンテナが地板に挟まれている発注前に必ず読む) の前提~~ | ~~幾何の証明が無効・手 0 の価値は残る~~ **✅ 2026-08-23 に手 0 を実測して #23 ごと決着**（E の差 −7dB。冒頭の ★ 表を参照） | **無し**（組んでから §6-6 で測り直すだけ） |
| ~~[#42](#42-2026-08-15-gnd-のスタブが-bcu-決め打ちで-smd-パッドに触れていない)~~ | ~~GND のスタブが SMD パッドに触れていない~~ **✅ 2026-08-24 決着。前提が動いていた**——2026-08-23 の作り直しで配線は利用者の手引きを写すだけになり（#47/#48）、`gnd_fanout.place` は本番経路から外れた。実測: **11 パッド全部が同層（B.Cu）スタブで GND ビアへ直結**（左 C_U1 は 2 節経由）。「層ごとに探索する設計」は**作る必要が無くなった**。再発は新検査 `test_every_ground_pad_has_a_stub_to_a_via_on_its_own_layer` が見張る（既存の plane 検査は「3mm 以内にビア」しか見ず #42 の型を捕まえられない。故意にスタブを消して赤を確認済み） | **無し** |

### 受け入れた差（塞がない。忘れないために残す）

| # | 何 | なぜ |
|---|---|---|
| [#2](#2-奥行コブが実機より深い) | 奥行 +5.1mm | ホットスワップをやめれば戻るが、交渉可能事項を捨てることになる |
| [#20](#20-電源スイッチが実機と違う形式機能位置) | 電源スイッチの形式・位置 | 機能が違う（機械的に切る vs ソフト電源） |
| [#24](#24-押した瞬間の-1-回だけ列が全部-high-のまま走査されるzmk-の実装) | ISR で 1 回だけ全 High | 実測で実害なしを確認済み。記録のみ |
| [#26](#26-片方が居ないともう片方が探し続けて電池を食う) | 片側不在時 3.7mA | **安く直せる方法が無い**ことを確かめた（ZMK 本体の 1 行で、Kconfig が無い） |
| #51 | **外形の幅が実機より片側 1.0mm 内側**（余白 4.125→3.125・左右とも） | A1 mini（ベッド 180mm）に右ケースを入れるため。キャップ周りの見える隙間 1.225mm は実機実測 1.0〜1.5 の範囲内 |
| #43 | **LED の位置は実機（右端から 61mm・上端から 6mm・2026-08-24 実測）を再現しない** | 左右分割の時点で位置まで揃える理由がない（利用者 2026-08-24）。**XIAO 直上のコブ上面に小窓**（左右対称・部品追加なし）で見せる方式に決定。**窓は同日 f94a2ca で実装済み**（皮 0.6mm・φ5）。残るは刷って透けるかを見るだけ |

### ファーム（基板に影響しない。**CI でビルド成功・実機未確認**）

| # | 何 | 状態 |
|---|---|---|
| [#13](#13-一部未解決-電池残量の が乾電池に合っていない) | 乾電池の残量% | 差し替えた。ただし入っているのは**線形の写像で、放電曲線ではない**（C4/C5 待ち）。副産物で、使っていない XIAO 内蔵分圧を毎回起こしていたのを止めた |
| [#25b](#25b-電池が尽きるときの止まり方ファームで直せる基板は関係ない) | 打ち止めでの安全な停止 | **コードは実装した（`zmk_pm_soft_off`）が、実機では一度も動かしていない。⚠️ 2026-09-02: ZMK は % が変わったときしか事象を出さないので、いまの実装では 0% 張り付きで止まらない（節の冒頭）。**手順を起こした → [Task C4-4](task-c4-c5-power.md)（LM2596S でできる・¥0） |

---

## 1. ✅ 2026-08-07 解決（手前端の高さ）— **閉じたのに 4 日間「未解決」として残っていた**

| 項目 | 設計 | 実機 | 差 |
|---|---|---|---|
| 手前端の高さ | **17.50mm**（組み上げた上ケースの前縁を実測） | 17mm と約 18mm の 2 件 | **その間。差なし** |

上ケース（ベゼル）を足し、プレートを 6.62mm 沈めることで閉じた。
経緯は [decisions/2026-08-07-top-case.md](decisions/2026-08-07-top-case.md)、
断面は `gen_case.build_topcase` の図。

**設計基準が 17.5 なのは、実機の一次資料が割れているから。**
Tom's Hardware の逐語が 17mm、別レビュー（blue-de）が約 18mm で、
その中間を採っている（[dimensions.md](dimensions.md)）。

### ⚠️ この節が 4 日間「未解決」のまま残っていたこと自体が、この案件の失敗の型

2026-08-07 に**この節が書いたとおりの手（ベゼルを立ててプレートを 6.62mm
沈める）で解決された**のに、節は「ベゼルが無い」と言い続けていた。
そして `test_front_edge_height` が

```
設計 PLATE_TOP_FRONT(10.88) < 実機 17.0 → 差が残っている
```

を**毎回緑で確認していた**。プレート面はもう手前端ではないのに、
検査は定数どうしを突き合わせていたので気づけない。
**「要求を守っているように見えて、守っていない値を固定したテスト」の
裏返し——「既に守っているのに、守っていないことを固定したテスト」。**

→ 検査は**組み上げた上ケースの実形状から前縁を測る**ように直した
（2026-08-11）。`BEZEL_TOP_FRONT` を 20 にすると落ちることを確認済み。

---

## 2. 奥行（コブが実機より深い）

| 項目 | 設計 | 実機 | 差 |
|---|---|---|---|
| 本体＋コブ | 125.1mm | 120.0mm | +5.1mm |

**原因**: MX ＋ ホットスワップソケットは、プレート上面からソケット下端まで
9.8mm ある。Topre は基板の下に出っ張りが無く、ここが 5mm 以上薄い。
単3×2 を収めるのに、実機の 12mm より深いコブが要る。

> **⚠️ コブ 18mm の根拠は保守値の連鎖（2026-08-11 追記）。**
> 「12/14/16 では電池が基板に食い込む」判定（`gen_case._BUMP_BASE`）の
> 入力には、ソケット深さ 3.2mm（**実物 2.005mm・+1.19mm 保守**）、
> `PLATE_TO_PCB` 3.5mm［暫定］、電池ボックス高さ 16.8mm［通販ページ値］が
> 入っている。**ノギス実測が揃ったら 16mm 以下が通るか再判定する**——
> 実機 +5.1mm の差を縮められる余地がある（基本方針「寸法は実機に
> 合わせる」に直接効く）。

**影響**: 机の占有面積。分割なので左右それぞれ 5mm 深くなる。

**塞ぐには**: ホットスワップをやめて直付けにすれば 3.2mm 戻る。
ただし打鍵感の調整という交渉可能事項を捨てることになる。**現状維持を推奨。**

---

# 領域を分けて見直して出たもの（2026-08-07）

「同じ失敗の型」だけを探していては見つからないものを、領域ごとに開いて探した。
**探しやすいところを探すのは検証ではない。**

## 3. 基板の設計規則が JLCPCB の能力に合わせてない ✅ 2026-08-07 解決

`.kicad_pcb` の `(setup)` に設計規則（クリアランス・線幅・アニュラリング・
最小穴）が**一つも設定されていない**。KiCad の既定値で DRC を通しているだけ。

**「DRC 違反 0 件」は「JLCPCB で製造できる」を意味していない。**

JLCPCB の 2 層/4 層の標準能力（最小線幅 0.127mm、最小クリアランス 0.127mm、
最小アニュラリング 0.13mm、最小ドリル 0.2mm、外形までの距離 0.2mm など）を
設計規則として書き込み、その規則で DRC を通す必要がある。

## 4. 子基板が電池から 1.0mm しか離れていない ✅ 2026-08-07 解決（12.2mm へ）

| | 電池の内側端 | 子基板の外側端 | 隙間 |
|---|---|---|---|
| 左 | +38.4mm | +39.5mm | **1.0mm** |
| 右 | −21.7mm | −38.9mm | 17.1mm |

XIAO のアンテナは USB と反対の端にある。**単3 電池は金属の塊で、2.4GHz の
アンテナを至近距離で大きく狂わせる。** 左右間の BLE 接続が本要件なのに、
その通信距離を自分で潰していた。

電池を寄せて場所を作った副作用。アンテナ側にどれだけ空けるべきかを
定数として持ち、検査すること。

## 5. 電池残量がファームウェアで読まれていない ✅ 2026-08-08 解決済みと確認

**この項目は古かった。**実装は入っている。

| | 場所 |
|---|---|
| `zmk,battery-voltage-divider` | `hhkb_split.dtsi`（`output-ohms` / `full-ohms`） |
| `chosen { zmk,battery = &vbatt; }` | 同上 |
| 左右間の残量取得 | `hhkb_split_left.conf`（FETCHING / PROXY） |
| ADC の取得時間 40µs | **ZMK の driver が設定**（500kΩ の分圧に必要な値） |

**残っているのは残量%の曲線だけ**で、それは #13 に分けてある
（ZMK の%はリチウムイオンの放電曲線。乾電池では正しい%にならない）。

## 6. デバウンスが未設定 ✅ 2026-08-08 解決済みと確認

**この項目も古かった。**左右とも設定されている。

```
CONFIG_ZMK_KSCAN_DEBOUNCE_PRESS_MS=3
CONFIG_ZMK_KSCAN_DEBOUNCE_RELEASE_MS=5
```

「数珠つなぎが速い打鍵を取りこぼす」懸念も **Task C2-b で実測して合格**
（SPI 4MHz。シフトレジスタは 74HC595 → **74LVC595** に変更済みで、
1.8V でも fclock 104MHz 保証なので余裕はさらに広い）。

## 7. 基板に左右の識別が無い ✅ 2026-08-07 解決

シルクに Left/Right の表示がゼロ。JLCPCB から 2 種類が届き、
見分けがつかない。組み立ても修理も取り違える。

---

# 未着手だった領域を一巡して出たもの（2026-08-07 その2）

幾何・電気・製造は見たが、**組立・保守・強度・公差は一度も見ていなかった。**

## 8. ✅ 2026-08-07 解決（取付ネジがキーキャップの下にある）— **#1 と同じく、閉じたのに残っていた**

当初: ネジ 14 本中 9 本がキーキャップ（18mm 角・隙間 1.05mm）の下にあり、
**ドライバーが入らなかった。**ボスの位置探索がプレートの開口（14mm 角）
しか避けておらず、キャップの 4mm 大きい外形を考えていなかった。

**#1 と同じ手（上ケースを足す）で同時に解けた。**ネジは
`MOUNT_Y = ±51.5` のベゼルの中へ移り、本数も 14 → **5 本**（本体 3・
子基板 2）になった。キャップの縁は ±47.1 なので、下に 1 本も無い。

守っている検査（[tools/test_topcase_geometry.py](../../tools/test_topcase_geometry.py)）:

| | |
|---|---|
| `test_a_screwdriver_reaches_the_screw` | キャップからネジ頭まで 2mm 以上 |
| `test_the_screw_head_fits_inside_the_bezel` | 頭が開口に掛からず、ケースの外にも出ない |
| `test_no_screw_sits_on_the_left_or_right_edge` | 左右の辺には置けないという前提を明示 |

## 9. RESET ボタンに手が届かない ✅ 2026-08-07 解決（キー操作で復旧）

ケースに RESET 用の穴が無い（`grep -c RESET tools/gen_case.py` → 0）。

XIAO はブートローダに入るのに **RESET を素早く 2 回**押す必要がある。
今日の Task C1 でも実際に使った。ファームウェアを壊したとき、
**ケースを開けないと復旧できない。**しかも開けるにはキーキャップを
外す必要がある（#8）。

**塞ぐには**: 子基板の脇に細穴（φ2、クリップが入る）を開けるか、
子基板に押しボタンを載せて底面から押せるようにする。

## 10. ネジボスが PLA 直ねじ込みで肉厚 1.65mm ✅ 2026-08-07 解決（熱圧入インサート φ5.6）

ボス φ5.0 / 下穴 φ1.7 → 肉厚 1.65mm。M2 をタッピングで直接ねじ込む前提。
**PLA は繰り返しの開け閉めで舐める。** 熱圧入インサート（外径 3.2mm）を
使うならボスは φ5.6 以上が要る。

## 11. 公差が一律 0.2mm（クーポンは用意した。刷るのが残り）

`CLEARANCE = 0.2` を蓋のレール・脚のピン・ナット・子基板・電源スイッチの
ポケットの全部に使っている。3Dプリントは穴が縮み、XY と Z で収縮量も違う。
**K1 Max ＋ PLA での実測が無い。**

**2026-08-08: クーポンを作った。**`tools/gen_testpieces.py` が
`build/clearance_coupon.stl`（76 × 34 × 4mm）を出す。

| | |
|---|---|
| 丸穴 | φ4.0（脚のピン相当） |
| 角穴 | 8.6 × 4.4mm（電源スイッチ相当） |
| 逃げ | 0.0 / 0.1 / 0.2 / 0.3 / 0.4mm を左から並べた |

**丸と角の両方を見る。**角は隅に材料が寄るので、同じ逃げでもきつくなる。
片方だけ見て決めると、もう片方で外す。

1 枚刷って「入るが緩くない」逃げを選び、`gen_case.CLEARANCE` に入れる。

---

# 根本原因: 「プレートが天板」という構造

**#1（ベゼルが無い）と #8（ネジがキャップの下）は同じ原因から出ている。**

いまの構造はプレートがそのままケースの天板。そのため

- 天板がキー面と同じ高さになり、実機のベゼル 5.2mm が再現できない（#1）
- 上から留めるしかなく、ネジがキー領域に入る（#8）

**上ケース（ベゼル）を足すと、両方同時に解ける。**

```
   いま                        上ケースを足すと
 ┌──────────┐              ┌─┐        ┌─┐
 │ プレート  │←ネジ(上から)  │ │プレート│ │ ←ベゼルが押さえる
 ├──────────┤              ├─┴────────┴─┤
 │ 基板      │              │ 基板        │
 │ ケース    │              │ ケース      │
 └──────────┘              └──────△─────┘
                                   ネジ(下から)
```

- ネジは**底から**上ケースへ通す。キー領域にネジが無くなる
- 手前端がベゼルの高さ 17mm になり、実機と一致する
- ネジ頭が底面に隠れ、見た目も実機に近づく

**ただし凍結境界（プレート寸法）を動かす。** 影響は
プレート・基板・取付穴・ケースの全部に及ぶ。判断が要る。

---

## 12. 上ケースを奥で留める方法が未解決

### 2026-08-12: 「材料が無い」は思い込みだった。庇を作って、外した

**この節は長らく「コブの上に材料が無いので溝を空中に切っていた」と
書いていたが、走査したら材料は在った。**上ケースの後端の真後ろ、
**z 28.82〜31.25 にコブの天井が張ってある**（y=53.56 から奥へ）。

そこで**天井を手前へ 3mm 伸ばして庇にし、上ケースの天面を欠き取って
潜らせる**設計を入れた。**噛みはした**——0.3mm 持ち上げると 42mm³ 当たる。

**しかし組み立てられなかった。**

| 動かし方 | 干渉 |
|---|---|
| 上へ 0.3 / 1.0 / 2.0mm | 42 / 340 / 764mm³ |
| 奥へ 0.5 / 1.0 / 2.0mm | 138 / 336 / 643mm³ |
| 後端の稜線で 1 / 2 / 3° 傾ける | 53 / 177 / 302mm³ |

**どの向きにも動かせない＝入れられない。**原因は、**上ケースが外形を
ケースと共有する「落とし込み蓋」で、平面方向の逃げが 0** だから。
**水平方向に噛む機構（庇・舌・溝）は、この形では原理的に入らない。**

→ **次に設計するのは「垂直に押し込んで噛むもの」**（ナットとチルト脚で
うまくいった返し／溝と同じ形）。上ケースの奥に下向きの返しを立て、
ケースのリムに溝を掘る。

> **「噛むか」と「組めるか」は別の検査。**この節が長く残ったのは、
> 噛みだけを見て**組み立ての可否を一度も見ていなかった**から
> （#35 の電池蓋とまったく同じ型）。

手前 3 本のネジは決まったが、**奥をどう留めるかが決まっていない。**

舌と溝で引っ掛ける案を実装したが、**噛まなかった。**
ケースは上が開いたトレイなので、コブの上に材料が無く、溝を空中に
切っていた。干渉検査は「当たらない」ことしか見ないので通ってしまい、
**噛み合いを直接見る検査**（舌の上下に材料があるか）が検出した。

**候補**

| 案 | 問題 |
|---|---|
| 側壁の内面にリブを出して引っ掛ける | 上ケースの外面に凹みが要る。抜き方向と噛み合わせの検討が要る |
| 奥にもネジ（底から） | 奥は電池と子基板で埋まっている |
| 磁石 | 部品が増えるが確実。ケースが樹脂なので相性は良い |
| 手前 3 本だけで留める | ベゼルの剛性次第。奥が浮くかは実物を刷らないと分からない |

**いまは手前 3 本だけ。** 実物を刷って奥が浮くかを確かめてから決める。
[task-b3](task-b3-print-and-compare.md) の確認項目に加えること。

---

## 13. ⚠️一部未解決⚠️ 電池残量の%が乾電池に合っていない

ZMK の残量%は**リチウムイオンの放電曲線**で計算される
（`app/src/battery.c` の `lithium_ion_mv_to_pct`: 3450mV 以下は 0%）。
乾電池 2 本（2.4〜3.3V）を入れると、**ほぼ常に 0%** と報告される。

### 2026-08-11: 差し替えた（**ただし曲線ではない**）

**このリポジトリ自身を ZMK のモジュールにした。**`zephyr/module.yml` が
あると、ZMK 公式の再利用ワークフローが
`-DZMK_EXTRA_MODULES=<リポジトリ直下>` を付けて拾う（確認済み）。

| | |
|---|---|
| 残量計 | [firmware/drivers/battery_alkaline.c](../../firmware/drivers/battery_alkaline.c)。compatible `hhkb,battery-alkaline` |
| 選び方 | `hhkb_split.dtsi` の `vbatt` と、左右の `.conf` の `..._FETCH_MODE_STATE_OF_CHARGE=y` |
| 0% | **2400mV**（`circuit.BATT_V_MIN`）＝ **この回路が動かなくなる電圧** |
| 100% | **3300mV**（`circuit.BATT_V_MAX`）＝ 新品アルカリの開路電圧 |

### ★ ここが残っている: 入っているのは**線形の写像**で、放電曲線ではない

**メーカーが公開しているアルカリの放電曲線はグラフだけ**で、数値表が無い
（Energizer E91 のデータシートを当たった）。**グラフを目で読んで数字にすると、
この案件で最も高くついた失敗の型そのもの**になるので、やらなかった。

いま主張しているのは 3 つだけ:

- **単調**（減り続ける。増えたように見えない）
- **0% ＝ 本当に使えなくなる電圧**（リチウム曲線のように、まだ使えるのに 0% にならない）
- **100% ＝ 新品**

**本物の曲線は Task C4/C5 の放電実測で置き換える。**軽負荷（実測 0.66mA）の
アルカリは終盤まで比較的なだらかに下がるので線形は悪い近似ではないが、
**「測っていない」ことは変わらない。**

> **✅ ビルドは通った**（2026-08-11・Actions の「Build ZMK firmware」で
> `hhkb_split_left` / `hhkb_split_right` とも成功）。**焼くには push →
> 2 分半 → `.uf2` を取得**という流れになる（手元に Zephyr SDK は無い）。
> **ただし実機ではまだ動かしていない。**確かめるのは Task C4/C5。
>
> 数字の出所が 1 つであることは `tools/test_firmware.py` が見張っている
> （dtsi の値 ↔ `circuit.py`。故意にずらして落ちることを確認済み）。

### 副産物: 使っていない XIAO 内蔵の分圧を、毎回起こしていた

差し替えたらビルドが落ちて分かった。

```
devicetree error: 'power-gpios' appears in /vbatt ... but is not declared
```

**`vbatt` はボード（`xiao_ble//zmk`）の同名ノードと合体していた。**
こちらは `io-channels` と抵抗値を上書きしていたが、**`power-gpios` は
上書きしていなかった。**P0.14 は **XIAO 内蔵**の分圧（AIN7）を有効に
するピンで、この設計は D0/AIN0 の**外付け** 1MΩ+1MΩ を常時つないでいる
ので要らない。それなのに ZMK は電池を測るたびに P0.14 を叩き、
driver の「容量が充電されるのを待つ」処理で **10ms 待って**いた。

`/delete-property/` で外した。**残量計を差し替えなければ、devicetree の
検査は通ってしまうので気づけなかった。**（電流を詰めている
[Task C3](task-c3-ble-split.md) の測定にも、60 秒ごとに 10ms の起床が
乗っていたことになる）

---

## 14. 電池コブに天井が無かった ✅ 2026-08-07 解決

内側のくり抜きを奥まで通していたため、**コブが上に開いたままで電池が
露出していた。** 本体側はプレートと上ケースが覆うが、コブの上には
何も載らないので、ケース自身が塞ぐ必要がある。

**「メッシュが水密」は「箱として閉じている」を意味しない。**
干渉検査も水密検査もこれを見つけられなかった。電池の真上に材料が
あるかを直接見る検査を足した。

---

## 15. 子基板の配線が未完 ✅ 2026-08-08 解決（違反 0 / 未配線 0）

基板そのものは生成できている（22 × 30mm、XIAO・FFC 12P・0.1µF・取付穴 2、
裏面に GND ベタ）。**配線が通っていない。**

  pcb/hhkb_split_daughterboard.kicad_pcb   違反 93 / 未配線 1

途中で潰した問題:

| | |
|---|---|
| ケーブルのピン順が配線の順序と逆 | 6 箇所短絡 → **順序を配線しやすい並びに変更**（左群は左列を y の大きい順、右群は右列を y の小さい順）。GND はベタで受けるので順序から外せる |
| ビアの向きが基板の縁側 | 全ネットの横枝が同じ y に並んで重なっていた |
| 外形と部品が 50mm ずれていた | `_rounded_rect_outline` が `gen_pcb.ORIGIN` を参照していた。**レンダリングが真っ黒（空）になって気づいた** |

**残っているのは FFC コネクタまわりの寸法調整。**
基板の手前端に寄せすぎていて、コネクタと配線が縁に掛かっている。

**解決した。** 最後まで残ったのは 3 つ。

| | |
|---|---|
| レーンの x が相対値のまま絶対座標に混ざっていた | 145.9mm の配線ができていた。DRC の「配線の長さ」が異常値で気づいた |
| 左右の振り分けを 0 と比較していた | 絶対座標の x は常に正なので、全ネットが右の群に入っていた |
| **FFC を裏面に置くと並びが鏡像になる** | 順序が逆でファンアウトが必ず交差する。**ケーブルのピン番号を鏡像に合わせて振り直した** |

ほかに、パスコンの配線が無ネットのパッド（5V）を貫いて短絡していたのと、
GND のパッドが「ベタの上にあるだけ」で未接続だったのを直した。

---

## 16. 本体基板の電子部品 ✅ 2026-08-08 解決（違反 0 / 未配線 0）

部品も配線も載った。3 基板すべて DRC 違反 0・未配線 0 で、
`tools/test_pcb.py` の `WIP_BOARDS` は空になった。

配線は手書きのコードをやめ、Freerouting に委ねた（`tools/autoroute.py`）。
手書きルータは衝突判定を持たず、任意のネット対を短絡させていて、
経路の調整では 0 にならなかった。経緯は
[配線を自動配線器に委ねる設計](../superpowers/specs/2026-08-08-pcb-autoroute-design.md)。

以下は経緯として残す。

### 置き場所が変わった

当初は**奥の帯**（10.3mm）に置く計画だった。しかし取付ボスを基板の外へ
出すために基板の前後を詰めた（`PCB_INSET_Y` 3.0 → 5.3）結果、
**奥の帯は 3.40mm になり、595 も FFC も入らなくなった。**

代わりに**段と段の間**を使う。

| | |
|---|---|
| 段の間隔 | 19.05mm |
| ソケットの占有 | 9.8mm |
| **空き帯** | **9.25mm × 全幅 が 4 本** |

全部品が入る（595 が 6.4mm、FFC 5.0mm、スライドスイッチ 5.0mm、
バルク 5.4mm、電池線ランド 4.0mm、0805 が 1.2mm）。
段の間に横向きに寝かせれば、長い部品も通る。

裏面はソケットとダイオードの実装面なので、**同じ面に置くのは理にかなう**
（JLCPCB の実装が片面で済み、費用も下がる）。

### 4 層は入った

  F.Cu    信号（**実際には自動配線後 0 本。空いている**）
  In1.Cu  GND ベタ（全面）。**信号は 1 本も通さない**（検査で担保）
  In2.Cu  行の引き回し・電源
  B.Cu    ソケット・ダイオード・行のバス・部品

自動配線の結果、信号は In2.Cu と B.Cu だけで足りた。**F.Cu は丸ごと
空いている。**4 層をやめられるという意味ではない（In1.Cu の GND ベタは
分割の 2.4GHz のために残す）が、今後部品が増えても入る余地がある。

### 進捗

| | |
|---|---|
| 段の間に部品を置く | ✅ 完了。`PENDING` は空になった |
| 4 層化・GND ベタ | ✅ 完了 |
| GND をベタで受ける | ✅ 各パッドの脇にビア |
| 595 の出力 → 列 | ✅ In2 経由でビアへ |
| 電源・SPI・行 | ⚠ 結線したがレーンが重なる |

  左 違反 25 / 未配線 5
  右 違反 47 / 未配線 6

**未完の基板は `tools/test_pcb.py` の `WIP_BOARDS` に明示してある。**
DRC の検査から外すなら、外していることが見えていなければならない
（偽の緑を出さないため）。`test_the_unfinished_boards_are_declared` が、
綺麗になったのにリストへ残っている状態も検出する。

### 残っている手順（内訳まで特定済み）

| # | 内容 | 件数 |
|---|---|---|
| 1 | **行 5 本が未結線** — J_DB から各行のバスへ In2 で降ろす。ここが本命 | 未配線 5〜6 |
| 2 | GND のビアが表の列バスに当たる | 短絡 9 |
| 3 | In2 の配線がスイッチの非メッキ穴を通る（穴避けが要る。表・裏では実装済みだが内層は未対応） | 穴 8 |
| 4 | ビアと配線のクリアランス | 4 |
| 5 | U1 のコートヤードが SW8 と重なる（x を数 mm ずらす） | 2 |
| 6 | In2 のレーンどうしの交差 | 2 |

**どれも原因が特定できている。**あとは順に潰すだけ。

そのあと `WIP_BOARDS` を空にし、ガーバー・BOM・CPL を出す。

---

# 発注前に決めること（2026-08-08）

## 17. 電源スイッチに手が届かない ✅ 2026-08-08 解決（背面パネルへ）

`SW_PWR`（スライドスイッチ）は**帯 0 ＝ 段と段の間・基板の裏面**にある。
上はプレートとキーキャップ、下はケースの床。**ケースを開けないと操作できない。**

| 確認したこと | 結果 |
|---|---|
| `gen_case.py` に開口があるか | **無い** |
| 組み立て干渉検査が見ているか | **見ていない** |
| `PLACE` のコメント | 「手前の帯に電源。手が届く側に置く」と書いてあるが、実際は左右とも帯 0（奥）。**コメントが実態と食い違っている** |
| 実機はどうか | `reference-sources.md` の `97_03.jpg` が「**背面**。電池ボックス・電源スイッチ・USB 端子の位置」 |

**実機は背面にある。**この案件の揺らがせない方針は実機再現なので、
背面へ出すのが筋。

| 案 | 変更範囲 | 実機再現 |
|---|---|---|
| **A. 背面へ出す** | 基板 ＋ ケース | ◎ 電池のコブが背面なので隣に並ぶ |
| B. ケース床にスリット | ケースのみ | △ 入切のたび裏返す |
| C. スイッチ廃止 | 基板から削除 | ✗ 電池を抜く運用 |

### 決めたこと（2026-08-08）

**A を採り、基板側は電池ボックスと同じ「ランド 2 個＋配線」にした。**

基板の後端からケース背面まで **23.3mm** ある。基板の上のどこに置いても
背面には出せないので、**基板に載せるという前提自体が誤り**だった。
`SW_PWR` の種類を `wire_pads` にして、基板は `SW_PWR_1` / `SW_PWR_2` の
ランド 2 個で受ける。実物はケース背面のパネルに付けて配線で繋ぐ。

**部品はプッシュロック（オルタネート）の丸ボタン。**実機の
「電源／Bluetooth ペアリング」も丸いプッシュボタンで、見た目が揃う。
機械接点なので電池を本当に切り離せる（長期保管で漏れない）。
ケース側も丸穴 1 つで済む。

再発防止に `test_no_user_operated_part_is_sealed_inside` を足した。
**故意にスイッチを基板へ戻すと落ちる**ことを確認済み。

### 残っていること

- ~~**ケース背面の丸穴と、スイッチの当たり判定。**`gen_case.py` に開口はまだ無い~~
  → **✅ 実装済み**（[gen_case.py](../../tools/gen_case.py) の「受けの箱を足してから中身を抜く」）。
  受けの箱＋操作部のスロットが背面に開き、組み立て検査にも `sw_pwr` として
  入っている（#29 の表）。**故意に彫るのをやめると落ちる**ことも確認済み
- **残るのは買う部品だけ。**`SW_PWR_W/D/H` はまだ [暫定] で、
  実物のデータシート寸法を入れるまで開口の寸法は仮（→ #18）
### 背面に使える枠（実測・2026-08-08）

| | 使える幅 | 奥行（壁の内側から） |
|---|---|---|
| **左** | **10.6mm**（電池 x −70.6..+38.4 と子基板 x +49..+70 の間） | 15.6mm |
| 右 | 43.9mm | 15.6mm |

**左が律速。**電池はケース内寸に対して左端まで 0.2mm、子基板は右端まで
0.8mm しか余っておらず、**どちらもずらせない**。

**一般的な M8 パネル取付プッシュロックは入らない**（胴径 10mm・パネル裏
20〜25mm が多い）。買う前にこの枠（**10.6 × 15.6mm**）で確かめること。

> **⚠️ 奥行 15.6・高さ 15.5 は #22（電池ボックス化・2026-08-11）より前の
> 断面での実測（2026-08-11 追記）。**幅 10.6mm は `power_switch_x_center`
> の門が現在の幾何で毎回測り直すが、**奥行と高さは #22 後に再計算して
> いない。**候補（OS102011MA1QN1・8.6×4.4×4.7mm）は大差で内側なので
> 結論は動かない見込みだが、枠の数字を別の判断に使うときは測り直すこと。

## 18. 電源スイッチの実部品が未選定（調査済み・購入待ち）

> **✅ 2026-08-12 に決定した（SS12D01G4-G / 秋月 112723）。**見出しは
> 目次のリンクを壊さないために残している。詳細はこの節の中の決定枠。

### 調査で分かったこと（2026-08-08）

**市販のパネル取付（取付耳つき）スライドスイッチと、丸型オルタネート
プッシュスイッチには、この枠に入るものが無い。**

| | 実測 | 枠 | 判定 |
|---|---|---|---|
| 耳つきパネル取付スライド | 全高 16.2〜19.0mm | 15.5mm | 高さで不可 |
| 丸型プッシュロック（M8 級） | パネル裏 18.5mm 以上 | 15.6mm | 奥行で不可 |

**→ 耳を持たない超小型の基板実装用スライドスイッチを、3Dプリントの
ポケットへ落とし込んで固定する。**

> ### ✅ 2026-08-12 決定 **SS12D01G4-G（秋月 112723）**
>
> 利用者が決定。**突出量 4.0mm**（データシートの `L 4` と商品ページ
> 「操作部長さ 4mm」が一致）で、窪みの底までの壁 1.4mm を貫いて外へ
> **2.6mm** 出る。「2.8 説と 4.0 説で合否が分かれる」問題は消えた。
> 本体 8.8 × 3.9 × 3.5・端子 5.0mm・接触抵抗 30mΩ・¥30。
> **上から落とし込む溝**で受け、奥のリブが押し込み側を剛体で止める。
> 効く条件の一覧は [parts-audit.md](parts-audit.md) の 9 節。
>
> 以下は**決定に至るまでの調査**（当時の候補は C&K）。

候補（当時）: **C&K OS102011MA1QN1**（Digi-Key JP / RS JP・約 ¥120）。
[データシート](https://www.ckswitches.com/media/1428/os.pdf)で実測:

| | |
|---|---|
| 本体 | **8.60 × 4.40mm、奥行 約 4.70mm**（データシート I-42 の外形図）。枠 10.6 × 15.6 × 15.5mm に対し余る |
| ストローク | 2.00mm。ピン間 8.20mm |
| アクチュエータの向き | 外観図では**側面から出る右アングル型**に見える。**現物で確認する**（背面パネルへ真っ直ぐ出せるかが決まる） |
| 定格 | 0.1A @ 12VDC（負荷は 15mA。十分） |
| 接点抵抗 | 20mΩ 以下 |
| 寿命 | 10,000 回（1 日数回なら 10 年以上） |
| 端子 | PC マウント（スルーホール）。リード線を半田付けする |
| アクチュエータ | **黒** POM。ストローク 2.0mm |

### 接点は銀メッキ。金の標準品は無い（確認済み）

データシートの材質欄は「可動接点: 銅合金・**銀メッキまたは金**」
「固定接点: ブラス・**銀メッキ**」「端子: ブラス・銀メッキ（**金メッキは要問合せ**）」。

**掲載されている型番表に接点材質の選択欄は無い。**OS 系で挙がっている
型番はすべて標準品＝銀メッキで、金は特注（customer service 扱い）。
**つまり「金メッキの型番を選ぶ」という選択肢は無い。**

> **⚠️ 2026-08-12 訂正: 「金は入手不可」は言いすぎだった。**
> Würth **WS-SLTU 450302014072** は**接点・端子とも金メッキ**で
> Digi-Key / Mouser JP に在庫がある。ただし**つまみの突出が 1.4mm**
> しかなく、壁 2.4mm を貫けないので今回は使えない。
> **銀で受け入れる判断は変わらないが、「無い」ではなく「今回の
> 壁厚要求に合う金メッキ品が無い」が正しい。**

#### 何が心配なのか

3.0V・1mA 未満の微小電流ではアーク放電が起きない。アークは接点表面の
硫化膜を破壊して低抵抗を保つ働きがあるので、それが無いと硫化膜が
堆積し続け、数か月〜数年で接触不良になりうる。

#### なぜ受け入れるか

1. **スライドスイッチは動かすたびに接点を擦る**（セルフクリーニング）。
   定期的に入切する使い方なら膜が育ちにくい
2. **基板に載っていない。**リード線 2 本で繋がっているだけなので、
   劣化したら**基板に触らずスイッチだけ交換できる**。これが決め手

#### 実測で分かること・分からないこと

| | |
|---|---|
| 分かる | 新品の接触抵抗（20mΩ 以下のはず）。届いたらテスターで測る |
| **分からない** | **硫化膜による経年劣化。**数か月〜数年かかるので、立ち上げ試験では測れない |

（当初これを「Task C4 で実測する」と書いたが**誤り**。C4 は 1 回の
測定なので、経年劣化は原理的に測れない。上のとおり「交換できる」ことを
もって受け入れる。）

（なお外部の調査報告はこの部品を「金メッキ」と断定していたが、
データシートでは標準は銀だった。**報告は寸法の軸も取り違えており、
アクチュエータ色も誤っていた。**外部の情報も突き合わせること）

## 20. 電源スイッチが実機と違う（形式・機能・位置）

決定の経緯は
[decisions/2026-08-08-power-switch.md](decisions/2026-08-08-power-switch.md)。

| | 実機 | この設計 |
|---|---|---|
| 形式 | 丸いプッシュボタン | スライドスイッチ |
| 機能 | ソフト電源／Bluetooth ペアリング兼用 | 電池の機械的な切り離し |
| 位置 | 背面の左端 | 背面の空き（左は中央寄り、右は左寄り） |

**機能が違う以上、同じ部品にはできない。**こちらは電池を物理的に切るので
長期保管で減らない。実機はソフト電源なので待機電流が残る。

位置が違うのは、コブの中を電池（幅 109mm）と子基板が占めていて、
空きが左 10.6mm・右 43.9mm の場所にしか無いため。

**塞ぐには**: ペアリングを別のキー操作に割り当てたうえで、丸型の
オルタネートスイッチが入るよう電池か子基板を動かす。どちらも余裕が
1mm 未満なので、コブの寸法から見直すことになる。**現状維持を推奨。**

## 21. ⚠️一部未解決⚠️ キーキャップ（下 3 段 DSA ＋ 上 2 段は背の高いもの・品番未特定）

### 背の高いプロファイルは物理的に入らない（実測）

`CAP_H_HOME` を変えて組み立て検査を回した結果。

| プロファイル | `CAP_H_HOME` | `PLATE_TOP_FRONT` | 判定 |
|---|---|---|---|
| 実機（Topre） | 6.7 | 11.78 | OK |
| **DSA** | **7.6** | **10.88** | **OK** |
| XDA | 9.1 | 9.38 | **NG 基板と 230mm^3 食い込み** |
| Cherry | 9.4 | 9.08 | **NG 基板と 368mm^3 食い込み** |

背の高いキャップほどプレートが下がり、ケースが基板を噛む。
**Cherry と XDA は選べない。**

### DSA を選ぶ理由

| | |
|---|---|
| 収まる | 上表のとおり、入るのは DSA だけ |
| 実機に近い | ホーム段 7.6mm vs 実機 6.7mm。差 0.9mm で候補中いちばん近い |
| 入手性 | TALP が **3U スペースバーを 1 個単位で在庫**（黒/灰/白）。遊舎工房も DSA ブランクを 1 個単位で扱う |
| 費用 | **1 個単位で買える**ので、必要な数だけ。セット買いの余りが出ない |

**3.0u × 2（分割したスペースバー）が最大の調達リスク**だった。標準の
60% セットには入っていない。DSA なら 1 個単位で買える。

### 上 2 段だけ背の高いキャップを混ぜる（**2026-08-11・利用者の決定**）

DSA は**均一プロファイル**（全段 7.6mm）なので、下 3 段は実機とぴたり
合うが、上 2 段が **QWERTY −1.6mm / 数字段 −3.5mm** 低かった。
CLAUDE.md は「キートップの高さは実機に合わせる」としているので、
**上 2 段だけ背の高いキャップを混ぜる**ことにした。

| 段 | 実機 | 設計 | 差 |
|---|---|---|---|
| bottom | 26.7mm | 26.7mm | **+0.0mm** |
| ZXCV | 29.2mm | 29.2mm | **+0.0mm** |
| home | 31.6mm | 31.6mm | **+0.0mm** |
| QWERTY | 35.6mm | 35.6mm | **+0.0mm** |
| number | 40.0mm | 40.0mm | **+0.0mm** |

**この表は `test_our_design_actually_reaches_the_real_keytop_heights` が
設計値と突き合わせている。**ずれたら落ちる。

**ケースは変わらない。**ケースの高さを決めるのはホーム段だけ
（`PLATE_TOP_FRONT` は `OUR_CAPS["home"]` しか読まない）なので、
DSA 単一で作ったケースのまま、あとからキャップだけ足せる。

#### 検査が高さを見ていなかった（この変更で発覚・2026-08-11）

`gen_assembly` は 61 個のキャップを**すべて `OUR_CAPS["home"]` で
建てていた**。上 2 段を高くしても、**検査の中では高くならない**。
検証の作法 4 そのもの。`gen_case.cap_height(key)` を唯一の出所にし、
`key_stack_envelopes` がキーごとの高さを受け取るよう直した。

#### ★残っていること: 実在の品番が決まっていない

| | |
|---|---|
| いま入っている値 | QWERTY **9.16mm** / 数字段 **11.12mm** |
| その正体 | **実機のキートップ高さに一致させるのに要る高さ**を逆算した要求値。**製品の実測値ではない** |
| だから | 両方とも **[暫定]**。買う品を決めて実測したら差し替える（→ provisional-values.md） |

**買うときに効く条件（これを満たす品を探す）:**

1. **高さ**: 数字段 11.12mm ／ QWERTY 9.16mm（±0.3mm 程度なら差は表に出る）
2. **MX 十字ステム**・1u 中心。数字段は 1u ×13、QWERTY 段は 1u ×13＋1.5u
3. **1 個〜段単位で買える**こと（60% セットは段ごとに売られていない）
4. **天面の形が DSA と喧嘩しないこと**（DSA は球面天面。混ぜると見た目が
   ちぐはぐになる。これは受容すると決めた差）

**判断の材料**: `tools/gen_testpieces.py` が出す `height_gauge.stl` を
刷って実機の横に立てれば、段の高さの違いを手に取って比べられる。
**数値で悩まず、現物で決める。**

#### 候補調査の結果（2026-08-11。出典の種別つき）

**±0.3mm 内で「一次資料あり・買える」を両方満たす品は、両段とも見つからなかった。**

| 段 | 候補 | 公称高さ | 差 | 出典 | 買えるか |
|---|---|---|---|---|---|
| QWERTY 9.16 | XDA | 9.1mm | −0.06 | **二次のみ**（小売複数。公式図面なし） | Boardsource に 1u/1.5u ブランクあり・**現在売切れ** |
| QWERTY 9.16 | KAM | 9.05mm | −0.11 | 二次のみ | 単品売りの経路 **未確認** |
| 数字段 11.12 | **SA Row 1** | **11.73mm** | **+0.61** | **SP 公式図面**（SAFamily.pdf 0.462"） | **SP 直販で row 指定・1u $3.00／1.5u $3.50・単品可** |
| 数字段 11.12 | KAT R2 | 約 11mm | −0.12? | 「約」の二次のみ（公式は数値非公表・3D モデル配布のみ） | 単品経路 **未発見** |
| 数字段 11.12 | SA Row 2 | **未公表** | 不明 | どこにも数値なし | SP 直販で買える（$3） |

**罠を 1 つ踏む前に見つけた**: TALP の「XDA」ブランクは商品ページ実記載が
**約 8.5mm** で、XDA の通説 9.1mm と 0.6mm 違う。**プロファイル名でなく
SKU に書かれた高さで判断すること。**

**最短ルート**: SP 直販から **SA の Row 1 / Row 2 / Row 3 を各 1 個
（$3×3＋送料）買って実測する**。SA Row 2・Row 3 の高さはどこにも公表が
無いので、サンプル実測が唯一の確定手段。Row 2 が 10.8〜11.4mm に入れば、
**数字段・QWERTY 段とも SA 単品買いで完結**しうる（SP は 1.5u も row 指定
単品で買える＝条件 2・3 を満たす）。届いたら `height_gauge.stl` と並べて決める。

**未確認のまま残っているもの**: SP 図面の寸法の測定点（前縁か頂点か。傾いた
天面では ±1mm 級に効く。要問合せ）／SA Row 2・3 の高さ／XDA・KAM の一次資料／
KAT の単品入手経路。

### 他の道はあるか（検討済み）

| 案 | なぜ駄目か |
|---|---|
| Cherry / XDA / OEM / SA | 背が高すぎてケースが基板を噛む（上表） |
| ホーム段を 31.6mm より高くする | 実機再現の根幹を捨てることになる |
| ケースを作り直して背の高いキャップを許容 | 基板・電池・ソケットの積み重ねから来る制約なので、コブの寸法から見直しになる |

**ホーム段のキャップが 6.7〜7.6mm でないと成立しない**という強い制約が
あり、MX で選べる中では DSA がほぼ唯一。

### まだ確定していないこと

- `CAP_H_HOME = 7.6` は **DSA の公称値**。実物を測っていない。
  **しかも SP 公式図面（DSA 0.291"）は 7.39mm で、0.21mm 食い違う**
  （2026-08-11 の調査の副産物。図面に測定点の注記が無いのが原因かもしれない。
  実物を測ったら決着する）
- `CAP_LIFT = 6.2`（プレート上面→キャップ底面）は **MX の値として未検証**。
  規格として公表された数値を見つけられなかった
- ~~DSA の 1.5u / 1.75u / 2.25u が 1 個単位で買えるかは未確認~~ →
  **2026-09-02 確認済み。**SP 直販の [DSA Individual Keycaps](https://spkeyboards.com/collections/dsa-individual-keycaps)
  に 1u $3.00 / 1.5u $3.50 / 1.75u $3.50 / 2.25u $4.00 が単品・在庫ありで並び、
  [2.75u スペース](https://spkeyboards.com/products/sp-dsa-2-75-space) $4.00 も
  在庫あり（**外側の 2 本のマウントは中心から 0.469"＝11.9mm**。Cherry 2u
  スタビの ±11.938mm と一致）。下 3 段の全サイズ（1u ×51・1.5u ×4・1.75u ×2・
  2.25u ×2・2.75u ×2）が 1 店で揃う。在庫は製造余剰なので**色は買う時点で選ぶ**

**キーキャップを変えても基板とプレートは作り直しにならない。**
`PLATE_TOP_FRONT` を使うのは `gen_case.py` と `gen_assembly.py` だけで、
`gen_plate.py` も `gen_pcb.py` も参照していない（確認済み）。
**ケースを刷り直すだけ。**

## 22. ✅ 2026-08-11 決定 本番の電池は一直線型のボックス（BH-325-1A150）

### 何が起きたか

買い物リストに「電池ボックス 単3×2」とだけ書いたため、**横並び型
（2 本が横に並ぶ。58 × 32mm）**を購入することになった。
**コブの内寸は 15.6mm しかなく、入らない。**

原因は 2 つ重なっている。

1. **設計は「箱を使わない」**（裸の電池をケースが保持する）のに、
   買い物リストが「箱」を指定した。**突き合わせていなかった**
2. `provisional-values.md` が `AA_TERMINAL`（＝**電極バネ**の余裕）を
   「**電池ボックス**が届いたら測る」と書いていた。**定義と測定対象が
   食い違っていた**（2026-08-08 に修正）

**箱がその隙間に入るかを一度も計算していなかった**のが決定的だった。

### 選択肢

| | 買うもの | ケース | 奥行（実機 120mm） |
|---|---|---|---|
| A. 電極バネ | バネ接点 2 組 + リード線 | 変更なし | 125.1mm（+5.1） |
| **B. 一直線型ボックス** | **BH-325-1A150** | 断面 +1.1/+1.3mm | 125.1mm（**変わらず**） |
| C. 買った横並び型 | — | コブ +17mm | **142mm（+22）。却下** |

- **組み立てと公差が厳しいのは A**（小さなバネをプリント面に位置決めして
  接着し、細線を半田付けする。保持がプリント精度に依存する。
  しかも `CLEARANCE` は未実測 / #11）

### ✅ 決まった: B（2026-08-11・利用者の決定）

**買う品を実在の型番で確定させた。**

| | |
|---|---|
| 型番 | **BH-325-1A150**（Comfortable Electronic 製） |
| 買う場所 | 秋月電子 販売コード **110201**・**¥60** |
| 名前 | 電池ボックス 単3×2本 リード線・**たて一列** |
| 外形 | **109 × 16.6 × 16.8mm**（商品ページの記載。ノギスは届いてから） |

**探すのに手間取った点を残す。**「単3×2・リード線付」で売られている品の
ほとんどは**横並び（58 × 33mm）**で、これは却下済みの C そのもの。
Keystone のカタログにも一直線の 2 本用は無く（1 本用と横並びだけ）、
米国系の流通品では見つからなかった。**「たて一列」という日本語の
呼び方に当たって初めて出てきた。**

#### 効いた条件は、厚みではなく**長辺**だった

事前の見立ては「箱の厚みぶんコブが +1〜2.5mm」だったが、**支配的なのは
長辺**だった。背面の壁ぎわは電池と子基板でほぼ埋まっており、
**左半分に残る窓は 10.56mm しかない**（実測。電池は左端まで 0.20mm、
子基板は右端まで 0.80mm）。ここは電源スイッチ（#18）の置き場なので、
長辺が伸びるとまずここが潰れる。

| | |
|---|---|
| BH-325-1A150 の長辺 | **109.0mm** ＝ 裸の電池 2 本＋電極の占有と同じ |
| 窓 | **10.56mm のまま。1mm も食わない** |

Keystone の 1 本用（2461）を 2 個並べる案なら 114mm 級になり、窓は
5.6mm まで縮む。**同じ「一直線」でも、そこで決着が変わっていた。**

門番は `gen_case.power_switch_x_center`。窓が
`SW_PWR_W + CLEARANCE × 2` を割ると `RuntimeError` で止まる。

#### 断面はこう変わった

| | 前（裸の電池） | 後（箱） |
|---|---|---|
| 高さ | 15.5mm | **16.8mm** |
| 奥行 | 15.5mm | **16.6mm** |
| 占有空間の形 | 円柱 2 本＋電極の箱 | **直方体**（箱を買う以上、角は樹脂で埋まっている） |

買った横並び型は **Task C4 / C5 のブレッドボード検証にはそのまま使える。**

## アンテナの実測結果（2026-08-23）

**#23 はこの測定で決着した。**利用者が測定。

**条件**: 机・大きな金属は 30cm 以上離れている・`nRF Connect`・
XIAO とスマホの距離 30cm・USB 給電・XIAO 1 個・同じ日に連続して測定。

| # | 構成 | 最強 | 最弱 | A との差 |
|---|---|---|---|---|
| A | XIAO 単体 | −66 | −73 | **幅 7dB ← 判定の物差し** |
| B-3 | ＋リード線 160mm | −65 | −70 | +1dB |
| B-2 | ＋リード線 **80mm**（実物の長さ） | −63 | −66 | **+3dB** |
| B-1 | ＋リード線 40mm | −63 | −66 | **+3dB** |
| C-近 | ＋アルミ箔の板を垂直に立てて**数 mm** | −73 | −77 | **−7dB** |
| C-遠 | ＋同じ板を**約 2cm** | −70 | −73 | −4dB |
| **E** | **全部（C-近 ＋ リード線 80mm ＋ 電池 17mm）** | **−73** | **−77** | **−7dB** |
| F | 参考（真上 4mm） | 割愛 | | |

### 判定: **発注できる**

**判定表の「E の差が 20dB 以上 → 発注しない」に当てはまらない。**
**差は 7dB で、基準の 20dB を大きく下回る。**
⚠️ しかも **A のふらつき幅（7dB）とちょうど同じ大きさ。**

### 効いているのは地板だけ

| | 差 | |
|---|---|---|
| B（FFC を模擬したリード線） | **+3dB** | **効かない。むしろ強い側** |
| D（電池） | +1dB | **効かない** |
| **C（地板）** | **−7dB** | **これだけが効いている** |
| **E（全部）** | **−7dB** | **＝ C と同じ。**B・D を足しても変わらない |

### いちばん大きな未知だった「共振」は起きていない

    160mm  −65 〜 −70
     80mm  −63 〜 −66   ← **40mm と完全に同じ値**
     40mm  −63 〜 −66

**長さによる差は最大 4dB で、A のふらつき 7dB より小さい。**
⚠️ **「1 本だけ極端に悪い」という共振の典型的な現れ方が出ていない。**

→ **`FFC_LENGTH = 80mm` を設計で決め打ちにできる。**

⚠️ **B が +3dB（強い側）だったことの説明**: GND に繋がった導体が
**アンテナの地板（カウンターポイズ）として働いた**可能性。小型アンテナは
地板が小さいと効率が落ちるので、導体を足すと改善することがある。
**ただし 3dB は A のふらつきの中**なので「改善した」とは言い切れない。
**「悪化していない」ことは確か。**

### 承知して発注する

**2026-08-23・利用者が承知。**

⚠️ **「測れないまま覚悟して出す」のではない。****測って確認した。**
`export_fab.py` の門の文言は「発注前に直す手は無い／測れるのは組み上げた
後になる」と書いているが、**手 0（アルミ箔で地板を模擬・¥0・当日）で
測れた。**その前提が変わった。

**駄目だったときに作り直すもの**: 子基板のみ（$25〜35・2〜3 週間）。
本体基板とケースは影響しない。

⚠️ **残る不確かさ**:

| | |
|---|---|
| **距離を正確に測っていない** | 利用者「mm 単位で調節するのは難しい」。**「近い（数 mm）」と「遠い（約 2cm）」の 2 点。**桁は分かるので 20dB 判定には足りる |
| ~~**記録の 5.24mm の計算元が見つからない**~~ **→ 追えた（2026-08-23 訂正）** | 一度「計算元が見つからない／根拠の検査が存在しない」と書いたが、**どちらも誤り**（grep が足りなかった）。5.24mm は [envelopes.py:263](../../tools/envelopes.py#L263) の表——**出荷構成（直付け `DB_XIAO_LIFT = 2.0`）** でのアンテナ↔本体基板の最短距離。検査も [test_assembly.py:1319](../../tools/test_assembly.py#L1319) に**実在し、通る**（実行して確認。見出しを消すと落ちることも故意に壊して確認）。⚠️ **ただし手元の設計値で測ると 0.718mm**——プロトタイプ期にソケットを挟んでいるためで、下の「承知でソケットを挟む」が承知の記録。**出荷構成に戻せば 5.24mm** |
| **F を割愛した** | 「作り直す前と比べて何 dB 買ったか」は不明。**判定には不要** |
| **実機の筐体・電池・キーが揃った状態では未測定** | 組み上げてから §6-6 で測り直す |

---

## 23. ✅ 2026-08-23 決着 アンテナが地板に挟まれている（**実測で判定した**）

**この項目が残っている間は、左右間 BLE が実測されていない。**

> **⚠️ 2026-08-12 追記: この距離を守る検査ができた。**
> `test_the_antenna_keeps_its_distance_from_the_main_board`（左右）が、
> アンテナと本体基板の最短距離が **5.0mm** を割ったら落ちる。
> **いまの値は 5.24mm**（ヘッダの樹脂 2.0mm ぶん XIAO が浮いているため。
> 樹脂を外せば 7.22mm）。**この検査が無かった間に、XIAO をソケットで
> 10.5mm 浮かせて 0.72mm まで詰める設計が、干渉検査を全部緑で通った**
> （#27）。**案 C で稼いだ距離は、黙って失われうる。**

> **⚠️ 先に読む（2026-08-11 追記）: この節の前半（「何が起きているか」〜
> 「やること」）は 2026-08-09 の案 C 実施前の記録。**現状は後半の
> 「**案 C を実装した**」以降にある——**アンテナはもう本体基板の下に
> 居ない**（最近接 6.24mm・指針内）。FFC 7.3mm・真下の配線は D9 移設
> （2026-08-11）で実外形の下 0 本。**残る未知は「劣化が何 dB か」だけ
> ＝手 0 で測る。**前半の表（上 4.09 / 下 1.6 / 横 0.5 / 潜り込み 6.6）は
> **変更前の値**。実際に 2026-08-11、前半だけ読んで「アンテナは
> いま挟まれている」と誤読したセッションがある。

> **★ 2026-08-16 追記: 判定の基準が変わりうる材料が入った。**
> Seeed 公式の XIAO nRF52840 v1.1 の `.kicad_pcb` を機械で読んだ結果、
> **AN3216 を実装している Seeed 自身が取っている禁止域は、アンテナ本体の
> 縁から 1.30mm（基板外形から 3.14mm）で、全 4 層とも同一**だった。
> **この節が基準にしてきた「全層 5〜10mm」は、量産設計の実態より厳しい。**
> ただし性質が違う（面内の逃げ ↔ 外部の金属面の接近）ので、
> **「5.24mm あるから安全」という結論にはならない。**
> 詳細と出典は
> [decisions/2026-08-16-xiao-antenna-ground-from-seeed-source.md](decisions/2026-08-16-xiao-antenna-ground-from-seeed-source.md)。
> **手 0（§6-6b）は依然として必要。**閉じるのは実測だけ。

**この件を止めている仕組み（実在するもの・2026-08-09 に確認）:**

| 何が | 何をするか | 何をしないか |
|---|---|---|
| `test_the_antenna_record_cannot_be_silently_deleted` | **測る前にこの節が消されたら落ちる。**消してよいのは、見出しに **「アンテナの実測結果」**を含む節を残したときだけ | **未解決のまま落ち続けはしない。**節がある限り緑 |
| `test_fabrication_output_requires_an_accepted_antenna_risk` | この節がある間、**「### 承知して発注する」が無ければ**製造ファイルの出力を止める | |
| `export_fab.py` の `_gate_antenna()` | 同上（実際にガーバーを出す側の門） | |

> **⚠️ ここには一度 `test_the_antenna_risk_is_still_unresolved` と書いてあったが、
> その名前の検査は一度も存在しなかった**（履歴にも無い。別セッションの指摘で発覚）。
> **文書が「検査がある」と主張していて、実際には無かった。**この案件で
> いちばん危ない形（設定しただけで効いていない）そのもの。

### 何が起きているか（すべて実測・**2026-08-09 案 C 実施前の状態。現状ではない**）

| | 距離 | 何 |
|---|---|---|
| **上** | **4.09mm** | 本体基板の **In1.Cu 全面 GND ベタ**（4 層） |
| **下** | **1.6mm** | 子基板の GND ベタ |
| 横 | 0.5mm | FFC コネクタ。そこから 12 芯・50〜115mm のケーブル |
| 横 | 10.6mm | 電池（ここだけ基準を満たしている） |

**アンテナは本体基板の後端より 6.6mm 内側へ潜り込んでいる**
（アンテナ y=+42.1 / 本体基板の後端 y=+48.7）。

一般的なチップアンテナの指針は「**全層で 5〜10mm の禁止域**」。
**上 4mm・下 1.6mm では、どう対策しても満たせない。**

### なぜこうなったか

`USB を実機と同じ奥面へ出す`（decisions/2026-08-07-daughterboard.md）から
連鎖している。

```
USB を奥面へ → XIAO の USB 端が奥を向く
            → アンテナは必ず反対端＝本体の内側を向く
            → その先に本体基板（4 層・全面 GND ベタ）がある
```

**子基板をどこへ動かしても、USB が奥面である限りアンテナは内側を向く。**

### 検討して**捨てた**対策（同じ道を二度通らないため）

> **⚠️ この表の数字は 2026-08-08 の幾何のもの（2026-08-11 追記）。**
> その後、XIAO の奥端移動（5dcd253）・脚ボス変更（#29）・ケース奥行
> （e8fd4b6）・電池ボックス（#22）で幾何が 4 回動いた。しかも
> **「XIAO を奥端へ寄せる」の行は後に反証されて案 C として採用された**
> （取付穴はツメ受けに変えて成立した）。この表を根拠に案を捨て直す
> ときは、**現在の幾何で測り直してから**にすること。

| 案 | なぜ捨てたか |
|---|---|
| 本体基板の後端の銅を抜く | 3 つの阻害要因のうち**いちばん遠いものだけ**。支配的でない |
| 子基板を 90° 回す | **FFC コネクタが入らない**（幅方向 1.1mm 超過／奥行方向 4.9mm 不足） |
| XIAO を子基板の奥端へ寄せる | USB の隙間 2.9mm が要り、**奥側の取付穴が入らなくなる**（帯 2.90mm、M2 は 4.4mm 必要） |
| 子基板を横広（27×24）にしてネジを左右へ＋コブ +5mm | **実機 +10mm 払ってアンテナが 1mm 出るだけ。**割に合わない |
| 外部アンテナ端子を使う | **XIAO nRF52840 に BLE 用の u.FL 端子は無い**（NFC 用は別物） |
| コブを大きく深くする | 指針を満たすには**実機 +20mm 以上**。実機再現を捨てることになる |
| 子基板の銅をアンテナの下から抜く | **アンテナの影 3mm のうち 2mm が FFC コネクタの下。**空くのは 1mm 幅だけ（2026-08-08 実測） |
| 子基板を 90° 回す（再検討） | 左は使える幅 31.4mm を使い切り、**アンテナと電池が −0.6mm**（必要 10mm）。10.6mm 足りない。右だけなら回せるが、通信は弱いほうで決まる |
| 右の子基板を空いた x へ動かす | **どこに置いても最良で 9 本掛かる。**裏面を列のバス 9 本が横断している（x を 0.5mm 刻みで全走査） |

### 2026-08-08 にやったこと: 本体基板の禁止域（**左のみ**）

上の表で一度「支配的でない」として捨てた案を、**入れ直した。**
発注を 1 回にまとめると決めた以上、**無料でできることは全部やる**ため。

| | 結果 |
|---|---|
| **左** | **30×15mm を全層で禁止域に。**配線を 1 本も動かさずに入った（DRC 0 件のまま。費用はビア +1 個・配線 +4mm） |
| 右 | **入れられなかった。**裏面を列のバス 9 本が横断している。30×15 で違反 19 件、20×8 に狭めても 10 件 |

**Freerouting 2.3.0 は DSN に書いた禁止域を守らない。**4 層とも正しく
出ていることは確認した。左が通ったのは、たまたまそこを使わなかっただけ。

### ⚠️ 「左は対策済み」ではない

**塞いでいるものは 3 つあり、左右で共通。**左で外せたのは 1 つだけで、
しかも**いちばん遠い＝影響が小さいもの**。

| | 距離 | 何 | 左 | 右 |
|---|---|---|---|---|
| 上 | 4.09mm | 本体基板の GND ベタ | ✅ 窓を開けた | ❌ 開けられない |
| **下** | **1.6mm** | **子基板の GND ベタ** | ❌ | ❌ |
| 横 | 0.5mm | FFC コネクタ | ❌ | ❌ |

**いちばん近い「下 1.6mm」は左右とも手つかず。**
正しくは「**左右とも未対策。左だけ、無料でできる分を追加でやった**」。

効き目は限定的なはず。2.4GHz の波長は 125mm で、4mm 上のベタに開けた
30×15mm の窓の外にはベタが残る。**「やらないよりまし」以上の主張はしない。**

`test_the_antenna_keepout_is_actually_empty` が、宣言どおり銅が無いことを
実基板で確かめる。`test_the_antenna_keepout_covers_the_real_antenna` が、
その位置がケース側から計算した本物のアンテナと合っていることを確かめる。

#### 代償（地板を切ることの副作用）— 確認済み

| 見たこと | 結果 |
|---|---|
| 内部に穴を作っていないか | **基板の縁から入る切り欠き。**内部の孤島は無い |
| ベタが分断されていないか | **左 86.5% / 右 89.3% を覆ったまま**（割ると 39.5% に落ちる） |
| 切り欠きの向こうに部品があるか | **何も無い。**残る地板 3.1mm の細い部分に戻り電流は流れない |
| 近くを通る配線 | 3 本だけ。`SW6_D` と `ROW0` ＝ **走査の kHz**。遠回りは効かない |
| In2.Cu は地板か | 違う。**信号層**（配線 65 本）。禁止域の中には 1 本も無い |
| 配線の増加 | ビア +1 個・総長 +4mm |

**この基板でいちばん速いのは SPI の 4MHz。**戻り経路の遠回りが効くのは
数百 MHz からで、桁が違う。

`test_the_ground_plane_still_covers_the_board` が面積で見張る。
**数で見てはいけない。**最初「塗られた多角形が 1 個であること」と書いたが、
地板を横断する帯を故意に入れても 1 個のままだった。KiCad は切り離された側を
**孤島として黙って削除する**ので、多角形は 1 個のまま面積だけ半分になる。

### 発注は 1 回にまとめる（利用者の判断・2026-08-08）

送料がかかるので、子基板だけ先に出して測る案は採らない。
**そのため発注前に測る手段が無い。**

手戻りは**子基板 1 枚に閉じ込めてある**。ケーブルの界面
（12 ピン・0.5mm ピッチ・ピン配置・B.Cu 面・回転 180°・前端から 5.0mm）を
`test_the_cable_interface_is_frozen` が凍結しているので、子基板を作り直しても
本体基板 2 枚とケーブルは無傷。ケースは 3D プリントなので作り直せる。

### なぜ「現状のまま」にしたか

**有効な対策が無かったから。**上のとおり、払える代償の範囲に解が無い。

一方でリンクバジェットの余裕は大きい（2.4GHz・送信 0dBm・受信感度 -90dBm）。

> **-90dBm は保守値。**Nordic の仕様は **-96dBm @ 1Mbps**
> （nRF52840 Module Specification）。**6dB ぶん厳しく見積もってある。**

| 距離 | 受信レベル | 余裕 |
|---|---|---|
| 0.3m（左右間） | -30dBm | **60dB** |
| 2.0m | -46dBm | **44dB** |

**20〜30dB 劣化しても 30dB 残る。**動く可能性は高い。ただし
**実際どれだけ劣化するかは、測っていないし見積もれていない。**

### 判断材料: 送信電力（2026-08-09 に調査）

**#23 の対策一覧に送信電力は入っていない。**手順書が挙げているのは
外付けアンテナを持つ別モジュールへの変更だけ。**下は新しく調べた材料**で、
まだ検討された案ではない。

| | |
|---|---|
| 現状 | **0 dBm**。Zephyr の既定で、ZMK もこの案件も上書きしていない |
| 選べる値 | nRF52840 は **+8 / +7 / +6 / +5 / +4 / +3 / +2 / 0 / −4 / −8 / −12 / −16 / −20 / −40 dBm**（`radio-tx-high-power-supported` が dts にある） |
| 変え方 | `.conf` に `CONFIG_BT_CTLR_TX_PWR_PLUS_4=y` の 1 行。**ファームなので発注後でも変えられる** |
| 動的な変更 | Zephyr に機能はある（`BT_CTLR_TX_PWR_DYNAMIC_CONTROL` ＋ VS HCI）。**ZMK は未対応。前例も見つからない** |

**電流（Nordic の実データ・DCDC 3V）**

| 送信電力 | TX 電流 | 左の寿命（推定） | 右の寿命（推定） |
|---|---|---|---|
| **0 dBm（今）** | 4.9mA | **11.6 ヶ月**（実測 0.66mA から） | **5.7 年**（実測 0.040mA から） |
| +4 dBm | 9.3mA | 約 9.5 ヶ月 | 約 5.3 年 |
| +7 dBm | 約 12mA | 約 8.4 ヶ月 | 約 5.0 年 |
| +8 dBm | 14.1mA | 約 8 ヶ月 | 約 5 年 |

**左だけが高い。**セントラルは 7.5ms ごとに送信するが、ペリフェラルは
latency 30 で 232ms に 1 回しか起きない。**右はほぼ無料。**

**⚠️ 技適（211-220207）の空中線電力は「3.0mW、6.0mW」**

| 設定 | 公称電力 | |
|---|---|---|
| +4 dBm | 2.51mW | 3.0mW の枠内 |
| +7 dBm | 5.01mW | 6.0mW の枠内 |
| **+8 dBm** | **6.31mW** | **6.0mW を超える（公称値での比較）** |

**ただし +8 dBm が範囲外だとは断定できない。**公称値と実測値は一致せず、
**認証の 6.0mW が「+8 dBm 設定で実測した値」である可能性がある**
（実際の出力は公称より低いのが普通）。**公開情報からは判別できない。
Seeed への確認が要る。**

**⚠️ そして送信電力は、この問題を解決しない。**

```
想定される劣化      20〜30 dB（この節の見積もり）
+4 dBm で戻る量          4 dB
```

**桁が足りない。**送信電力は余裕を少し足すもので、**塞がれたアンテナを
直すものではない。**片側だけ上げても、良くなるのはその向きだけ。

### やること（**この順に。飛ばさない**）

> **⚠️ この手順は 2026-08-09 に前段が 1 つ増えた。**下の 1 は「子基板が
> 届いてから測る」前提で書かれているが、**届く前に測れる**ことが分かった
> （アルミホイルで地板を模擬する。手順は
> [Task C3 §6-6b](task-c3-ble-split.md)）。**先にそちらを読むこと。**

1. **[Task C3](task-c3-ble-split.md) の §6-6 で RSSI を測る。**
   ①XIAO 単体 → ②＋子基板 → ③＋FFC ケーブル → ④＋ケース組み立て を
   **同じ日に続けて**測る。日を分けると比較にならない
2. **実使用で確かめる。****手を鍵盤に乗せて**高速に打鍵し、取りこぼしや
   切断が出ないか。

   > **⚠️ 距離を設計側で仮定しない（2026-08-09 に訂正）。**
   > ここには「左右を 20〜40cm に置き」と書いてあったが、**分割キーボードの
   > 目的に反する。**分割にするのは左右を**自分の肩幅・角度・高さに自由に
   > 置く**ためで、机上 40cm に収まる保証は無い。片方を肘掛けや別の面に
   > 置く使い方もある。**利用者が置きたい最大の距離で試す。**
3. **問題が出たら**、外付けアンテナを持つ別モジュール（技適取得済みのもの）
   への変更も含めて選択肢を洗い直す。**いまの XIAO を前提にした対策は
   出し尽くしている**

### この節を消してよいのは

**上の 1 と 2 を実測し、結果を記録したとき。**
そのときは**この節を消すだけでなく、見出しに「アンテナの実測結果」を含む節を
残すこと。**`test_the_antenna_record_cannot_be_silently_deleted` がその文字列を
探しており、**測らずに消したのか測って消したのかを、そこで区別している。**

---

## ★ 次のセッションでやること（2026-08-09 に整理）

### 目的は「解く」こと。承知して発注するのは**最終手段**

**利用者の意思（2026-08-09）:「リスクを飲んで発注」は基本的に取らない選択肢。**

`tools/export_fab.py` の `_gate_antenna()` は、この節に
**「### 承知して発注する」が無い限りガーバーを出さない。**
**その節を書くのは、解けないと結論したあと。**最初に書くものではない。

### 攻めるのはレイアウトではなく、**前提**

**「検討して捨てた対策」の 8 案は、すべて次の前提を固定したまま潰してある。**
同じ前提のまま 9 案目を出しても同じ結果になる。**前提そのものを疑う。**

| # | 前提 | 出典 | 揺らがせるか |
|---|---|---|---|
| **P1** | **USB-C を実機と同じ奥面へ出す** | [decisions/2026-08-07-daughterboard.md](decisions/2026-08-07-daughterboard.md) の採用理由 | **CLAUDE.md の「揺らがせない」5 項目に入っていない。**入っているのは配列・寸法・段のずれ・手前端の高さ・キートップの高さ |
| **P2** | 発注を 1 回にまとめる | この節（利用者の判断・送料が理由） | 利用者の判断。**測定が買えるなら再考の価値** |
| **P3** | MCU は XIAO nRF52840 | [decisions/2026-08-07-keyscan.md](decisions/2026-08-07-keyscan.md)（技適 211-220207） | **技適取得済みで外部アンテナ端子を持つモジュールは未調査** |
| **P4** | 子基板を使う | 同上（USB を奥面へ出すため） | **P1 が動けば連鎖して動く** |

**P1 が根です。**「USB を奥面へ → XIAO の USB 端が奥を向く → アンテナは必ず
内側を向く → その先に本体基板の全面 GND ベタ」と連鎖している。

### 最低限やること（**2026-08-09 に実施。結果は下の節**）

1. **P1〜P4 のそれぞれを動かしたとき、何が壊れるかを数字で出す**
2. **技適取得済みで u.FL 等の外部アンテナ端子を持つモジュールを、実在の型番で探す**
   （在庫・価格・ZMK 対応の有無まで。#23 の「やること 3」が指しているのはこれ）
3. **「子基板だけ先に発注して測る」の費用と日数を出す**（P2 の再考）
4. そのうえで**解ける案があるか**を結論する

→ [★ 2026-08-09 の調査結果](#-2026-08-09-の調査結果前提を疑った)

### 解けなかったときだけ、承知の記録を作る

門が要求するのは 3 つ。**誰が・いつ承知したか / 駄目だったとき何を作り直すか /
その根拠。**

### 決める前に読む順序

| # | 読むもの | 何が分かるか |
|---|---|---|
| 1 | この節の**冒頭〜「なぜこうなったか」** | 何が起きているか。3 つの阻害要因 |
| 2 | **「検討して捨てた対策」の表** | **8 案すべて数字で潰してある。**同じ道を二度通らないため |
| 3 | 「2026-08-08 にやったこと」＋「⚠️ 左は対策済みではない」 | 左右とも本質は未対策 |
| 4 | 「なぜ現状のままにしたか」 | 余裕 60dB / 劣化 20〜30dB の見積もり |
| 5 | 「判断材料: 送信電力」 | 送信電力では桁が足りないこと |

### 中心にある未知

**劣化量が測れていない。20〜30dB は見積もりですらなく仮置き。**
どの案を採るにせよ、**この数字を実測に変えるか、数字に依存しない解にするか**の
どちらかが要る。

### そのほかの論点

| # | 論点 | 現状 |
|---|---|---|
| C | 駄目だったときの作り直しの範囲と費用 | 手戻りは子基板 1 枚に閉じ込め済み。**金額は未算出** |
| E | 送信電力を上げる | **桁が足りない**（4dB vs 20〜30dB）。単独では解にならない |
| F | 実使用の距離をどこまで支持するか | **設計側で仮定してはいけない**（分割の目的）。試験の条件としては決める必要がある |

### この件で、以前の説明に誤りがあった（2026-08-09 に訂正）

**次のセッションで同じ誤解をしないため、残しておく。**

| 誤り | 正しくは |
|---|---|
| 「左は対策済み」 | **左右とも未対策。**左は 3 つのうち最も遠い 1 つを外しただけ |
| 「送信電力を上げれば解決できる」 | **桁が足りない。**4dB では 20〜30dB の劣化は埋まらない |
| 「+8 dBm は技適の範囲外」 | **断定できない。**公称 6.31mW と認証 6.0mW の比較で、実測値は不明。Seeed への確認が要る |
| 「実使用は左右 20〜40cm」 | **分割の目的に反する仮定。**距離は利用者が決める |

---

## ★ 2026-08-09 の調査結果（前提を疑った）

> ## ⚠️ 2026-08-14: **この節の幾何の証明はもう成立しない**
>
> 下の「アンテナは必ず 4mm 以上、本体基板の下に入る」は、
> **`XIAO_OVERHANG`（1.8mm・XIAO を子基板から奥へはみ出させる）が
> 入る前の話。**いま実測すると:
>
> ```
> 本体基板の後端  y 48.70
> アンテナ       y 49.50 .. 53.00   ← 後端より 0.80mm 奥
> ```
>
> **アンテナは本体基板の下に入っていない。**平面的に基板の外なので、
> 「両面 GND ベタが真上にある」という #23 の出発点そのものが変わった。
> 8 案が空集合だったという結論も、この証明に乗っていたので**前提を
> 引き直す必要がある。**（測ったのは利用者の指摘「本当にアンテナの
> 真上ですか？」がきっかけ。詳細は **#41**）
>
> ⚠️ **ただし「解決」ではない。**余裕は **0.80mm しかなく**、製造公差と
> 組み立てのばらつきで簡単に入れ替わる薄さ。**手 0（アルミ箔で RSSI・
> ¥0・1 日）の価値は変わらず残る。**むしろ「もう出ているはず」で
> 済ませないために測る。
>
> 縮んだら気づけるよう `test_pcb.test_the_antenna_clears_the_main_board`
> を置いた（`XIAO_OVERHANG` を 0 にすると落ちる）。
>
> なお、この節を根拠に左基板へ入れていた **30×15mm の禁止域は
> 削除した**。アンテナから 3.9mm 的を外しており、450mm² を捨てて
> 配線を圧迫していただけだった（#41）。

### 結論を先に

| | |
|---|---|
| 解けるか | **解ける見込みのある案が 2 つ残った**（下の A / B）。ただし**まだ「決めた」とは書かない。**CLAUDE.md の 3 条件が未了 |
| 次の一手 | **手 0（¥0・1 日・発注不要）を先にやる。**「発注前に測る手段が無い」は**誤りだった** |
| 8 案が潰れた本当の理由 | 解が無かったのではなく、**探していた集合が空だった**（下で幾何の証明にした） |

### 8 案は空集合の中を探していた（幾何。数字は tools から計算）

XIAO は 21mm の板で、**USB とアンテナは両端にある**（この案件の実測。
`gen_case.py` の DB_ANTENNA_KEEPOUT のコメント）。ここから：

```
USB を奥面へ出す        → USB 端は奥内壁 y=69.16 のそば
                        → アンテナ端は必ずその 21mm 手前（y ≦ 約 44.7）
本体基板の後端 y ≒ 48.7 → アンテナは必ず 4mm 以上、本体基板の下に入る
```

**「必ず」なので、子基板をどこへ動かしても、回しても、削っても戻ってくる。**
そしてその帯の頭上には、そもそも高さが無い：

> **⚠️ 下の表の「本体基板の下端」は `pcb_bottom_at()` の保守平面**
> （ソケット深さ 3.2mm を全面一律に引いた値）で、**局所の真実ではない**
> （2026-08-11 追記）。この表の 0.13mm を局所の隙間として引用した結果、
> #27 に嘘の制約が生まれた。xy の議論（アンテナが基板の下に入る）は
> この表と独立に成立している。

| 奥行 y | 本体基板の下端 z | 子基板スタックの上端 z | 余裕 |
|---|---|---|---|
| 36.16（子基板の前端） | 12.63 | 12.50 | **0.13mm** |
| 41.2（アンテナのあたり） | 13.27 | 12.50 | 0.77mm |
| 53.56（本体部分の後端） | 14.86 | 12.50 | 2.36mm |
| 68.16（子基板の後端） | 16.73 | 12.50 | **4.23mm** |

**本体基板の後端より奥（y 48.7〜69.16 の 20.5mm）には、上に何も無い。**
アンテナをそこへ出せれば 3 つの阻害要因が同時に消える。**出せない理由は
ただ 1 つ、そこに XIAO の USB 端が居るから。**

### P1〜P4 を動かしたら何が壊れるか

#### P1（USB-C を奥面へ）— **根はここ。ただし 3 段階に分けられる**

| 動かし方 | アンテナはどうなるか | 壊れるもの |
|---|---|---|
| **P1 のまま＋XIAO** | 上の証明どおり **解なし** | ― |
| **P1′ 口は奥面のまま、XIAO の口ではなくする**（内部で USB-C を延長し、XIAO は 180° 反転して**アンテナを奥へ**向ける） | y 41.7 → **59.7〜62.7**。本体基板の後端から **11mm 奥**、真上は樹脂だけ、電池まで x 10.6mm。**3 要因とも消える** | 部品 +1（パネル取付 USB-C メス＋L 型プラグの短ケーブル。**実在する**・$8〜15）／ケーブルの U ターンを**高さ 5.3mm × 幅 21mm** の空間で通す必要（`DB_BOSS_H` を 4.0→2.0mm にすれば 7.3mm）／組み立て工程 +1／USB 2.0 のまま（nRF52840 は元々 FS なので損は無い） |
| **P1″ USB-C を別の面へ出す** | 同上 | **実機再現。**この構成を採った理由そのものが消える。**取らない** |

**凍結してある界面（FFC 12P・0.5mm ピッチ・前端から 5.0mm）は P1′ で動かない。**
反転するのは XIAO のフットプリントだけで、FFC コネクタは前端のまま。
`test_the_cable_interface_is_frozen` は通る。

**XIAO の USB を基板上のレセプタクルへ引き込むことはできない。**
D+/D− が外に出ていない（裏面パッドは VUSB/GND/3V3/D10〜D7・D0〜D6・BAT±・NFC のみ。
`gen_case.py` の RESET の項で実機の写真から確認済み）。**だから物理的にケーブルが要る。**

#### P2（発注を 1 回にまとめる）— **再考したが、動かす価値が無い**

| | |
|---|---|
| 子基板だけ先に出す費用 | 板 $2（最低額）＋実装基本料 $8 ＋ステンシル・送料 $15 ＝ **$25〜35（¥4,000〜5,000）**。本番でもう一度送料 $10〜25 |
| 日数 | 製造 2〜3 日 ＋ 輸送 5〜14 日 ＝ **2〜3 週間** |
| **それで何が測れるか** | **3 要因のうち 2 つだけ**（下 1.6mm・横 0.5mm）。**いちばん効くはずの「上 4.09mm の本体基板」は手元に無い** |

**払う意味が無い。**下の手 0 が、同じもの（しかも 3 要因すべて）を **¥0・1 日**で測る。

#### P3（MCU は XIAO）— 実在の型番が 1 つある

| | Raytac **MDBT50Q-U1MV2** |
|---|---|
| 技適 | **018-180280**（工事設計認証 CSRT180280-1・2018/7/30・C&S）。対象型式に **MDBT50Q-U1M** が入っている。空中線電力 5.9704mW / 5.0816mW |
| 外部端子 | **u.FL**（10.5×15.5×2.05mm） |
| **アンテナの縛り（重要）** | **認証は「モジュール＋指定アンテナ」の組み合わせに対してのみ。**TELEC を持つのは Yageo **ANTX100 ETHAB24553**（外付・≦2dBi）／**ANTX100 P011B24003**（PCB・2.2dBi）／**ANTX100 P111B24003**（PCB・3.3dBi）の 3 つだけ。Aristotle RFA-02-5 は FCC/IC/KC/NCC/SRRC のみで **TELEC 無し**。**一覧外のアンテナを挿すと未取得**（データシート Ver.G p.30 の注記。日本の代理店（フクミ）も同じ説明） |
| 価格・在庫 | DigiKey **$6.15**・在庫あり |
| **JLCPCB の在庫** | **MDBT50Q 系 10 品番すべて 0**（`jlcpcb_lookup.py` で確認）。**実装を頼めない → 61 パッドを手半田** |
| ZMK | nRF52840 なので動く。ただし **`xiao_ble` のボード定義が使えなくなり、独自ボード定義が要る** |
| ほかに壊れるもの | USB-C レセプタクル・CC 抵抗 2 本・ESD を自前で持つ／**MCU の差し替えができなくなる**（故障＝基板ごと）／技適マーク 018-180280 の表示義務 |

**この案の利点は 1 つだけ、しかし決定的: 効くかどうかが「測った数字」に依存しない。**
アンテナを同軸で好きな場所（コブの天井ぎわなど）へ出せる。

**技適付き・u.FL・ZMK 既対応の「完成ボード」は見つからなかった。**
日本で技適を持つ ZMK 用ボードとして流通しているのは XIAO nRF52840 系で、
そのアンテナは基板上のセラミックで、外部端子は無い。

#### P4（子基板を使う）— **単独では動かない**

本体基板の空きは奥の帯が裏 10.3mm / 表 5.9mm、手前の帯は基板の上に
**3.5mm**（`PLATE_TO_PCB`）しか無い。XIAO 3.0mm ＋ ソケット 2.5mm ＝ 5.5mm。
**P1 が動いても子基板は要る。**

### 手 0（先にやる）: 発注前に測る。**¥0・1 日**

**「発注をまとめる以上、発注前に測る手段が無い」は誤りだった。**
測りたいのは**絶対値ではなく、遮蔽による劣化の差**であって、
差を作っているのは**地板そのもの**であって、基板である必要は無い。

| 要素 | 代用 | なぜ等価と言えるか |
|---|---|---|
| 上 4.09mm の本体基板の GND ベタ | 銅箔テープ／捨て基板／アルミ箔を、**厚紙のスペーサで 4.09mm 上**に | 2.4GHz では表皮深さは 1.5µm 程度。**反射体・離調要因としては厚さも材質もほぼ効かない** |
| 下 1.6mm の子基板の GND ベタ | 同じものを 1.6mm 下に | 同上 |
| 横 0.5mm の FFC コネクタとケーブル | 金属片＋手持ちのフラットケーブル | 同上 |
| 電池（10.6mm 横） | 単3 2 本 | そのまま |

**わざと実物より悪く作る**（左に開けた 30×15mm の窓を作らない・板を大きめにする）。
それで許容できるなら、**実基板はそれより良い**。数字は上限として使える。

測り方は [Task C3 §6-6](task-c3-ble-split.md) の階段に 1 段足すだけ：
**① XIAO 単体 → ①′ ＋模擬地板（これが新しい段）→ ② 子基板 …**。
①と①′を**同じ日に続けて**測る。要るのは XIAO（C3 の治具にある）と
スマホの BLE スキャナだけ。

**これで「20〜30dB」という仮置きが数字になる。**
どの案を選ぶにしても、この数字が先。

### 案 C を実装した（2026-08-09・試作）→ **アンテナは基板の下から出た**

**#28（USB が挿さらない）と同じ変更で、両方が直る。**詳細は #28。

XIAO を奥端へ寄せた

| 阻害要因 | 変更前 | 変更後 |
|---|---|---|
| **上**: 本体基板の全面 GND ベタ | **真上 4.09mm**（7.3mm 潜り込み） | **真上には無い。**最も近い点まで **6.24mm** |
| **下**: 子基板の GND ベタ | 1.6mm（抜けない） | **抜いた**（ベタのみ。配線 12 本は通す） |
| **横**: FFC コネクタ | **0.5mm** | **7.3mm** |

**3 つとも動いた。**

> **6.24mm について、私の書き方が不当に否定的だった（利用者の指摘で訂正）。**
> 指針は「全層で 5〜10mm の禁止域」。**6.24mm はその下限を満たしている。**
> 「下限にかかる程度」と書いたが、満たしているものを満たしていないかのように
> 書くのは正しくない。

**いま指針を満たしていないのは 1 つだけ**になった。

| | 距離 | 指針（5〜10mm） |
|---|---|---|
| 本体基板の地板 | 6.24mm | **満たす** |
| FFC コネクタ | 7.3mm | **満たす** |
| **子基板の配線 12 本** | **約 1.6mm** | **満たさない** |

**配線を通すのは、チップアンテナの指針に反する。**

> **⚠️ 「12 本すべてがアンテナの下を横切る」は誤りだった（2026-08-09 に訂正）。**
> **アンテナが XIAO の全幅（18.3mm）にあるという前提で書いていた。**
> 利用者の実測では **3.5 × 1.5mm の小さな部品**で、XIAO の幅の 2 割弱しかない。
> 縦のレーンは x を選べるので、**帯の外を通せば真下は 1 本も通らない**はずだった。

**実際にやってみた結果（2026-08-09）**

| 試したこと | 結果 |
|---|---|
| レーンの間隔を詰めて全部を外へ寄せる | **駄目。**ビア（φ0.6）と隣のレーンの配線が 0.11mm（規則 0.2mm） |
| 帯に入る位置を飛ばして、その先へ置く | **駄目。**飛んだ 1 本が他のレーンと交差する |
| **レーン全体を外へ寄せる（LANE0 6.0 → 6.4）** | **採用。**6.5 は D6 のパッドと 0.17mm で落ちた |

**いまの状態: アンテナの真下を通る配線は 1 本**（10 本中）。もう 1 本が
アンテナの縁から 0.5mm 以内にいる。**2 本 → 1 本には減ったが、0 ではない。**

**残りの 1 本を消すには、次のどれかが要る（未検証）:**

| 案 | 代償 |
|---|---|
| ビアを φ0.45 / ドリル 0.2mm にする | JLCPCB の能力内だが、**追加費用の可能性**（標準は 0.3mm ドリル） |
| FFC コネクタを板の奥側へ動かす | **凍結した界面（前端から 5.0mm）を動かす** |
| 子基板を広げて XIAO の脇を通す | **電池との距離が減る。採れない** |

**アンテナの位置を実測した（2026-08-09・利用者）**

「TX と印刷されている側の縁から、青い部品の中心まで **7.0mm**」。
XIAO の幅 17.8mm の中心は 8.9mm なので、**TX 側へ 1.9mm ずれている**。

> **写真からの読み（1.7mm）より 0.2mm 大きかった。**そしてその 0.2mm で、
> アンテナの下を通る配線が **1 本から 2 本に増えた**。**測ってよかった。**
>
> 測る基準は「左の縁」ではなく「**TX 側の縁**」。基板を裏返すと左右が
> 入れ替わり、結論が逆になる（一度「左の縁」と書いて確認が要った）。
> 図: [images/where-to-measure-antenna.svg](images/where-to-measure-antenna.svg)

**実測後の状態**

| | |
|---|---|
| アンテナ（XIAO の中心線基準） | **-3.65 〜 -0.15mm**（TX 側） |
| TX 側のレーン 6 本 | -6.4 / -5.7 / -5.0 / -4.3 / **-3.6** / **-2.9** → **2 本が真下** |
| RX 側のレーン 4 本 | 6.4 / 5.7 / 5.0 / 4.3 → **0 本** |

**避けるには TX 側の 6 本を x ≤ -4.15mm に収める必要がある。
使える幅は 2.25mm で、6 本には 3.0mm 要る（0.75mm 足りない）。**
0.6mm 刻みが下限なのは、ビア（φ0.6）と隣のレーンの配線が 0.2mm 離れないため。

**残る手（どれも代償がある）→ ✅ D9 移設を実施した（2026-08-11・利用者の決定）**

| 案 | 代償 | |
|---|---|---|
| ビアを φ0.45 / ドリル 0.2mm にする | JLCPCB の能力内だが**追加費用の可能性**。それでも 0.45mm 刻みが要り、まだ足りない | 採らず |
| **行を 1 本 D9（MISO・未使用）へ移して TX 側を 5 本にする** | **ファームのピン割り当てとケーブルのピン配置が変わる** | **✅ 実施** |
| FFC コネクタを板の奥側へ動かす | **凍結した界面を動かす**（前端から 5.0mm） | 採らず |

#### ✅ D9 移設の実施記録（2026-08-11）

| 変えたもの | 中身 |
|---|---|
| 回路（`circuit.py`） | ROW4 の行き先を D5（左列）→ **D9（右列・元 MISO）**。ケーブルのピン配置は ROW4 を右群 4 番へ挿し、5 番以降を繰り下げ（1:CS 2:GND 3:SCK **4:ROW4** 5:MOSI 6:V3V3 7:VBATT_SENSE 8-11:ROW0-3 12:GND）。SCK の隣 GND・GND 2 本・CS 端は維持 |
| 子基板 | TX 側レーン 6 → **5 本**、`LANE_STEP` 0.7 → **0.65**。最内レーンは **-3.8mm** で、**アンテナの実外形（-3.65〜-0.15）の真下は 0 本**になった。縁 0.5mm の帯（-4.15〜+0.35）には 1 本残り、これは遠い層（B.Cu・3.2mm）を通る。帯 0 本は幾何的に不可能（D6 パッドが LANE0=6.4 を縛り、5 本 ×0.5625mm 刻みが要るがビアの規則で 0.625mm が下限） |
| 本体基板 2 枚 | J_DB のピン配置が変わったので**再生成＋自動配線し直した**。3 基板とも DRC 違反 0 / 未配線 0 |
| ファーム（`hhkb_split.dtsi`） | `row-gpios` の 5 本目を `&xiao_d 5` → `&xiao_d 9`。**D9(P1.14) は xiao_ble の pinctrl が MISO として確保している**ので、`&spi2_default` / `&spi2_sleep` の psels を SCK・MOSI の 2 本に上書きして解放（595 は出力専用で MISO を読まない）。**CI ビルドと実機は未確認** |
| 凍結界面 | FFC の footprint・B.Cu・180°・前端 5.0mm は**不変**。変わったのは**ピンへのネット割当だけ**（基板は未発注なので巻き添えは無い） |

**注意（ケーブルのピン配置を過去に写した場所）:**
decisions/2026-08-07-daughterboard.md の表は更新済み。
`test_the_cable_pinout_table_matches_the_circuit` と
`test_the_cable_interface_is_frozen`（J_DB ↔ J_MAIN の一致）が守る。

### いま無料でできることはやった: 2 本を遠いほうの層へ逃がした
（→ 2026-08-11 の D9 移設で、この 2 本のうち**実外形の真下を通るものは 0 本**になった。以下は移設前の記録）

消せない以上、**せめて距離を稼ぐ。**

| | アンテナからの距離 |
|---|---|
| 表面（F.Cu）を通す＝以前 | **1.6mm** |
| **裏面（B.Cu）を通す＝いま** | **3.2mm** |

板厚 1.6mm ぶん遠ざかるだけだが、**ここは基板が届いてからでは直せない**
（配線は XIAO の本体の下に隠れ、直付けなら剥がせない）。
`test_no_copper_on_the_near_layer_under_the_antenna` が、
**アンテナに近いほうの層に銅が無いこと**を実基板で見張る。

### ⚠️ 「駄目でも予備の 3 枚がある」は誤りだった（2026-08-09 に訂正）

**この 2 本を許容する判断の根拠として「駄目でも作り直せる」と書いたが、
根拠そのものが偽だった。**利用者の指摘で気づいた。

| 私が書いたこと | 事実 |
|---|---|
| 「駄目でも予備の 3 枚がある」 | **予備には同じ配線が乗っている。**配線が原因なら 1 枚も使えない |
| （暗黙に）手直しできる | **できない。**この 2 本は XIAO の本体の下に隠れる。直付けなら剥がすところから |
| （暗黙に）素子を足して直せる | **直せない。**モジュールのアンテナの離調を外から補正する部品は無い。**ランドを用意しても使い道が無い** |

**本当の後戻り手段は「子基板だけ作り直して再発注」しかない。**
費用 $25〜35、期間 2〜3 週間（#23 の P2 の節）。本体基板 2 枚とファーム、
ケーブルの界面は無傷なので**被害は子基板に閉じる**が、**無料でも即座でもない。**

**判断への影響:**
「駄目でも安く戻せる」が消えたので、**測定は「やったほうがよい」から
「発注前にやるべき」へ変わる。**組み上げてから分かると、そこから 2〜3 週間かかる。

### 実機で無線がおかしいとき、最初に見る場所（**未来の自分へ**）

**症状**: つながらない／距離が出ない／打鍵が飛ぶ／ときどき切れる。
**疑う順**（近いものから）:

| # | 疑うもの | 確かめ方 |
|---|---|---|
| 1 | **子基板の配線 2 本**（B.Cu・アンテナの真下・3.2mm） | **共振かどうかを見る。**FFC ケーブルを外して（左右を USB 給電にして）RSSI が改善するなら、**ケーブルまで含めた導体が効いている** |
| 2 | 本体基板の地板の縁（6.24mm） | 本体基板を外して測り、差を見る |
| 3 | 電池（10.6mm） | 電池を抜いて測る |
| 4 | ケースの中の金属（インサート 14 本・スイッチ） | 上ケースを外して測る |

> **★ 私がいちばん気にしているのは 1 の「共振」。**
> この 2 本は **80mm の FFC ケーブル**につながっている。面積は小さくても、
> **2.4GHz から見れば電気的に長い導体**で、運悪く共振長に近いとアンテナを
> 引っぱる。**面積の議論（1/10 になった）はこの効き方には当てはまらない。**
> 机上では判定できない。**だからケーブルを外して比べる**のが最初の一手。
>
> もし 1 が原因だと分かったら、対策は #23 の「残る手」の 3 つ
> （ビア φ0.45 ／ 行を D9 へ移して TX 側を 5 本に ／ FFC コネクタの移動）。
> **どれも子基板の作り直しになる。**

### まとめ: 残っているもの

~~**0.2mm の線 2 本**（アンテナの真下・遠いほうの層・3.2mm）~~
→ **2026-08-11 の D9 移設で、実外形の真下は 0 本になった**（上の実施記録）。
残るのは**縁 0.5mm の帯内の 1 本**（遠いほうの層・アンテナ外形から 0.15mm 外）。
面はもう無い。**それが何 dB 効くのかは測っていない。**そして**発注後は直せない。**
→ **手 0（アルミホイルとリード線で測る・¥0）を、発注の前にやる。**
手順は **[Task C3 §6-6b](task-c3-ble-split.md)**。**子基板が無くても測れる。**
いちばん先に測るのは「100mm のリード線を GND に付けて、アンテナの脇を通す」段階
（＝上の共振の疑いを、そこだけ切り出したもの）。

**そして、劣化量はまだ測っていない。**手 0（銅箔で地板を模擬して RSSI を測る）は
依然として有効。**mm が良くなったことと、dB が足りることは別。**

### 案 C（**費用 ¥0**）: XIAO を子基板の奥端へ寄せるだけ（2026-08-09 に測った）

**部品を 1 つも足さずに、3 つの阻害要因のうち 2 つが大きく減る。**

一度この案は「得られるのは 1.1mm だけ」として捨てられていた（#23 の表）。
**理由は「奥側の取付穴が入らなくなる」だったが、ケースは 3D プリントなので
ネジをやめて印刷したツメ・レールで受ければよい。**そこを疑っていなかった。

| | いま | 案 C | |
|---|---|---|---|
| アンテナが本体基板の下に潜る量 | **4.0〜7.0mm** | **0〜2.0mm** | XIAO を 5.0mm 奥へ |
| アンテナと FFC コネクタの距離 | **0.5mm** | **5.5mm** | コネクタは前端のまま動かさない |
| 子基板の銅をアンテナの下から抜けるか | **抜けない**（影の 2/3 が FFC コネクタの上） | **抜ける**（影の下に何も無くなる） | |
| USB プラグの届き | 壁の外面から 8.9mm 奥 | **3.9mm 奥** | latent な不安が 1 つ減る |
| 干渉 | ― | **左右とも 0mm³** | `intersection_volume` で確認 |

**代償**

- **奥のネジ 1 本を、印刷したツメ／レールに置き換える**（前側 1 本は残る。
  FFC コネクタとも当たらない）
- USB の開口を少し広げる（プラグの外形が入るように）
- **完全な解決ではない。**アンテナの 2.0mm はまだ本体基板の下で、その上の
  隙間は 4.09mm のまま。**指針（5〜10mm）は満たさない**

**つまり案 C は「¥0 で大きく良くする」案であって、「解いた」ではない。**
どこまで良くなったかは、手 0（銅箔での測定）で確かめる。

### 残った案

| | A: XIAO を反転し、USB-C を内部で延長 | B: MDBT50Q-U1MV2 ＋ 指定アンテナ |
|---|---|---|
| アンテナの居場所 | コブの中の樹脂だけの空間（本体基板の後端から 11mm 奥） | 同軸で好きな場所 |
| 実機再現 | **保つ**（USB-C は奥面のまま） | 保つ |
| 追加費用 | ケーブル $8〜15 ×2 | モジュール $6.15 ×2 ＋ アンテナ ×2 ＋ 手半田 |
| 作り直す範囲 | 子基板 1 枚＋ケース（3D プリント） | 子基板 1 枚＋**ファーム（ボード定義）**＋ケース |
| 効き目が数字に依存するか | **しない**（幾何で 3 要因が消える） | **しない** |
| いちばん危ないところ | **U ターンの空間が 5.3mm しか無い。**`gen_assembly.py` で確かめるまで「入る」と言えない | **手半田と、独自ボード定義。**技適はアンテナの型番まで縛られる |

**A が本命。**壊すものが少なく、費用も期間も小さい。
**B は、A が入らなかったときと、手 0 の数字が致命的だったときの受け皿。**

### 案 A の 3D 確認（2026-08-09 実施）

**組み立て検査と同じ道具**（`verify.intersection_volume`）で、案 A の占有空間を
ケース・プレート・本体基板・電池・蓋・上ケースにぶつけた。

> **⚠️ 最初、この検査は何も見ていなかった。**`build_assembly()` は
> `(parts, (w, h))` を返すのに、戻り値を辞書として扱っていたため、
> **すべての比較が黙って飛ばされて「当たらない」と出ていた。**
> **故意に壊した版（プラグを 20mm にした）を走らせて初めて気づいた。**
> 検証の作法 2「通ったことは調べた証拠にならない」そのもの。

**測って分かったこと**

| | 結果 |
|---|---|
| **ボス高さの下限は 2.0mm ではなく 3.4mm** | 床の上に**チルト脚のボス（天面 z=5.6・8×8mm）**が立っており、子基板がそこへ食い込む（ボス 2.0mm で 120mm³）。**手で出した「2.0mm へ下げる」は誤りだった** |
| ボス 3.4mm・XIAO を板の奥端へ・直付け | **左右とも当たらない**（子基板・XIAO・USB プラグ・降りる区間・U ターン・戻りのケーブル、すべて 0） |
| U ターンの通し方 | **床ぎわに落とすこと。**USB の軸の高さのまま手前へ出すと、本体基板に 34〜71mm³ 食い込む（天井が手前ほど下がるため） |
| **ソケットは入らない（→ #27）** | 積み上げ 4.5mm（直付け）なら通る。**1.0mm のソケットでも右が 55mm³、2.5mm で 231mm³** 食い込む。**プラグの高さ 6mm を仮定した場合** |
| 奥壁のジャック | 子基板の上に **18mm 以上の空きがある**ので置ける。ただし**USB の口の高さが上がる**（いまの z≒10 → z≒18 付近） |

**買い物の仕様（2026-08-09 に測って出した）**

USB プラグの高さと、XIAO の下に入れるソケットの高さで、本体基板に当たるかを
総当たりで測った（`intersection_volume`・両半分の悪いほう）。

| ソケット | プラグ 4.0 | 4.5 | 5.0 | 5.5 | **6.0** | 6.5 | 7.0mm |
|---|---|---|---|---|---|---|---|
| **0.0mm（直付け）** | OK | OK | OK | OK | **OK** | 5mm³ | 16mm³ |
| 1.0mm | OK | 5 | 16 | 32 | 55 | 83 | 113mm³ |
| 2.0mm | 55 | 83 | 113 | 142 | 172 | 202 | 231mm³ |
| 2.5mm | 113 | 142 | 172 | 202 | 231 | 261 | 291mm³ |

**→ 直付けなら「プラグの高さ 6.0mm 以下」。これが買い物の条件。**
ソケットを入れるなら 4.0mm 以下（ほぼ選択肢が無い）。

**部品の候補（2026-08-09 に調べた）**

| | |
|---|---|
| パネル側 | **秋月 AE-USB2.0-TYPE-C-PNL・¥250。**USB2.0・L 型・パネル取付。**内側ははんだランド**（ケーブルを直に結線する方式） |
| XIAO 側 | Adafruit **6367**（スリム L 型 USB-C・23mm・$7.50）／**6372**（同 75mm・$5.95）。CC ピンまで結線済みと明記 |
| 1 部品で済む道 | 「パネルマウント メス ⇔ オス」の延長ケーブル（AliExpress・chenyang CY 等）。**ただし 20〜30cm しか無く、ケース内に収まらない** |

> **⚠️ どのメーカーもプラグ本体の厚みを公表していない。**調べた範囲では 1 件も
> 見つからなかった（Adafruit も寸法表なし）。**買って測るしかない。**
> ここで「たぶん 5mm くらい」と書いて基板を作るのが、この案件で最も高くついた
> 失敗の型（実験用に別品番を買わせた件と同じ）。

**まだ確かめていないこと（ここが残りの危険）**

1. **プラグとケーブルは実在の製品ではない。**12×12×6mm・φ3.5mm は**仮定**。
   買う製品を決めて寸法を入れ直すまで、この結果は「その寸法なら入る」でしかない
2. パネル取付ジャックの本体と留め方（ネジかポケットか）を模っていない
3. 子基板の配線のやり直し（XIAO の向きが変わる）と、子基板側の銅の禁止域

**副産物**: 案 A ならアンテナが本体基板の下から出るので、
**本体基板の禁止域（左だけ入って右は入らなかった窓）が要らなくなる。**
左右の非対称も消える。

### 「決めた」と言うには、まだ足りない

CLAUDE.md の 3 条件のうち、**A について 3 つとも未了**：

1. 効く条件の全列挙 … USB ケーブルの曲げ半径・保持・抜き差しの力の受け方が未列挙
2. 影響範囲を端から端まで … `gen_assembly.py` を通していない。ボス高さを
   下げると FFC コネクタ（裏面 1mm）と床の隙間が減る。**その先を見ていない**
3. 何で確かめたか … ケーブルは**検索で存在を見ただけ**。買う型番・寸法は未確定

**だから、この節はまだ「解けた」と書かない。**

### 副産物: いまの子基板は、そもそもソケットが入らない（→ #27）

上の表のとおり子基板スタックの余裕は **0.13mm**。`DB_STACK_H = 4.5` は
**XIAO を直付けしたときの実測**で、仕様は「ピンソケットで交換可能」。
ソケット（約 2.5mm）を入れると **2.4mm 食い込む**。
**#23 を直すとき、同じ手で直すこと。**

## 18b. 買うときに確かめること

基板に載らないので JLCPCB とは無関係。一般の通販から選ぶ。

選ぶときの制約:

| | |
|---|---|
| 取付 | ケース背面のパネルに丸穴。**壁厚 2.4mm** に留められること |
| 接点 | SPST。電池のプラス側を切る |
| 定格 | 3V / 数十 mA。何でも足りる |
| **幅** | **左半分は背面の空きが 10.6mm しかない**（電池と子基板の間）。ここに収まること |
| 検査 | `envelopes.SW_PWR_W/D/H` に実寸を入れれば `test_the_power_switch_fits_on_the_rear_panel` が判定する。**目で見て決めない** |
| 端子 | はんだラグかリード線。基板の `SW_PWR_1` / `SW_PWR_2` へ配線する |

## 19. FFC ケーブルの向き（**2026-08-16 決着。A タイプ・80mm**）

### ✅ 2026-08-28 夜: J_DB の口を奥向きにした（A タイプで正しくなる）。**右の配線は引き直し待ち**

利用者「今の向きはダメ。あまりに不自然」「配線は最悪私がやり直すので、それ以外全部
進めて」。

**分かったこと（履歴）:** J_DB の向きは 2026-08-08 の初回配置から一度も変わって
いない。`gen_pcb` の配置表に向きの欄が無く、**`Flip()` の副作用の 180°**が
そのまま「口が手前向き」になった。08-10 の組立モデルはそれを所与として床への
折り下げ（幕）を作り、08-16 の #19 は「両端とも裏面＝下向き」だけで A タイプと
判断した。**誰も「なぜ手前向きか」を問わなかった。**

**直したこと:**

| 何 | どう |
|---|---|
| `circuit.py` J_DB のピン表 | **J_MAIN の鏡像（n ↔ 13-n）**。裏面のコネクタを 180° 回すとピン 1 が +X → −X に移り、まっすぐなケーブルでは同じ導体が 13-n 番に着くため。鏡像にすると各ネットのパッドの X は回す前と同じ位置に戻る |
| `test_the_two_boards_agree_on_the_cable` / `..._pinout_table_matches_the_circuit` | 鏡像を検査するように変更（決定文書の表は J_MAIN の番号と明記） |
| `gen_pcb.py` 配置表 | J_DB に向き 0°（口が奥）と dy を明記（左 −3.7 / 右 −0.4） |
| **左 `matrix_only`** | J_DB を 0° に回し、中心を 3.7mm 奥へ → **12 パッド全部が回す前と同じ座標**に来て**配線は無傷**。DRC **違反 0 / 未配線 0**。ただし利用者の枝とビア（SPARE/SPARE2/SCK/CS/V3V3）は**コネクタ本体の下**に入った（電気的には無害。#49 の露出は finalize が別の窓／ビアを選ぶ。**SPARE/SPARE2/SCK は露出できる銅が無い**） |
| **右 `matrix_only`** | 同じ 3.7mm は **SW10 の位置決め穴に当たる**（コートヤードに NPTH が入る。0.4mm までしか寄せられない）。0.4mm 奥・0° で置いた結果、**パッドが南側の枝・ビア（MOSI/CS/SCK/V3V3/GND/COL0・MP パッド）に重なり、違反 20・未配線 8（ROW_A〜E・SPARE・SPARE2・V3V3）**。**🔴 利用者が J_DB 周りを引き直す**（`pcb/matrix_only/hhkb_split_right.kicad_pcb`）。引いたら `export_matrix_routing.py → gen_pcb.py → finalize_pcb.py → drc.py → pcb_parts.py --write/--write-groups` |
| `gen_assembly.py` | 幕と床走行を消し、**口の直後の潜り（`FFC_DIVE` 2.0mm・暫定）＋ J_MAIN の口までの斜めの板**に置き換えた。箱モード 0・**実形状の干渉検査 左右とも 0**（2026-08-29 00:50）。断面図 `build/assembly/*_section_db.png` で経路を目視 |
| 回路図 | `gen_sch.py` で出し直し |
| #19 の結論 | **A タイプ・80mm で正しい**（経路が直線になったため）。買ってあるケーブルはそのまま使える |

**2026-08-30 午後: (a) を実施して決着。**右 J_DB を **1.63mm 手前**（中心 y=88.46・パッド y=90.31）へ動かし、
ソケットまで 3.9mm（FFC の出口の曲げ半径 ≈6mm・静的最小 1〜2mm の 3 倍）。利用者が南側の枝 12 本と
露出ビア（左右の SPARE/SPARE2 を南側／東側へ）を引き直し、私は MP パッドに当たった COL0 の迂回・
V3V3 の裏面残骸 2 本の削除・MOSI ビアの 0.15mm 移動・V3V3 ビア φ0.56（アニュラー 0.13 ちょうど）を当てた。
**3 基板とも DRC 違反 0 / 未配線 0。**同日夕方に利用者が左の SCK・CS・V3V3 にもビアを打ち（J_DB の東側に縦一列・ケーブルの幅の外）、**露出は左右の全ネットがビアに。検査 460 緑・赤 0。**

**右の引き直しで守ること:** 12 パッドの位置は `finalize` 後の `pcb/hhkb_split_right.kicad_pcb` の
J_DB（中心 (74.85, 86.825)・0°・パッド y=88.675）。ネットは鏡像の表（1 番 ROW_E … 12 番 GND）。
露出ビア（#49）は**コネクタの南側**（口の反対側・ケーブルが通らない側）に置くこと。

### 🔴 2026-08-28 再開: 経路に厚み方向の U ターンが 1 回あり、A タイプでは接点面が合わない

利用者「FFC も絶対に間違えてはいけない。複数視点でチェック」（fab-checklist §7）
を受けて幾何を追い直した。**下の「3 つが独立に一致」のうち「姿勢」の視点が
経路を見ていなかった。**

| 事実 | 出所 |
|---|---|
| FH12-xxS-0.5SH は**下接点**（FFC の導体が基板側を向く） | DigiKey 品目 FH12-8S-0.5SH(55)「Bottom contacts」／Hirose FH12 カタログ（FH12A が上接点） |
| J_DB・J_MAIN とも **B.Cu（基板の裏）**・回転 180°・パッドは奥側 → **口は手前向き** | `pcb/*.kicad_pcb`（`build/fab_check/pads.json`）＋ `gen_assembly.py` 316 行「J_DB（口は手前向き）から下りて床の上を這い、J_MAIN（口は手前向き）へ」 |
| 経路: J_DB を手前へ出る → 下へ折る → 床を奥へ → 上がる → J_MAIN へ奥向きに入る | 同上（`_ffc` の幕と走行部） |

**接点面を追う（紙のリボンで再現できる）:** J_DB では導体が上（基板側）を
向いて手前へ進む。手前→下→奥の **U ターンで面が反転**し、床では導体が下を向く。
床→上→奥の S 字（向きは変わらない）では面は戻らない。J_MAIN の口に着くとき
導体は**下向き**だが、J_MAIN も下接点で基板の裏なので**上向きが要る**。

→ **A タイプ（同面接点・導体まっすぐ）では両端を同時に満たせない。**
**B タイプ（両端で接点面が逆・導体まっすぐ）なら、ピン 1→1 のまま両端が合う**
（ネットの並びが J_DB/J_MAIN で一致していることとも整合）。
180° ひねりは面と一緒に 1↔12 も反転するので代用にならない。

**板は無傷**（コネクタも配線も変わらない）。変わるのは買うケーブルだけ。
**利用者の決定待ち**: (a) B タイプ 80mm を買う（最小）／(b) J_DB を 180° 回して
口を奥向きにし U ターンを無くす（基板の変更・発注前限定）。
**私は決めない。**§7 の視点 C（1:1 印刷に実物を渡す）で利用者が確かめてから。

コネクタは両端とも `Hirose FH12-12S-0.5SH`（JLCPCB 在庫あり・$0.68）で確定。

**ケーブルは A タイプ（同面）・12 芯 0.5mm ピッチ・80mm で確定**
（uxcell・20 本入り）。以前ここには「向きが未確定なので両向き 1 本ずつ買え」
と書いてあったが、**姿勢は CAD が既に決めていた**。読めば分かることを
「実際の引き回しで決まる」として未確定にしていた。

**A タイプで正しい根拠（3 つが独立に一致）:**

| | |
|---|---|
| 姿勢 | 本体基板は `TILT_DEG` = 7.3° で傾き、子基板は床に水平（`build/assembly/left_section_db.png`）。`J_DB`・`J_MAIN` とも B.Cu ＝ **両端とも下向き**。したがってケーブルは**ひねらずに**素直に渡る |
| ネット | `J_DB` と `J_MAIN` の pad 1..12 のネット並びが**完全一致**（鏡像ではない）。ひねらないから並びも反転しない |
| 実物 | 商品写真で**両端の補強板が同じ面**にあることを確認。補強板は接点の裏なので、接点も同じ面 |

**長さは 80mm。**必要 54.0mm（直線 29.0 ＋ `FFC_SLACK` 25.0）に対し余り 26mm。

- **50mm は 4mm 足りない。**端子に補強板があるので継げず、買い直しになる
- **100mm は 46mm 余る。**コブの中で折り返す量が増え、[#23](#23) の
  アンテナの近くで銅箔を余らせることになる
- 50/100 が主流の刻みだが、**80mm は実在した**

**FFC は平面方向（幅方向）には曲げられない。**導体が幅方向に並んでいるので
内周と外周の長さの差を吸収できず、座屈する。余りを逃がせるのは
**厚み方向の折り返しだけ**で、そこは本体基板が 7.3° で覆いかぶさっている。
「長くても曲げれば収まる」は成り立たない。

**残っているのは実測 2 つ** — リボンの実幅 → `FFC_RIBBON_W`（暫定 7.0mm）と、
`FFC_SLACK` 25.0mm（**未実測の見積もり**。垂直の落差・両端の曲げ・
抜け止めの遊び）。組んで測る。

## 24. 押した瞬間の 1 回だけ、列が全部 High のまま走査される（ZMK の実装）

**C2-b（2026-08-08）で ZMK の実装を読んで見つけた。実害は出ていないが、
理由が分かっていないと将来ゴーストと誤診する。**

`kscan_gpio_matrix.c` の割り込みハンドラは **ISR 文脈**で
`kscan_matrix_set_all_outputs(dev, 0)` を呼ぶ。ところが `gpio_595.c` は

```c
/* Can't do SPI bus operations from an ISR */
if (k_is_in_isr()) { return -EWOULDBLOCK; }
```

で必ず失敗する。戻り値は握り潰される。結果、**キーを押した直後の 1 回目の
走査だけ、列が待機状態の全 High のまま**始まる。列 0 を読んでいる間に列 1
以降も生きているので、原理上は押していない列のキーが混じりうる。

**なぜ実害が出ないか（実測で確認した）**

- 2 回目以降の走査では `kscan_matrix_read()` が列を 1 本ずつ立てて倒すので、
  この状態は続かない
- デバウンス（既定 5ms＝数回の一致が要る）が、この 1 回だけの異常な走査を
  落とす
- **実測: `a` `b` `c` `d` を 6 巡させて、他の列の文字は 1 回も出なかった**

**将来これを疑うべき症状** — 押していない**隣の列**の文字が混じる。
同じ文字の重複はこれではなく、チャタリング（下記）。

**逃げ道** — `CONFIG_ZMK_KSCAN_MATRIX_POLLING=y` にすれば割り込みを使わなく
なるので消える。ただし待機電流が増えるので、症状が出てから考える。

## 25. ブレッドボードのチャタリング（本番基板では未確認）

C2-a では `d`、C2-b では `c` で、**1 回押して 2 文字**出ることがあった。
C2-b の実測では 6 押しで 8 文字（`abcdabccdabcdabcdabcdabccd`）。

- **キーの取り違えではない。**同じ文字の重複なので、機械的なバウンスが
  デバウンス窓（既定 5ms）を超えて見えたということ
- 同じ試験で `a` `b` を 40 回速く叩いたときは重複ゼロ。**スイッチ個体か
  接触に固有**で、系統的なものではない
- 剥き出しのタクトスイッチと長いジャンパ線によるものと考えている。
  **本番基板で再現するかは未確認**

再現するなら ZMK の `debounce-press-ms` / `debounce-release-ms` で詰められる。

---

## 25b. 電池が尽きるときの止まり方（**ファームで直せる。基板は関係ない**）

> **⚠️ 2026-09-02 追記（発注前の電気監査で見つかった。基板は無関係）:**
> `firmware/src/low_battery_off.c` は「ZMK が測るたびに
> `zmk_battery_state_changed` が来る」前提で連続 2 回を数えるが、
> ZMK 本体の `app/src/battery.c` は **`last_state_of_charge != val1` の
> ときだけ**この事象を出す（外部事実・upstream main で確認）。%（9mV 刻み）
> が 0% に張り付くと 2 回目が来ず、**止まらない**。逆に BLE 送信の降下で
> 0〜10% が揺れれば偶然発火する。副作用として USB 給電・電源 OFF の
> 「0mV 連続」でも soft-off しないのは偶然の救い。
> **直し方の候補**: `CONFIG_ZMK_BATTERY_REPORT_INTERVAL` に相乗りする
> 自前タイマーで `sensor_channel_get` を読む／`SAMPLES=1` に落とす。
> [Task C4-4](task-c4-c5-power.md) の実機試験の前に直す。
> **✅ 2026-09-03 直した（ブランチ autonomous-20260903・コンパイル未確認）:**
> 事象の待ち受けをやめ、`ZMK_BATTERY_REPORT_INTERVAL` と同じ周期の自前
> `k_timer` → 低優先 work で driver のキャッシュを読む。最初の 1 周は待つ
> （ZMK が測る前はキャッシュが 0mV）。**USB 給電中は数えない**
> （スイッチ OFF＋USB で分圧が 0mV を返し、即 soft off になるため。
> `zmk_usb_is_powered()`・`CONFIG_ZMK_USB` があるときだけ）。
> ⚠️ 手元に SDK が無いので **CI（push）でビルドが通るまでは「書いた」だけ**。

BAT46W にしたので、**マイコンがマトリクスより先に落ちる**ようになった
（レール下限 1.80V はマイコン律速）。キーが 1 つずつ反応しなくなる壊れ方は
消えた。**ただし「マイコンが落ちる」の中身はまだ荒い。**

### 何が起きるか

レールが 1.7V を割ると nRF52840 はブラウンアウトでリセットする。電池は
負荷が消えると電圧が戻るので、**リセット → 起動 → 広告 → 電圧降下 →
リセット** を繰り返しうる。

| 起きること | なぜ困るか |
|---|---|
| 起動と広告の繰り返し | **残り少ない電池を早く使い切る** |
| 接続と切断の繰り返し | 使う側からは故障に見える |
| **低電圧での flash 書き込み** | nRF52840 の NVMC は VDD ≧ 1.7V が条件。
**ペアリング情報が壊れうる** |

### ✅ 2026-08-11 実装（**実機では未確認**）

**ZMK に電池電圧での停止機能は無い**（`CONFIG_ZMK_SLEEP` は無操作時のみ）
ので、自前モジュールに書いた。

[firmware/src/low_battery_off.c](../../firmware/src/low_battery_off.c)

| | |
|---|---|
| きっかけ | ~~ZMK が電池を測るたびに出す `zmk_battery_state_changed`~~ **2026-09-03: 同じ周期の自前タイマー**（上の追記。事象は % が変わったときしか出ない） |
| 読む値 | **その場で driver がキャッシュしている電圧**。ADC を余分に回さない |
| しきい値 | devicetree の `empty-millivolts` = **2400mV**。#13 の 0% と**同じ 1 つの数字** |
| 何回で止めるか | 既定 2 回連続（`CONFIG_HHKB_LOW_BATTERY_SOFT_OFF_SAMPLES`）。1 回で止めないのは、BLE 送信中に電池の内部抵抗ぶん一時的に下がるため |
| 止め方 | `zmk_pm_soft_off()` |
| 戻し方 | 電池を替えて背面の電源スイッチを入れ直す。**soft off の wake ピンには依存しない**（この設計は電池を機械的に切り離す） |

POFCON（nRF52840 の電源断コンパレータ）も検討したが、**採らなかった**。
分圧で電池電圧はもう読めており、ZMK の測定周期に相乗りすれば
新しい割り込み経路を持たずに済む。POFWARN が要るのは「落ちる直前に
数百 µs で片付ける」場合で、こちらは 60 秒周期で余裕をもって止める。

> **✅ ビルドは通った**（2026-08-11・Actions の「Build ZMK firmware」）。
> **ただし実機ではまだ動かしていない。**確かめるのは Task C4/C5
> （電池を実際に使い切る試験）。
> 「設定しただけでは効いていない」を踏まないよう、
> `tools/test_firmware.py` が **`CONFIG_ZMK_PM_SOFT_OFF=y` が左右とも
> 残っていること**を見張る（これが消えると機能ごと静かに消える）。

---

## 26. 片方が居ないと、もう片方が探し続けて電池を食う

**実測 3.7mA（2026-08-09・左半分だけで起動）。**
**右がつながっているときは 0.66mA なので、5.6 倍。**

**これはセントラル（左）だけの話。**ペリフェラル（右）は相手が居なくても
**0.11mA**（同日実測）。走査しないため。2000mAh で 2 年相当で、実質無害。
**気にするのは左だけ。**

ZMK のセントラル（左）は、ペリフェラル（右）が全部つながるまで
スキャンを止めない（[central.c](https://github.com/zmkfirmware/zmk/blob/main/app/src/split/bluetooth/central.c) の `start_scanning` / `stop_scanning`）。
Zephyr の既定は **30ms 受信 / 60ms 周期＝デューティ 50%** で、
nRF52840 の RX 4.6mA から**スキャンだけで 2.3mA 級**になる。

### いつ起きるか

- 右の電池が切れた／右のスイッチを切ったまま左を使う
- 右をまだペアリングしていない

このとき左は 2000mAh ÷ 3.7mA ≒ **22 日**で尽きる。
両方そろっていれば同じ条件で 126 日（4.1 ヶ月）なので、**寿命が 1/5.6 になる。**

### どこまで悪いか（**被害は限定される**）

**無操作 30 分で左も deep sleep に入り、スキャンごと止まる**
（`CONFIG_ZMK_SLEEP` / `CONFIG_ZMK_IDLE_SLEEP_TIMEOUT`）。
放置している間は食わない。**食うのは「使っているのに右が居ない」間だけ**で、
そのときは右が反応しないので使う側も気づく。

### 対応（**2026-08-11 に調べた: 私たちの側からは手が届かない**）

ZMK に「一定時間見つからなければスキャンを緩める」機能は無い。
必要なら `bt_le_scan_start` のパラメータを遅い側
（`BT_GAP_SCAN_SLOW_INTERVAL_1` = 1.28s 周期 / 11.25ms 窓＝デューティ 0.9%）
へ落とす改造になる。**発見が遅くなる代わりに 50 倍省エネ。**

**それが「改造」で済まないことを確かめた。**ZMK の該当箇所は

```c
/* app/src/split/bluetooth/central.c  start_scanning() */
int err = bt_le_scan_start(BT_LE_SCAN_PASSIVE, split_central_device_found);
```

で、`BT_LE_SCAN_PASSIVE` は Zephyr のマクロ（`BT_GAP_SCAN_FAST_INTERVAL` /
`BT_GAP_SCAN_FAST_WINDOW` を埋め込んだ静的な構造体）。
**Kconfig も devicetree の入口も無い**（`app/src/split/bluetooth/Kconfig` に
scan の項目は `select BT_SCAN_WITH_IDENTITY` だけ）。

つまり **[firmware/](../../firmware/) の自前モジュールからは変えられない。**
モジュールで足せるのは新しいコードであって、ZMK 本体の 1 行ではない。

| 道 | 代償 |
|---|---|
| ZMK を fork して `config/west.yml` の revision を自分の枝へ向ける | **上流に追従し続ける負担。**この案件はいま `revision: main` で追いかけている。分割・電池・シフトレジスタの全部が上流の更新に乗っている |
| 上流へ PR（スキャン間隔を Kconfig にする） | 取り込まれるかは相手次第。時間の見積もりが立たない |
| **やらない** | 左だけ・右が居ないときだけ 3.7mA。無操作 30 分で deep sleep に入るので、食うのは「使っているのに右が居ない」間だけ |

**いまは「やらない」。**#26 はもともと「急がない。実機ができてから、実際に
どれくらい起きるかを見て決める」項目で、**新しく分かったのは「安く直せる
方法は無い」**ということ。実機で本当に困ったら fork を検討する。

**C3 で両半分つないだときの電流（0.66mA）は測った。**寿命は 4.1〜11.6 ヶ月で
仕様を満たすので、**この項目は「片方が居ないときの劣化」だけの話**になった。
急がない。実機ができてから、実際にどれくらい起きるかを見て決める。

> **一度ここに #27「右を先に入れて 10 秒経つとつながらなくなる」を
> 書いたが、取り消した（2026-08-09）。**原因は電流計の負担電圧で、
> 製品の不具合ではなかった。経緯は
> [Task C3 の §5-5](task-c3-ble-split.md)。

## 27. ソケットは入る（「隙間 0.13mm で入らない」は保守平面の誤読だった・2026-08-11）

**利用者が組み立ての絵を見て「0.13mm にはとても見えない」と指摘し、
実形状で測り直して覆った。**この節は 2026-08-09〜10 の間、
嘘の制約で「直付けか薄プラグかの二択」を強いていた。

### 0.13mm の正体（何を間違えたか）

| 使った値 | 実際は |
|---|---|
| `pcb_bottom_at()` の 12.63mm を「子基板の真上の基板下端」とした | この関数は**ソケット深さ 3.2mm を全面一律に引く保守平面**。子基板の真上に**ソケットは 1 個も無い**（実際の基板下端は約 16mm） |
| `DB_STACK_H` 4.5mm の**全面の箱**の前縁と突き合わせた | 背の高い実物（XIAO）は子基板の**奥側**にあり、**XIAO の頭上に本体基板はそもそも無い**（XIAO 前端 y≈50.8 ／ 基板後端 y=48.95。案 C で XIAO を奥端へ寄せた帰結） |

**2 つの保守近似（一律の平面 × 全面の箱)の角どうしの衝突**であって、
実物の衝突ではなかった。`pcb_bottom_at()` の docstring に使用制限を書いた。
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

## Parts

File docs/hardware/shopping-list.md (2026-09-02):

# 買い物リスト（一般通販ぶん・2026-08-12 秋月集約）

**2026-08-12 追記:** 送料を支配的コストにしないため、**秋月電子で揃う物は
秋月に寄せた。**電源スイッチは「テスト用サンプル（¥25の別部品）」と
「本番品（Digi-Key/RS JP）」を分けていたのをやめ、**同じ秋月の部品
（SS12D01G4）をテストと本番の両方に使う案**に切り替えた（下の
「電源スイッチ候補比較」表と [open-gaps #18](open-gaps.md) 参照）。
**ただしアクチュエータの向きが背面パネルへ真っ直ぐ出せるかは現物確認前
なので「有力候補」であり確定ではない。**FFC ケーブル・M2 熱圧入インサート・
ゴム足（厚み 2mm 級）は秋月で探したが**見つからなかった**（各行に確認日を記載）。

> **2026-08-12 訂正:** 当初は同系列の SS-12D00G3（¥20）を「安いから」
> 主候補にしたが、**価格差（¥10/個。数量分でも数百円程度）に対して
> 接触抵抗の差（100mΩ vs 30mΩ）を軽視していた**（1つの軸だけで選んでいた）。外形・定格は
> 同等で実差は接触抵抗のみ、かつ #18 で懸念している経年の硫化膜劣化への
> 余裕という観点では低いほうが望ましいため、**主候補を SS12D01G4 へ変更**。
> SS-12D00G3 は次点で残す。

> **2026-08-12 さらに追記（5セット分ストック方針）:** JLCPCB の基板は
> 5枚単位でしか発注できない（[cost-estimate.md](cost-estimate.md#4-1-実装するのは-2-セットでよい約-2700)）。
> 未実装の基板は 0.5mm ピッチ FFC の手半田が現実的でなく**事実上捨てるのと
> 同じ**なので、実装は2→5セットへ増やす方向で検討している。**ただし
> これはPCB実装（JLCPCB側のBOM）だけの話で、この秋月の一般部品リストとは
> 独立**（電池ボックス・スイッチ・ネジはJLCPCBの実装BOMに入っていない）。
> それでも「秋月分の注文額が¥1,000にも満たず送料の方が高い」という
> 別の理由から、**送料を1回で済ませるために秋月の一般部品も5セット分を
> まとめ買いする**ことにした。数量は下の「0. 今回まとめて発注する数量」参照。
> **キーキャップ・MXスイッチ等、秋月に無く別便が要る部品はこの対象外**
> （2台目以降を実際に組む時にまとめて買う。詳細は #22 の議論参照）。
> **ピンソケットのように「プロトタイプ期のみ」の道具は5倍にしない**
> （本番は直付け確定＝#27 なので2台目以降には使わない）。

**JLCPCB へ発注する部品はここに入れない**（それは
[cost-estimate.md](cost-estimate.md) と `tools/jlcpcb_lookup.py --parts`）。
ここは**利用者が一般の通販で買う物**の一覧。

**このリストの作法（#22 の再発防止）:**

- 「電池ボックス 単3×2」のような**種類だけの行を作らない。**型番まで書く。
  型番が未定の行は「**品番未定**」の節に置き、**買う前に決める**
  （CLAUDE.md: 実験用に別品番を買わせない）
- 各行に**出所（決めた文書）**と**届いたら確かめること**を書く。
  確かめる先は [provisional-values.md](provisional-values.md) の定数
- 書き足すとき・買うときは、**出所の文書と突き合わせる**。リストだけを
  信じない（#22 は「箱」とだけ書いたリストが横並び型を買わせた）

---

## 0. 今回まとめて発注する数量（5セット分ストック方針・2026-08-12）

**これが実際に発注する数量です。**各行の背景・効く条件は節1以降を参照。

| 品名 | 型番・秋月コード | 数量 | 単価 | 小計 |
|---|---|---|---|---|
| 電池ボックス（スイッチ無し） | BH-325-1A150・**110201** | **8**（通販在庫の上限） | ¥60 | ¥480 |
| 電池ボックス（スイッチ付・不足分） | BH-325AS150・**110202** | **2**（8個では5セット分＝10個に2個足りない分） | ¥30 | ¥60 |
| 電源スイッチ（**✅ 決定**・テスト兼本番） | SS12D01G4-G・**112723** | **14**（本番 2×5セット＝10 ＋ 共有予備 3 ＋ 現物確認用 1） | ¥30 | ¥420 |
| M2ネジ 12mm | なべ小ねじ(+)・**131202** | **3パック**(30個＝6本×5セット) | ¥70 | ¥210 |
| M2ネジ 5mm | なべ小ねじ(+)・**115887** | **9パック**(90個＝(14+4)本×5セット。節1の本体基板止めと節2のケース用を合算) | ¥100 | ¥900 |
| ピンソケット 1×40メス | FHU-1x40SG-Y・**110302** | **1〜2**（据え置き。プロトタイプ期のみの道具なので5倍にしない） | ¥100 | ¥100〜200 |

**合計: 約¥2,170〜2,270**（送料1回分）

⚠️ 電源スイッチは **2026-08-12 に決定**（SS12D01G4-G。突出量 4.0mm を図面と
商品ページの両方で確認。残るのは届いてからのノギス実測だけ）。
スイッチ付き電池ボックス（110202）は
組立時に**内蔵スイッチをON位置に固定**（ホットボンドかテープ。**はんだ付けはしない**
——ケースがPP樹脂で融点が低く、こて熱でリベット根本が変形するリスクがある）
し、**現物でON時にケース輪郭からはみ出さないかノギスで確認する。**

## 1. 型番まで確定している（いつでも買える）

| 何 | 型番 | 数 | 店・価格 | 出所 | 届いたら確かめること |
|---|---|---|---|---|---|
| 電池ボックス（単3×2・たて一列・リード線・**スイッチ無し**） | **BH-325-1A150** | **8**（1台分は2。5セット分ストックのため通販在庫上限まで購入） | 秋月 販売コード **110201**・¥60/個・**通販在庫8個のみ**（実店舗は取り寄せ） | [open-gaps #22](open-gaps.md)（2026-08-11 決定） | ノギスで `BATT_BOX_L/W/H`（記載 109 × 16.6 × 16.8mm）。長辺が伸びていたら電源スイッチの窓（左 10.56mm）を食う |
| 電池ボックス（同上・**スイッチ付・110201の在庫不足分**） | **BH-325AS150** | **2**（5セット分＝10個のうち110201で賄えない分） | 秋月 販売コード **110202**・¥60→**¥30/個**（安く在庫764個。2026-08-12発見） | [open-gaps #22](open-gaps.md) ＋ 2026-08-12 データシート(BH-325AS.pdf)図面確認 | 寸法は109×16.6×**14mm**（110201より低い）。**内蔵スイッチは使わない**——組立時にON位置へ回してホットボンドかテープで固定（**はんだ付けは不可**。PP樹脂ケースが融けるリスク）。ON位置でタブがケース輪郭からはみ出さないか、導通しているかをノギス・テスターで確認 |
| 電源スイッチ（**✅ 2026-08-12 決定。**秋月に一本化。テストと本番を同じ品番で） | **SS12D01G4-G**（秋月 販売コード **112723**） | **14**（本番 2×5セット＝10 ＋ 共有予備 3 ＋ 現物確認用 1。5セット分ストック方針） | 秋月 **¥30/個**・在庫あり（15,062 個） | [open-gaps #18](open-gaps.md) ＋ 今回の秋月商品ページ・データシート確認（2026-08-12） | **✅ 決定済み。**突出量は **4.0mm**（図面 `L 4` と商品ページが一致）。**向きの懸念は消えた**——基板に載せないので基板とパネルの位置関係が生じない。残るのは実測: ノギスで `SW_PWR_*` を更新／新品の接触抵抗（データシート値 30mΩ MAX）／`SW_PWR_W/D/H` を実測値で更新 |
| M2 ネジ（**本体基板をプレートの柱へ締める**） | **M2×5mm なべ・タッピング可**（下穴 φ1.6 の PLA へ直接） | **左 6 ＋ 右 8 ＝ 14 本／セット**（1セット分。5セット分＝70本は節2の同型ネジと合算して秋月115887を9パック購入——節0参照） | 秋月「なべ小ねじ(+) M2×5」**115887**・¥100/10個入 | [open-gaps #36](open-gaps.md)（2026-08-12 決定） | **頭の径 ≦3.8mm・高さ ≦1.6mm**（基板の裏に出るので、ソケットの 3.2mm より低いこと）／長さ 5mm で板 1.6 を貫いて柱へ 3.4mm 噛む |
| FFC ケーブル（12 芯・0.5mm ピッチ・**80mm**） | **A タイプ（同面）のみ**（2026-08-16 確定） | 1（20 本入り） | Amazon・uxcell 20 本入り（**秋月には無い**——60P や 6/10P の DIP 化キット、20P ハーフピッチ IDC はあるが 12 芯 0.5mm ピッチの単品は無い。2026-08-12 確認） | [open-gaps #19](open-gaps.md) | **向きは確定済み**（2026-08-28 に J_DB の口を奥向きへ直して経路を直線にした。A タイプで正しい）。残りはリボンの実幅 → `FFC_RIBBON_W` と、`FFC_SLACK` 25mm の実測。**必要長は左右とも 29.0mm ＋ 余裕 25.0 = 54.0mm**。⚠️ **2026-08-31 調査: 80mm・A タイプ・12 芯 の 3 つが揃う品は多くない。**Amazon の uxcell は 12 芯だと **B タイプ 50mm** や **A タイプ 150mm** が主で、**80mm A タイプは在庫が入れ替わる**。国内の代替として [千石電商](https://www.sengoku.co.jp/mod/sgk_cart/detail.php?code=7BKT-RPH7) に **A タイプ 0.5mm 12Pin 150mm** がある。⚠️ **ただし 150mm は余りが 96mm**（必要 54mm）で、**アンテナの近くで銅箔を折り返す量が増える**（#23 の懸念）。**50mm は 4mm 足りず継げない**（端子に補強板がある）。→ **80mm を見つけたら確保する。**無ければ 150mm を買って「余りをどこへ逃がすか」を先に決めること |
| ピンソケット（XIAO を着脱可にする・**プロトタイプ期のみ**） | **分割ロングピンソケット(メス) 1×40(40P)・黄**（座高 8.5mm ピッタリ明記。低背は不可——手持ちヘッダのピンが 5.5mm あり座らない） | 1〜2 本（1×7 を 4 本取る） | 秋月 **FHU-1x40SG-Y**・販売コード **110302**・¥100/本 | [open-gaps #27](open-gaps.md)（2026-08-12 決定）＋秋月商品ページ確認（2026-08-12） | **座高をノギスで測って `DB_SOCKET_SEAT` へ**（挿した状態で「子基板の上面→XIAO の基板下面」を測る）／差すと `usb_center_z` が動くので**ケースを刷り直す** |
| キーキャップ高さのサンプル（上 2 段の品番決定用） | **SP 直販 SA Row 1 / Row 2 / Row 3・1u ブランク** | 各 1 | Signature Plastics 直販・$3/個 ＋ 送料 | [open-gaps #21](open-gaps.md)（候補調査 2026-08-11） | `tools/gen_testpieces.py` の `height_gauge.stl` と並べて実測。Row 2 が 10.8〜11.4mm に入れば数字段・QWERTY 段とも SA 単品買いで完結しうる |

### 電源スイッチ候補比較（2026-08-12・秋月の商品ページ／データシート実物確認）

**効く条件を先に列挙:** ①枠 10.6(幅)×15.6(奥行)×15.5(高さ)mm に収まるか
~~②アクチュエータの向き・突出量~~ **→ 2026-08-12 に解決**（突出量 4.0mm。向きは基板に載せないので問題にならない）
③接点材質 ④接触抵抗 ⑤定格（3.3V・15mA に対して十分か）⑥端子形状
⑦価格・秋月での即納性。

| 型番（秋月コード） | ①外形寸法 | ②アクチュエータ | ③接点材質 | ④接触抵抗 | ⑤定格 | ⑥端子 | ⑦価格・在庫 | 確認手段 |
|---|---|---|---|---|---|---|---|---|
| **SS12D01G4-G**（112723） | 本体 8.8×3.9mm・全高 7.4mm（データシート） | 上面スライド、つまみ突出 約3.9mm | Ag メッキ（データシート：Frame Ni plated / Terminal・Contact clip Ag plated） | **30mΩ MAX**（候補中最良） | 50VDC/0.3A（3.3V/15mA に余裕） | スルーホール・ピン | ¥30・在庫 15,062 個（即納） | 秋月商品ページ＋メーカー（Switronic）データシート PDF を実際に開いて確認 |
| SS-12D00G3（115707・次点。価格最優先ならこちら） | 本体 8.5×3.7mm・全高 7.4mm（データシート。SS12D01G4 とほぼ同型・同一系列） | 同上、つまみ突出 約3.9mm（全高 7.4 − 本体高 3.5、データシート実測換算） | Ag（銀）メッキ（データシート材質欄：接点＝ブロンズ Ag plated） | 100mΩ MAX（SS12D01G4 より劣る） | 30VDC/0.3A | スルーホール・ピン | **¥20**・在庫 8,753 個（即納） | 同上（廈門金倍利データシート PDF） |
| ESD175202（108944・Panasonic） | 長辺11.5×短辺5.0mm、取付高さ5.0mm（メーカー参考資料） | 横形、レバー長さ（突出量）**4.0mm**（型番末尾"02"で規定） | **データシートに記載なし**（接点材質・接触抵抗とも本ページ・参考資料に数値なし） | 不明 | 3VDC/50µA〜30VDC/0.1A | スルーホール・ピン | ¥30・在庫 3,351 個（即納） | 秋月商品ページ＋Panasonic 参考資料 PDF（型番構成表・寸法図まで確認、電気仕様の一部は未公開） |
| SK-12D11VG3（115703・従来のテスト用サンプル） | 長辺8.7×短辺3.0mm | 横向き、突出量はページに記載なし | 記載なし | 100mΩ | 30VDC/0.3A | スルーホール・ピン | ¥25・**「9月中旬入荷予定」で即納不可**（2026-08-12 時点） | 秋月商品ページ実物確認 |
| IS-2235-G（102627） | 長辺9.0×短辺3.6mm | 突出量記載なし。2回路2接点（今回は不要な多回路） | 記載なし | 70mΩ | 3.3VDC/0.01A〜6VDC/0.3A | スルーホール・ピン | ¥110/4個入（実質¥27.5/個）・4個単位でしか買えない | 秋月商品ページ実物確認 |
| SK-22H09G5（115702） | 長辺14.1×短辺8.5mm。2回路2接点で他候補よりだいぶ大きい | レバー長さ5.0mm | 記載なし | 100mΩ | 30VDC/0.3A | スルーホール・ピン | ¥35・在庫 2,750 個 | 秋月商品ページ実物確認 |

**絞り込みの結論:** **SS12D01G4 を、テストと本番を兼ねる有力候補とする。**
理由（4 条件とも満たす）——①寸法が枠に対して大きく余る、②突出量が
設計要求の 3.4〜4.0mm レンジにデータシート上合致する、④接触抵抗が
候補中で最良（30mΩ MAX）、⑦秋月で即納・在庫豊富。**テスト専用だった
SK-12D11VG3（¥25）は廃止できる**（在庫も9月中旬までない）。

> 当初「価格が安い」だけで同系列の SS-12D00G3（¥20・接触抵抗100mΩ）を
> 主候補にしていたが、**1つの軸（価格）だけで選んでいた**。14個買っても
> 価格差は¥140でプロジェクト全体からすれば無視できる規模であるのに対し、
> 接触抵抗の差（100mΩ→30mΩ）は #18 で懸念している経年の硫化膜劣化への
> 余裕という観点で無視できない。**支配的な条件（接触抵抗）を、確かめやすい
> 条件（価格）より軽視していた**ため訂正した。SS-12D00G3 は価格を最優先
> したい場合の次点として残す。

### ✅ 2026-08-12 確定（利用者が品番を決定）

**SS12D01G4-G（秋月 112723）で確定。**データシート（SWITRONIC V2.3）と
秋月の商品ページの両方から寸法を取った。**2 つの出所が一致している。**

| | 値 | 出所 |
|---|---:|---|
| 本体（壁に当たる面） | 8.8 × 3.9 | 図面・商品ページ |
| 本体の高さ（座面から） | 3.5 | 図面 |
| **ツマミの突出量** | **4.0** | 図面 `L 4` ／ 商品ページ「操作部長さ 4mm」 |
| 本体＋ツマミ | 7.5 | 商品ページ「長さ 7.5mm」（3.5 + 4.0 と一致） |
| ツマミの幅 / ストローク | 1.5 / 2.0 | 図面 |
| 端子 | 3 本・2.5 ピッチ・0.5 × 0.3・長さ 5.0 | 図面・商品ページ |
| 定格 / 操作力 / 寿命 | 50VDC 0.3A / 200±80gf / 1 万回 | 図面 |

**「アクチュエータの向き」の懸念は消えた。**この設計では**スイッチを
基板に載せない**（奥の壁のポケットへ落とし込み、リード線で基板の
ランドへ繋ぐ。open-gaps #17）。**PCB とパネルの位置関係という問題が
そもそも発生しない。**本体の上面（8.8 × 3.9）を壁の内面に当て、ツマミが
壁のスロットから出て、端子は case の内側を向く。

**突出量 4.0mm は要求を満たす。**壁 2.4 − 指の窪み 1.0 = 1.4mm を貫いて
**外へ 2.6mm 出る**（要求は外へ 1.0mm 以上）。#18 の「2.8 説と 4.0 説で
合否が分かれる」問題は、**この品番では起きない。**

**★まだ確定していないこと（現物が無いと分からない）:**
- 寸法はすべて**図面と商品ページの値**であり、実測ではない
  （届いたらノギスで `SW_PWR_*` を入れ直す）
- 経年の硫化膜懸念（#18 参照）は SS12D01G4 でも同様に残る（銀メッキ・
  スライドでセルフクリーニングする前提は変わらない。接触抵抗が低い
  ぶん初期マージンはあるが、劣化そのものを防ぐわけではない）

→ **2026-08-12 に決定。**C&K OS102011MA1QN1 への差し戻しは無くなったので、
Digi-Key / RS JP への別便も不要。**秋月 1 便にまとまった。**

## 自分で買う部品の「代わりが効くか」（2026-09-01 調査）

JLCPCB の 7 品番は別途 [fab-checklist §2c](fab-checklist.md) で見た。
ここは**自分で買う側**。**在庫があるかだけでなく、切れたときに
代わりが効くか**まで見る（スタビの 3u で「理屈上は買えるが現実には無い」を
踏んだので、同じ型を全部潰す）。

| 部品 | 代わり | 危険度 |
|---|---|---|
| **FFC ケーブル 12芯/0.5mm/80mm/A タイプ** | **効きにくい。****3 条件が揃う品が限られる。**国内の代替 [千石電商 150mm A タイプ](https://www.sengoku.co.jp/mod/sgk_cart/detail.php?code=7BKT-RPH7) ¥430 は **「在庫限り」**（＝終売の見込み）。**150mm だと余り 96mm がアンテナ近くで折り返す**（#23 の懸念）。**50mm は 4mm 足りず継げない** | **★★ 高** |
| キーキャップ 上 2 段 | **未確定。**±0.3mm で合う品が無く、SP の SA Row 1/2/3 を買って実測してから決める | 中 |
| 電池ボックス BH-325-1A150 | 代替あり（BH-325AS150・スイッチ付・**2.8mm 低い**）。ただし**本命の在庫が 8 個**で 5 セット分 10 個に足りず、**不足 2 個は代替になる** | 中 |
| ゴム足 | **未確定。**`RUBBER_T` が決まるまで選べない | 中 |
| キーキャップ 下 3 段 DSA | 効く。DSA は各社にある。**2.75u スペースは経路が 2 つ**（SP 直販 $4・遊舎工房セット ¥1,980） | 低 |
| **スタビ 2u ×4** | **効く。国内潤沢**（遊舎工房 ¥220/個ほか。**3u をやめたので楽になった**） | 低 |
| MX キースイッチ | 効く。**530 種類以上**から選べ、ホットスワップなので後から替えられる | 低 |
| 電源スイッチ SS12D01G4-G | 秋月在庫 15,062。潤沢 | 低 |
| M2 ネジ・熱圧入インサート | 潤沢（Amazon・モノタロウ・ミスミほか） | 低 |

**→ 自分で買う側でいちばん危ないのは FFC ケーブル。**
**基板の発注はせき止めないが、これが無いと左右が繋がらない。**
**80mm A タイプを見つけたら確保すること。**

## 2. 品番未定（**買う前にここを埋める。**種類だけで買わない）

| 何 | 数 | 効く条件（これを満たす品を探す） | 出所 |
|---|---|---|---|
| DSA ブランクキャップ（下 3 段） | 1u ×必要数・1.5u/1.75u/2.25u・**2.75u スペースバー ×2**（2026-08-31 に 3u から変更） | ホーム段高さ 6.7〜7.6mm が成立の条件。**まず 1 個買って `CAP_H_HOME`（公称 7.6 / SP 図面 7.39）を実測**してから数を買う。**スペースは 2.75u ×2**（2026-08-31 に 3u から変更。スタビの都合）。**2.75u のキャップは 2 経路ある**: [Signature Plastics DSA 2.75u スペース](https://spkeyboards.com/products/sp-dsa-2-75-space) $4.00・1 個単位・**在庫あり/日本発送可**（DSA で揃うのでこちらが本命）、または [遊舎工房 スペースバーセット](https://shop.yushakobo.jp/en/products/10263) ¥1,980・在庫 14・**2.75u が ×2 入る**（必要数ちょうど・分割配列向けと明記）——ただし **Cherry プロファイル**なので下 3 段の DSA と形と高さが変わる。⚠️ TALP の「DSAライク Space2.75U」は商品ページが **404**（終売と見られる）。**SKU 記載の高さで判断。**TALP の「XDA」は約 8.5mm と通説と 0.6mm 違った。1.5u/1.75u/2.25u も SP 直販で単品・在庫あり（2026-09-02 確認。open-gaps #21）。**秋月では扱いなし**（MX用キーキャップ自体を非取扱。2026-08-12 確認）→ TALP／遊舎工房／SP直販のまま | [open-gaps #21](open-gaps.md) |
| 上 2 段のキャップ本番ぶん | 数字段 1u×13 ほか | **上のサンプル実測の結果で決める。**要求は数字段 11.12mm / QWERTY 9.16mm（±0.3mm）。**秋月では扱いなし**（同上）→ 現状維持 | 同上 |
| MX キースイッチ | 61 ＋ 予備 | **買う前に下の「スイッチを買うときに見ること」を読む。**ホットスワップなので後から替えられる（打鍵感は交渉可能事項）。届いたら `SW_BODY_W`（15.6）/ `SW_UNDER_W`（14.0）を実測。**秋月では扱いなし**（内部検索でMX軸のキースイッチは非ヒット。2026-08-12 確認）→ 遊舎工房等のまま | [open-gaps #29](open-gaps.md) |

### スイッチを買うときに見ること（2026-08-23・利用者の質問から）

**ソケットは JLCPCB が実装してくる**ので、届いた基板にスイッチを**手で挿す**
だけ（はんだ付けではない）。**合わなければ挿さらないだけで、基板は無傷。**

**見るのは金属端子の位置だけ。**いまのソケット（CPG151101S11）が受けるのは:

| | キー中心から |
|---|---|
| 金属端子 1 | **(−3.81, −2.54) mm** |
| 金属端子 2 | **(+2.54, −5.08) mm** |
| 2 本の間隔 | **x 6.35mm / y 2.54mm**（Cherry MX の規格値。**斜めにずれて並ぶ**） |

#### ⚠️ 「MX 互換」だけでは足りない

**ステムの形（キーキャップ用）と金属端子の位置（ソケット用）は独立している。**
同じ「MX 互換」という言葉が、スイッチの説明では端子を、キーキャップの
説明ではステム受けを指す。**別のものを同じ言葉で呼んでいる。**

**いちばん危ないのは Kailh Choc V2。****MX 互換の十字ステムを持つ**ので
「MX 互換」と書かれていることがあるが、**端子が全く別で刺さらない。**

#### 判定は「高さ」でつく

| | 高さ | |
|---|---|---|
| **MX（正解）** | **約 14mm** | 本体も約 14mm 角 |
| **低背**（Choc V1/V2・Gateron KS-27・Cherry MX Low Profile） | **約 8.8mm** | **明らかに薄い。刺さらない** |

**5mm 以上違うので写真でも一目で分かる。**「薄い」と感じたら低背。

#### チェックリスト

1. **高さ約 14mm**（薄いものは全部だめ）
2. 「Cherry MX 互換」＋「**ホットスワップ対応**」の記載
3. 「低背」「ロープロファイル」「Low Profile」「Choc」の語が**無い**こと
4. 光学式・磁気式（Hall Effect）・Alps・Topre は**別物**

**これを満たせば 530 種類以上から選べる**（Cherry / Gateron / Kailh /
Outemu / TTC / Akko / HMX ほか）。**単価 $0.20〜0.80**。
**ソケット選定が入手性・価格を狭めてはいない。**

⚠️ **3 ピンでも 5 ピンでもよい。**φ1.75 の穴が開けてあるので 5 ピンの
プラスチック突起もそのまま挿さる（[open-gaps #50](open-gaps.md) 参照）。
| スタビライザ（PCB マウント） | **2u ×4**（2026-08-31 にスペースを 2.75u にしたので 3u は不要） | **2026-08-31 調査。下の「スタビの選び方」を見ること。**要は ①PCB マウント（プレートマウント不可）②Cherry MX 互換 ③2u。~~3u が入手の難所~~（2u+6.25u のセットばかりで 3u 単品が少ない → **だから 2.75u にした**）。**秋月では扱いなし**（2026-08-12 確認） | [open-gaps #30](open-gaps.md) |
| M2 熱圧入インサート | 10（本体 3×2＋子基板 2×2＋予備） | **外径 3.2mm・長さ ≤ 5.0mm**（子基板のボスは 5.0mm しか掘っていない → `M2_INSERT_L`）。**秋月では扱いなし**（M2 ナット・M2 ネジ・M2 プラスチックスペーサーは複数あるが、熱圧入インサートそのものは無い。2026-08-12 に商品検索で再確認）。**2026-08-31 調査: 入手性は問題なし。**Amazon・モノタロウ・ミスミ・楽天・WILCO・ヒロスギに多数。Amazon には**半田ごて（温調付）と M2〜M8 のチップが一式になったセット**もあり、**圧入には温調こてが要る**ので道具ごと揃うほうが早い。⚠️ **買うときは外径 3.2mm・長さ ≤5.0mm を満たす品を選ぶこと**（M2 なら外径 3.2〜4.0mm の品が混在する。子基板のボスは 5.0mm しか掘っていない → `M2_INSERT_L`） | [open-gaps #10](open-gaps.md) |
| M2 ネジ（なべ）**→ 秋月で品番確定** | 12mm ×6・5mm ×4 ＋予備（1セット分。5セット分は節0参照） | 長さは `SCREW_L_MAIN` 12.0 / `SCREW_L_DB` 5.0（候補値。**買う前に組図で確認**）。頭 φ→`SCREW_HEAD_D/H`。**秋月候補**: 12mm＝「なべ小ねじ(+) M2×12」**秋月131202**・黄銅・¥70/10個入。5mm＝「なべ小ねじ(+) M2×5」**秋月115887**・黄銅・¥100/10個入（節1の本体基板止め用と同じ品番。5セット分は合算して9パック購入——節0参照）（2026-08-12 商品ページ確認） | provisional-values |
| ゴム足 | 4（左右 ×2） | **厚み ＞ 0.6mm**（座ぐりより薄いと接地しない。`test_the_rubber_feet_actually_touch_the_desk`）。厚みは 0° の高さとチルト脚に揃える → `RUBBER_T`（暫定 2.0mm）。**秋月候補（いずれも `RUBBER_T` 暫定 2.0mm より厚い。寸法確定後に選ぶ）**: (a)「ゴム足(丸) RF-018」**秋月107585**・¥100/4個入・外径22.3×高さ9.8mm、(b)「丸型ゴム足」**秋月116317**・¥120/8個入・外径11×高さ7mm、(c)「接着シール付き透明ゴムクッション」**秋月110080**・¥60/4個入・外径10×高さ5mm——**厚みが一番`RUBBER_T`に近いのは(c)**だが、まだ2.5mm厚い。`RUBBER_T` が確定するまでどれにも決めない（2026-08-12 商品ページ確認） | [open-gaps #29](open-gaps.md) |

## スタビライザーの選び方（2026-08-31・**3u 問題は設計変更で解決した**）

### ★ 結論: **2u を 4 個買うだけ。**3u は要らない

**元は 2.25u ×2（左Shift・Enter）＋ 3u ×2（スペース）だったが、
3u のスタビが国内で買えないことが分かったので、
2026-08-31 に**スペースキーを 3u → 2.75u に変更**した（利用者の判断）。
Cherry 規格では **2u / 2.25u / 2.5u / 2.75u が同じスタビ**（支点 ±11.938）なので、
**4 個すべて「2u」で足りる。**

| 要るもの | 数 | 使う場所 |
|---|---|---|
| **Cherry MX PCB マウント 2U** | **4** | 左Shift(2.25u)・Enter(2.25u)・L-Space(2.75u)・R-Space(2.75u) |

### 仕様にこの 3 つが書かれていれば OK

| # | 条件 | 仕様欄の書かれ方 | これを外すと |
|---|---|---|---|
| 1 | **PCB マウント** | 「PCB Mount」「PCBマウント」「基板取り付け」 | **プレートマウントは付かない。**基板の穴を使わない |
| 2 | **Cherry MX 互換** | 「Cherry MX」「MX 互換」「Cherry compatible」 | Choc / ロープロ / Alps は穴が別 |
| 3 | **2U** | 「2U」 | — |

**「Cherry MX PCB マウント 2U」と書いてあれば挿さる。**
ブランド（Durock / Everglide / Gateron / ノーブランド）は問わない。安い互換品でよい。

⚠️ **「2.25u 用」「2.75u 用」という商品は存在しない。**探しても見つからないのは
規格上 2u と同じ部品だから。上流フットプリントの説明文にもそう書いてある
（`descr "Cherry MX PCB Stabilizer 2.00u 2.25u 2.50u 2.75u"`）。

### 買える店（国内・2026-08-31 調査）

| 店 | 何 | 価格 | 在庫 |
|---|---|---|---|
| **遊舎工房 [a0500st](https://shop.yushakobo.jp/products/a0500st)** | ノーブランド PCB スナップイン **2U×1** | **¥220/個** | **10**（要 4） |
| 遊舎工房 GDK-02 | PCB マウント（ルブ済） | ¥770 | 558 |
| 遊舎工房「MXスイッチ スタビライザー」 | 2U ほか | ¥165〜 | 84 |
| Amazon | Durock V2/V3・Owlab V3 等の **2u 入りセット** | 数千円 | 多数 |

**2u は国内で潤沢。**⚠️ 遊舎工房 a0500st は在庫 10 個なので早めに。

### ⚠️ ネジ込み式（Screw-in）について — **未確認のまま**

ネジ込み式のほうが品質は上だが、**この基板の穴で使えるかを確認できていない。**
下穴は φ3.9878 でネジ込み式が使う穴とほぼ同径だが、
**メーカー・販売店・上流ライブラリのいずれも「スナップ式と穴が共通か」を
明記しておらず、外部の一次情報で裏が取れなかった。**
**確実なのはクリップ式（スナップイン）。**ネジ込み式を使いたいなら
買う前に販売店へ「Cherry MX PCB マウントの標準穴で使えるか」を問うこと。

### 届いたら測ること（`STAB_PAD` の確定）

| 測るもの | 基準 | 外れたら |
|---|---|---|
| ハウジングの幅 | **7.10mm 以下**（モデル 6.804 ＋ 逃げ 0.15×2） | プレート開口に当たる → `STAB_PAD` に差を入れて再検査 |
| ハウジングの前後 | 19.2mm 前後 | 同上 |
| ワイヤの向き | 挿子が手前か奥か | 実形状の干渉検査に効く |

### 記録: なぜ 3u をやめたか（2026-08-31）

**3u は国内で買えなかった。**遊舎工房のスタビ一覧に 3U 無し。
TALP は DUROCK 3U V3 の商品ページが **404**（終売と見られる）、
スタビ一覧も在庫切れ 2 件で 3U 無し。**Amazon も 3u 無し**（2u/6.25u/7u のみ）。
海外専門店（MechWild $1.00・CannonKeys $3.75/5本 ほか）にはあるが、
**調べた 4 店のうち 3 店が品切れ・1 店が注文停止中**だった。

**「ワイヤーだけ 3u 用に替える」案も検討したが取り下げた。**
ワイヤーは平らな針金ではなく両端が L 字に曲がっており（モデルの bbox が
2u/3u とも奥行 10.75mm・高さ 7.63mm で同じ＝端の曲げは共通、
中央の直線部の長さだけが違う）、**切るだけでは「片側だけ L 字が付いた棒」に
なる。**曲げ直しにはピアノ線の曲げ加工が要り、KeebTalk / deskthority を見ても
**「自作した」という完成報告が無い**（専用工具を挙げる人はいるが本人が
「試していない」と書いている）。

**→ キー幅を 2.75u にするほうが確実。**実機からのずれは片側 4.76mm だけで、
**2u スタビが使える最大の幅**なのでずれが最小。~~縮めたのは**内側だけ**なので
他のキーは 1 つも動かず、キーどうしの隙間もできない。~~ **2026-09-02 訂正:**
外側（Alt/Meta 側）に寄せたのは誤りで、利用者の指摘で**両島の内側端**に寄せ直した
（左 4.5〜7.25u・右 9.75〜12.5u）。Alt/Meta は原機の位置のまま、Meta とスペースの
間に空き（左右とも 0.5u）ができる。→ [open-gaps #56](open-gaps.md)

## 3. 条件付き（**#23 の手 0 の測定結果が出るまで買わない**）

| 条件 | 何 | 型番・店 | 出所 |
|---|---|---|---|
| 案 A（XIAO 反転＋内部延長）を採る場合 | パネル取付 USB-C メス | **秋月済み確定**: AE-USB2.0-TYPE-C-PNL・**秋月117640**・¥250 ×2（在庫あり。2026-08-12 再確認） | [open-gaps #23 案 A](open-gaps.md) |
| 同上 | スリム L 型 USB-C ケーブル（完成品） | **秋月には無い**（コネクタ単体・DIP化キットはあるが、L型の完成ケーブルは非取扱。2026-08-12 サイト内検索で再確認）→ Adafruit **6367**（23mm・$7.50）または **6372**（75mm・$5.95）×2 のまま。**プラグ厚みは未公表 → 届いたら実測し、6.0mm 以下であること**（直付け前提の条件） | 同上 |
| #27 で「薄いプラグ」路線を採る場合 | USB-C プラグコネクタ（自作・オス側） | **秋月に候補あり（未検証）**: 「USB Type-Cコネクター(00402-UCAM001-X)」**秋月118044**・¥130・表面実装・オス側（差込側）・USB2.0データ+電源対応。**シェル高さがページに未記載**——データシート PDF で高さ 6.0mm 以下か確認してから発注（未確認のうちは決定にしない）。次善: GCT **USB4155-03-C**（Digi-Key・$1.66・高さ 2.90mm）または Solder Party **UTC009-C12**（Tindie・シェル 2.40mm、いずれも高さ確認済み） | [open-gaps #27](open-gaps.md)（2026-08-11 調査／秋月候補は2026-08-12 追加） |

## 4. 買わない（間違えやすいもの）

| 何 | なぜ買わない |
|---|---|
| 横並び型の電池ボックス（58 × 32mm） | **#22 で却下済み。**コブに入らない。C4/C5 のブレッドボード検証には手持ちを使う |
| 丸型プッシュロックスイッチ（M8 級） | 背面の枠 10.6 × 15.6mm に入らない（#18 で実測済み） |
| Cherry / XDA / OEM / SA の**フルセット** | 下 3 段には背が高すぎて入らない（#21）。上 2 段は段単位でしか要らない |
| 実験用の別品番 | **本番の品番を決めてから買う**（CLAUDE.md。ショットキーと 595 で 2 回踏んだ） |
| 電源スイッチの測定専用サンプル SK-12D11VG3（¥25） | **2026-08-12 に廃止。**同じ枠に収まる SS12D01G4（¥30）がテストと本番を兼ねられるため、別品番でのテスト買いをやめた。加えて SK-12D11VG3 は 2026-08-12 時点で秋月在庫が「9月中旬入荷予定」で即納できない |

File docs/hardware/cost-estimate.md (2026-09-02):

# 基板の発注にいくらかかるか

**2026-08-08 時点。**単価と区分は `tools/jlcpcb_lookup.py` で実データを取った。
**発注の直前にもう一度走らせること。**在庫も価格も変わる。

```
.venv/bin/python3 tools/jlcpcb_lookup.py --parts
```

---

> ## ⚠️ **この見積もりは古い（2026-09-01 に点検）**
>
> **発注前に作り直すこと。**下の表は 2026-08-08 のもので、
> **そのあと部品も基板も変わっている。**特に層数は板代を丸ごと左右する。
>
> | 項目 | この文書の記載 | **いまの実態**（2026-09-01 実測） |
> |---|---|---|
> | **層数** | **4 層** | **2 層**（3 枚とも。`.kicad_pcb` の銅箔層を数えた） |
> | ダイオード | C81598 Basic $0.0117 | **C54110 BAT46W Extended $0.0309**（2.6 倍・**区分も Basic→Extended**） |
> | 595 | C5948 74HC595 Extended $0.1016 | **C52287685 74LVC595 Extended $0.1961**（1.9 倍） |
> | Extended の種類 | 3 種 × $3 = $9 | **4 種 × $3 = $12** |
> | 左の板 | 140.36 × 97.40mm | **138.36 × 97.40mm** |
> | 右の板 | 173.70 × 97.40mm | **171.70 × 97.40mm** |
> | 実装点数 | 667 点 | **134 点/セット**（左 57・右 73・子 4）＝ 5 セットで 670 点 |
>
> **層数が 4→2 なので板代は下がる方向**、**部品は上がる方向**（ダイオードが
> Basic から Extended になり、単価も 2.6 倍）。**打ち消し合うので
> 「だいたい同じ」とは言えない**——作り直して確かめること。
>
> 作り直し方は文書の先頭のとおり `tools/jlcpcb_lookup.py --parts` で
> 実データを取る。**推測で埋めないこと**（この案件では見積もりを 3 回外している）。

## 1. 確定している額（実データから計算）

部品の単価・区分・在庫は JLCPCB の API から取った。数量と半田付けの点数は
実基板（`pcb/*.kicad_pcb`）を数えた。**推測は入っていない。**

### 部品代（5 セット実装する場合）

| 種類 | 型番 | 区分 | 1 セット | 単価 | 5 セット |
|---|---|---|---|---|---|
| ホットスワップソケット | C49352235 | Extended | 61 | $0.0363 | $11.07 |
| FFC コネクタ | C88360 | Extended | 3 | $0.2635 | $3.95 |
| ダイオード | C81598 | Basic | 61 | $0.0117 | $3.57 |
| 74HC595 | C5948 | Extended | 3 | $0.1016 | $1.52 |
| パスコン 0.1uF | C49678 | Basic | 6 | $0.0253 | $0.76 |
| ショットキー | C8598 | Basic | 2 | $0.0296 | $0.30 |
| 分圧抵抗 1M | C17514 | Basic | 4 | $0.0093 | $0.19 |
| | | | **140 個** | | **$21.36** |

<!-- ⚠️ **バルク 100µF（C15008・2 個）は 2026-08-16 に削除した**（open-gaps #44）。
     実測で「守る相手が存在しない」と判明したため。−$1.46。
     **パスコン 0.1µF は残る**（役割が別）。
     ⚠️ この表の「74HC595 / C5948」は古い（74LVC595・C52287685 へ変更済み）。
     今回の担当外なので触っていないが、見積もりを使う前に直すこと。 -->

### 半田付けと段取り

| | 計算 | 額 |
|---|---|---|
| 半田付け | 667 点 × 5 × $0.0017 | **$5.67** |
| 段取り費 | Extended 3 種 × $3 | **$9.00** |

**段取り費が部品代に対して大きい**（5 セットで 4 割、推奨の 2 セットでは
部品代とほぼ同額 $9.00/$9.13）。単価ではなくここが効く。

---

## 2. 見積もりに留まる額（**発注ページで確認が要る**）

JLCPCB の見積もり API は見つけられなかった。以下は公開されている料率から
計算した**概算**で、確定値ではない。

### 基板そのもの

| 基板 | 寸法 | 層 | 面積 × 5 枚 |
|---|---|---|---|
| 左 | 140.36 × 97.40mm | 4 | 683.6 cm² |
| 右 | 173.70 × 97.40mm | 4 | 846.0 cm² |
| 子基板 | 21.00 × 32.00mm | 2 | 33.6 cm² |

4 層の板代は $70.6/m²（100 枚級の料率）。**5 枚だとこの倍近くになる**
（100×100mm 5 枚で $7 ＝ $140/m² 相当）。$140/m² で計算すると
左 $9.6 / 右 $11.8 / 子基板 $2（最低額）で、**合計 $23 前後**。

**±50% は見ておくこと。**100×100mm を超える板は割高な区分に入る。

### 実装の基本料とその他

| | 概算 | 備考 |
|---|---|---|
| 実装の基本料 | $8 × 設計数 | **基板 1 種ごとにかかる。**3 種なら $24 |
| ステンシル | $1.5〜 | 大きさによる |
| 送料（日本） | $10〜25 | 便による |

---

## 3. 合計の目安

| | 5 セット実装 | **2 セット実装（推奨）** |
|---|---|---|
| 部品代 | $21.36 | $8.54 |
| 半田付け | $5.67 | $2.27 |
| 段取り費 | $9.00 | $9.00 |
| 基板（5 枚ずつ） | ~$23 | ~$23 |
| 実装基本料 | ~$24 | ~$24 |
| ステンシル・送料 | ~$15 | ~$15 |
| **合計** | **~$100（¥15,000）** | **~$82（¥12,300）** |

**¥12,000〜15,000 程度**と見ておけばよい。±30%。

---

## 4. 減らせるところ（効果の大きい順）

### 4-1. 実装するのは 2 セットでよい（**約 ¥2,700**）

キーボードは左右 1 枚ずつ＋子基板 2 枚で成立する。**5 セット実装しても
使い道が無い。**2 セットなら 1 台分の予備が残る。板は 5 枚来る（最低数量）
ので、残りは未実装のまま予備になる。

### 4-2. 子基板を自分で半田付けする（**約 ¥1,200**）

子基板に載るのは**パスコン 1 個と FFC コネクタ 1 個だけ**。この 1 種類の
ために実装の基本料 $8 を払うことになる。**ただし FFC は 0.5mm ピッチ**なので、
手半田は容易ではない。腕と相談。

### 4-3. 74HC595 を SOIC-16 にする（**約 ¥450**・見送り中）

C5947（SOIC-16）は Basic で段取り費 $0。TSSOP-16（C5948）は
`preferredComponentFlag` も false で正真正銘の Extended。
SOIC-16 は 90 度回せば帯に入る（7.40mm・余裕 +0.92mm。実測済み）が、
幅が 6.4→10.4mm になって隣と 0.4mm 重なり、配線し直すと右基板に違反が
9 件出た。**DRC 0 の基板を崩す価値は無い**と判断して見送った。

---

## 5. 注意

**FFC コネクタの在庫が 2,868 個しかない。**必要 15 個なので足りるが、
この案件で最も薄い。`FH12-12S-0.5SH(54)` は製造中止（後継 FH52K）で、
在庫があるのは (55)。**無くなればフットプリントごと変えることになる。**

**この見積もりは 3 回外したあとのもの。**最初「FFC は ¥4,000」と書き、
次に「¥1,100」と書き、実際は ¥600 だった。数量 1 の価格を掛けていたため。
**発注ページの実額と必ず突き合わせること。**

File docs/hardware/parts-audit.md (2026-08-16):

# 部品の棚卸し — 効く条件と、何で確かめたか

**2026-08-08。**CLAUDE.md「決める前に通す手順」を、既に選んだ部品すべてに
遡って当てた。**選ぶときにこれをやっていなかったので、遅れて 2 回覆した。**

読み方:

- **外** … データシート・JLCPCB の API・実測など、外の事実で確かめた
- **未** … まだ確かめていない。**「たぶん大丈夫」は未に入れる**

---

## 1. シフトレジスタ SN74LVC595APWR（C52287685）

| 効く条件 | 確かめたか | 値 |
|---|---|---|
| 動作電圧の下限 | **外** | 1.1V。レール下限 1.83V の内側 |
| 動作電圧の上限 | **外** | 3.6V。レール最大 2.90V（USB 時 3.3V）の内側 |
| 1.8V での出力電流 | **外** | ±4mA。列の駆動に十分 |
| ピン配置 | **外** | 標準の 595。ZMK の `zmk,gpio-595` がそのまま使える |
| **1.8V での最高周波数** | **外** | **fclock 104MHz @ 1.8V（−40〜125℃ 保証）。**SPI 4MHz に対し余裕 26 倍 |
| **出力降下 VOH** | **外** | **IOH=−100µA で VCC−0.2V。**0.05V と推定していたのは 4 倍の誤りだった |

**74HC595 から替えた理由**は動作電圧の下限（2.0V）。レールが打ち止めで
1.83V まで下がるので規格外だった。→ `test_every_ic_runs_down_to_the_cutoff`

## 2. マトリクスのダイオード BAT46W（C54110）

| 効く条件 | 確かめたか | 値 |
|---|---|---|
| **走査電流での VF** | **外（保証・動作点）** | **≦0.25V @ IF=0.1mA** |
| **低逆電圧での IR** | **外（保証・動作点）** | **≦0.3µA @ VR=1.5V** |
| 必要なレール | 計算 | (0.30+0.05)/0.3 = 1.17V。**マイコンの 1.80V が律速** |
| ゴーストの余裕 | 計算 | 余裕 190mV に対し、行 9 個同時押しで 35mV（25℃） |
| 高温 | **外** | 60℃ では 5µA。**5 個以上の同時押しで余裕を割る**（机上の 25〜30℃ なら問題ない） |
| 接合容量 | 計算 | 20pF ×9 = 180pF。列切替後 2.31µs で VIL。SPI 転送 4.0µs 以上あるので間に合う |
| フットプリント | **外** | SOD-123。1N4148W と同じで基板は変わらない |
| 在庫 | **外** | 25,893 |

**在庫 5,000 超の SOD-123 ショットキー 29 件と、BAT47/48/49/54/85・
1SS 系・NSR・RB751・PMEG・MBR05xx を当たった結果、VF と IR を両方
動作点で保証しているのは BAT46W だけ。**

**バックアップは 1N4148W（C81598・Basic）。**戻すときは
`circuit.MATRIX_DIODE_VF` を 0.55 に戻す。打ち止めは 1.20V/本 に上がり、
マトリクスがマイコンより先に落ちる壊れ方に戻る。

## 3. ショットキー B5819W（C8598）

| 効く条件 | 確かめたか | 値 |
|---|---|---|
| **Vf（打ち止めを決める）** | **外（比較済み）** | SOD-123 の候補を全部並べた。[parts.py](../../tools/parts.py) |
| 10〜15mA での Vf | **未（規定が無い）** | 保守値 0.4V を置く。Task C4 で 1N5819 を使って実測 |
| 逆漏れ | **外** | 逆バイアスは 0.3V 程度。分圧の 1.6µA と同じ桁 |

## 4. ~~バルク 100µF CL31A107MQHNNNE（C15008）~~ → **削除した**（2026-08-16）

**この部品は基板に無い。**open-gaps #44 で削除した。
判断の全体は
[decisions/2026-08-16-remove-bulk-cap.md](decisions/2026-08-16-remove-bulk-cap.md)。

| 効く条件 | 確かめたか | 値 |
|---|---|---|
| **BLE の最大瞬間風速** | **外・実測**（DS1104Z・2026-08-16） | **10.22mA**（広告＋スキャンの重なり込み） |
| **µs 級の尖りの有無** | **外・実測**（1ns 分解能・60 万点を全数走査） | **0 個**。守る相手が実在しなかった |
| 容量ゼロでの降下 | 計算（実測値から） | 10.22mA × 9.2Ω = **94mV**。余裕 300mV の内側（安全率 3.2 倍） |

**送信中の降下は「電流 × 電池の内部抵抗」で決まり、容量では消せない。**
この点は前から正しかった。**間違っていたのは電流の値のほう**——
`BLE_TX_CURRENT = 15mA` は**出典の無い推定値**だった。

⚠️ **旧版のここには「余裕 `MCU_MARGIN` は 100mV」と書いてあったが誤り。**
比べる相手は `_RAIL_FLOOR` 2.00V − `MCU_V_MIN` 1.70V = **300mV**
（2026-08-11 に比較相手を直した経緯がある）。

`test_the_transmit_droop_needs_no_bulk_capacitor` が、
**容量ゼロでも降下が余裕に収まること**を見張る。
悪化したら落ちる＝バルクを戻す判断に戻る。

**⚠️ パスコン（下の 5）は残る。役割が別。**

## 5. パスコン 0.1µF CC0805KRX7R9BB104（C49678）

**実装先は主基板の `C_U1` / `C_U2` のみ**（左 1 個・右 2 個）。

> ⚠️ **子基板の `C_DB` は 2026-08-16 に削除した**（実装数 2 個減）。
> **部品そのものは健在**で、595 のパスコンとして主基板に残っている。
>
> C_DB を消したのは、**3V3 の負荷が 2 つとも子基板の外**にいて、
> どちらも自分の直近に別のパスコンを持っていたから:
> nRF52840 は XIAO 内蔵の 2.2µF ×5、595 は主基板の C_U1/C_U2（分流 58:1）。
> **「相手がいない」ではなく「取り分が誤差」。**
> [decisions/2026-08-16-cdb-has-no-local-load.md](decisions/2026-08-16-cdb-has-no-local-load.md)

| 効く条件 | 確かめたか | 値 |
|---|---|---|
| 誘電体 | **外** | X7R。温度で容量が動きにくい |
| 耐圧 | **外** | 50V。レールに対して桁違いの余裕 |
| DC バイアス | **外** | 50V 品に 3V なので実質なし |
| **負荷の直近にいるか** | **外＋自** | **C_U1/C_U2 は 595 の直近にいる。**この条件を満たさなかった C_DB は削除した（上） |

## 6. 分圧抵抗 1MΩ（C17514）

| 効く条件 | 確かめたか | 値 |
|---|---|---|
| 誤差 | **外** | 1%。残量表示の精度に効く |
| 消費電流 | **外** | 1.6µA。スリープに対して無視できる |
| **ADC から見た電源抵抗** | **外** | 500kΩ（1M∥1M）。nRF52840 の Table 80 は 40µs で 800kΩ まで。**ZMK の battery_voltage_divider が 40µs を設定している**ので足りている |
| ADC のフルスケール | **外** | ゲイン 1/6・内部基準 0.6V → 3.6V。新品での分圧出力 1.65V は内側 |

## 7. FFC コネクタ FH12-12S-0.5SH(55)（C88360）

| 効く条件 | 確かめたか | 値 |
|---|---|---|
| ピン数・ピッチ | **外** | 12P 0.5mm。実基板と照合済み（検査あり） |
| 電流 | **外** | 0.5A。流すのは µA〜mA |
| 在庫 | **外** | 2,868 個。**この案件で最も薄い** |
| 挿抜回数 | **未** | 組み立てで数回なので問題にならないはず |

## 8. ホットスワップソケット CPG151101S11-2（C49352235）

| 効く条件 | 確かめたか | 値 |
|---|---|---|
| **フットプリント適合** | **外（推奨ランド図）** | 6.35 / 2.54 / φ3.00 / 2.55×2.5mm。**KiCad の実物と一致** |
| **最低使用電圧** | **外** | **2V DC min（錫めっき）。いまのレール下限を決めているのはこれ** |
| 最低使用電流 | **外** | 10µA min。走査は約 100µA なので内側 |
| 接触抵抗 | **外** | 100mΩ max |
| 寿命 | **外** | 5,000 回の挿抜 |
| 在庫 | **外** | 37,697（-16 は 283,792・同価格・**色違いだけ**） |

**金めっき品は JLCPCB に無い。**CPG151101S11 の全変種（-1/-2/-4/-16）を
確認した。-16 は筐体が紫、-2 は白。**接点はどちらも錫、2V min も同じ。**

**この 2V がレールの下限（2.00V）＝ 打ち止め 1.20V/本 を決めている。**
マイコン（1.80V）やマトリクス（1.67V）より厳しい。**電池の末尾 1 割ほどを
捨てることになるが、保証範囲の外で使うよりよい。**

---

## 9. 電源スライドスイッチ SS12D01G4-G（秋月 112723）

**2026-08-12 に利用者が決定。**基板には載らない（壁のポケットへ落とし込み、
リード線で `SW_PWR_1` / `SW_PWR_2` へ繋ぐ。decisions/2026-08-08-power-switch.md）。

| 効く条件 | 確かめたか | 値 |
|---|---|---|
| **ツマミの突出量** | **外** | **4.0mm**（図面の `L 4` と商品ページ「操作部長さ 4mm」が一致）。壁 2.4 − 窪み 1.0 = 1.4mm を貫いて外へ 2.6mm 出る。要求は 1.0mm 以上 |
| 本体の幅（左右） | **外** | 3.9mm。置ける隙間は 10.56mm |
| 本体の高さ（上下） | **外** | 8.8mm。受けの溝の高さを決める |
| 本体の奥行 | **外** | 3.5mm。**奥のリブの位置＝押し込み側の抜け止めがここで決まる** |
| 端子の長さ・ピッチ | **外** | 5.0mm / 2.5mm・3 本。リブの縦スリットを通す |
| ストローク | **外** | 2.0mm。スロット長 5.0mm に収まる |
| 定格 | **外** | 50VDC 0.3A。電池 2 本・待機 0.66mA に対し桁で余裕 |
| 接触抵抗 | **外** | 30mΩ MAX。候補中で最良（SS-12D00G3 は 100mΩ） |
| 操作力 | **外** | 200±80gf |
| 入手性 | **外** | 秋月 ¥30・在庫 15,062 個 |
| **入れられるか** | **外**（実形状） | 受けを本体の下半分（`SW_HOLD_H`）にして解決。**上へ 5.6mm → 手前へ**。`test_every_part_can_be_put_in_from_outside` |
| 経年の硫化膜 | **未** | 銀メッキ。スライドのセルフクリーニング頼み（#18）。**接触抵抗が低いぶん初期マージンはあるが、劣化を防ぐわけではない** |
| 実寸 | **未** | 図面と商品ページの値。**届いたらノギスで `SW_PWR_*` を入れ替える** |

⚠️ **前提だった C&K OS102011MA1QN1（右アングル）とは種類が違う**（こちらは
基板に垂直なストレート）。**それでも設計は変わらない**——スイッチを基板に
載せないので、基板とパネルの位置関係という問題が発生しない。

---

## 10. ピンソケット FHU-1x40SG-Y（秋月 110302）

**2026-08-12 に利用者が決定。プロトタイプ期のみの部品**（脱プロトタイプで
直付けへ戻し、ケースを刷り直す。#27）。1×40 を折って 1×7 を 4 本取る。

| 効く条件 | 確かめたか | 値 |
|---|---|---|
| **座高（スタック高さ）** | **外** | **8.5mm**。秋月の寸法ガイドが「寸法C … ハウジング高さ（**スタック高さ**）」と定義しており、**求めている量そのもの** |
| 手持ちヘッダとの噛み合い | **外** | XIAO のヘッダはピン 5.5mm・樹脂 2.0mm。5.5 < 8.5 なので**底突きしない**。`DB_XIAO_LIFT` = 8.5 + 2.0 = 10.5mm（コードの値と一致・変更不要） |
| リード長（基板側） | **外** | 3.0mm。子基板を貫く |
| ピッチ | **外** | 2.54mm。XIAO と一致 |
| 定格電流 | **外** | 3A。用途に対し過剰 |
| 分割できるか | **外** | 「分割」ロングピンソケット。1×7 を切り出せる |
| 実寸 | **未** | 商品ページの値。**挿した状態で「子基板の上面 → XIAO の基板下面」を直接測る**（分解しての足し算にしない） |

**アンテナへの影響は承知のうえ**（子基板が 10.5mm 持ち上がり、アンテナと
地板の隙間が 7.22 → 0.72mm。利用者が 2026-08-12 に許容と判断。#27 / #23）。

---

## 11. LED インジケーター（**実機にあるのに、ここに無かった**）

⚠️ **2026-08-16 に追加。**この部品表は 2026-08-08 に「全項目を閉じた」と
していたが、**実機にある部品が 1 つ抜けていた。**

**実機 HHKB Professional HYBRID には前面に LED インジケーターがある**
（PFU 取扱説明書 P3PC-6641-05 に状態表がある）。にもかかわらず、
この部品表にも、ケース CAD にも、BOM にも LED・導光・電流制限抵抗が
1 つも無い。**検査対象に入っていない部品は、検査していないのと同じ。**

### いま使っているもの

| | |
|---|---|
| 部品 | **XIAO 基板上の RGB LED**（Seeed の "3-in-one LED"） |
| ピン | 赤 P0.26 / 緑 P0.30 / 青 P0.06（共通アノード＝アクティブ Low） |
| 入手 | **追加購入は不要。**XIAO に載っている |
| 基板への影響 | **無し。**GPIO も消費しない（モジュール上で配線済み） |
| 確かめ方 | 上流の devicetree を実ファイルで確認済み（`xiao_ble_zmk.dts` は Zephyr の dts を `#include` するだけで `leds` も `aliases` も削っていない） |

### 効く条件（**満たしていないものがある**）

| 条件 | 状況 |
|---|---|
| ZMK から制御できる | ✅ 上流の dts を確認 |
| 実機と同じ色が出せる | ✅ **RGB 1 個なので赤+緑で橙になる**（3 個離れていたら橙に見えない） |
| **外から見える** | ❌ **ケースの中にある。**上ケースの窓か導光が要る（open-gaps #43） |
| 実機と同じ位置にある | ❌ **未計測。**実機の LED の物理位置を測っていない |
| 点灯電流が電池寿命に響かない | ⚠️ **未実測。**接続中は消灯なので定常状態では効かないが、未接続で放置すると乗る |

**下 3 つが埋まるまで、実機再現としては未完成。**
外付け LED にする場合は D4 / D9 が空いている（**基板に影響する**）。
→ [decisions/2026-08-16-status-led.md](decisions/2026-08-16-status-led.md)

---

## まだ確かめていないもの

**無し。**（2026-08-08 に全項目を閉じた）

⚠️ **ただし「全項目」の母数が間違っていた**（2026-08-16 に判明）。
**実機にある LED がこの表に入っていなかった**ので、
「全部閉じた」は**数えた範囲での話**でしかなかった（上の 11 を参照）。

閉じ方の内訳:

| 項目 | どう閉じたか |
|---|---|
| マトリクスのダイオードの VF | **部品を替えた**（BAT46W。保証値で詰まる） |
| バルクの実効容量 | **計算で無関係と判明**（容量を倍にしても 3mV） |
| 595 の 1.8V での fmax | **データシート**（104MHz。余裕 26 倍） |
| 595 の出力降下 | **データシート**（VCC−0.2V。推定の 4 倍だった） |
| ソケットのフットプリント | **推奨ランド図と KiCad が一致** |
| ソケットの最低使用電圧 | **制約に追加**（2V。いまのレール下限を決めている） |
| ADC の取得時間 | **ZMK が 40µs を設定済み**。対応不要 |

**残っているのは「実測でしか埋まらないもの」だけ**（`SCHOTTKY_VF`・
`BLE_TX_CURRENT`・`BATT_ESR_END`・`SW_PWR_*`・`DB_SOCKET_SEAT`。
前 3 つは Task C4 で測り、後 2 つは届いたらノギスで測る。
[provisional-values.md](provisional-values.md)）。

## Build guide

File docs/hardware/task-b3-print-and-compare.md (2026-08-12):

# Task B3 — 3Dプリントして実機と比べる

**部品の到着を待たずにできる。** そして**私にはできない検証**でもある。

---

## 1. なぜやるか

ケースの寸法は、実機を分解せず公開情報だけから導いた。数値としては
[dimensions.md](dimensions.md) に根拠を残してあるが、**手で触った感触は
数値に出ない**。

とくに次の 3 つは、実物を並べないと判断できない。

| 確認したいこと | 数値では分からない理由 |
|---|---|
| **手前端の高さ 17.5mm** | 手首が当たる高さ。1mm 違うと体感が変わる |
| **打鍵面の傾斜 7.3°** | 実機と並べて横から見れば一目で分かる |
| **各段のキートップ高さ** | 指を置いたときの段差の感じ |

寸法の出どころは実測 17mm と別レビュー約 18mm の中間を採るなど、
**幅のある推定が混ざっている**。実物で詰められるならその方がよい。

---

## 2. 何を印刷するか

すべて `build/` にある。OrcaSlicer での確認は済んでいる（18/18 スライス成功）。

### まず刷るもの（合計 40 分ほど）

| ファイル | 時間 | 何を見るか |
|---|---|---|
| `front_edge_8deg.stl` | 12 分 | **手前端の断面**。3 つ刷って実機と比べる |
| `front_edge_12deg.stl` | 12 分 | 同上 |
| `front_edge_16deg.stl` | 12 分 | 同上 |
| `height_gauge.stl` | 26 分 | **各段のキートップ高さ**を測る治具 |

**手前端の断面が最優先。** 実機の手前は単純な直線ではなく、指摘を受けて
造形を直した経緯がある。3 つの角度を並べて実機に当てれば、どれが近いか
（あるいはどれも違うか）がすぐ分かる。

### 次に刷るもの（3 時間半ほど）

| ファイル | 時間 | 何を見るか |
|---|---|---|
| `case_left.stl` | 1h39m | 全体の姿・傾斜・手前端の高さ |
| `rear_lid_left.stl` | 8 分 | **コブの奥面の蓋**（2026-08-12 に底面から移した）。下へ 3mm 差し込んで留まるか／親指の溝で押し上げられるか |
| `tilt_foot_0deg_left.stl` | 4 分 | 脚が穴に入るか |
| `tilt_foot_3deg_left.stl` | 6 分 | 3° の傾きが出るか |
| `tilt_foot_6deg_left.stl` | 8 分 | 6° の傾きが出るか |

**ケースは寸法が変わった直後なので、刷るなら今の版で。**
プレートの奥行を実機どおり 108mm にした変更が入っている。

---

## 3. 実機と比べる

### 3-1. 手前端（最優先）

実機の手前端に、印刷した 3 つの断面を順に当てる。

| | 実測 |
|---|---|
| どれが最も近いか（8° / 12° / 16°） | |
| 高さは合っているか（設計 17.5mm） | |
| 断面の形は合っているか（直線か、丸みがあるか） | |

**どれも違う場合は、その旨と「どう違うか」を教えてほしい。**
「もっと丸い」「もっと立っている」程度で構わない。

### 3-2. 高さゲージ

`height_gauge.stl` を実機のキーの横に立て、各段のキートップと比べる。

| 段 | 設計値 | 実機と比べて |
|---|---|---|
| 最下段（Space の段） | 26.7mm | |
| 4 段目（Z X C） | 29.2mm | |
| ホーム段（A S D） | 31.6mm | |
| 3 段目（Q W E） | 35.6mm | |
| 数字段 | 40.0mm | |

**ホーム段 31.6mm が最重要。** 指が最も長くいる高さ。

### 3-3. ケース全体

| | 実測 |
|---|---|
| 横から見た傾斜が実機と揃うか | |
| 手前端の高さが同じか | |
| 奥行 108mm が実機の本体と一致するか | |
| チルト脚を挿して 3° / 6° になるか | |

---

## 4. 印刷の設定

`tools/slice_check.py` が使うのと同じ条件で確認してある。

- プリンタ: Creality K1 Max
- フィラメント: PLA
- 層厚: 0.2mm
- **サポート不要**（全部品でサポートが要る面 0%）

ケースは底面を下にして置く。ベッドとの接地面積は確保済み。

---

## 5. 結果の扱い

**寸法が違っていたら直す。** 実機に合わせるのが基本方針なので、
設計値の方を動かす。

ただし [tools/test_invariants.py](../../tools/test_invariants.py) が
これらの値を固定しているので、**根拠（実測値）を
[dimensions.md](dimensions.md) に書いてからテストを更新する**。
根拠なしに緩めない。

---

## 6. これは私にはできない

CAD の生成物はメッシュの健全性もスライスの可否も機械で検証しているが、
**実機と並べて「近いか」を判断することはできない**。ここだけは
実物を持っている人にしか閉じられない。

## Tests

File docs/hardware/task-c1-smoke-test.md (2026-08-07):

# Task C1 — 疎通確認

**所要時間の目安: 半田付け 20 分 ＋ 配線と測定 10 分**

---

## 1. なぜやるか

**これは設計の検証ではない。「足元が固いか」を確かめるだけの作業。**

ここまで作ってきたファームウェアは、**一度も実機で動かしていない**。
GitHub Actions のビルドが通っているだけで、実際の XIAO に書き込んで
キーが入ることは誰も確かめていない。

C1 が確定させるのは次の 6 点。

| # | 確認対象 | これが壊れていると |
|---|---|---|
| 1 | XIAO の個体が生きている | 何をやっても動かない |
| 2 | USB ケーブルがデータ通信対応 | 書き込みすらできない |
| 3 | RESET 2 回 → UF2 書き込みの手順 | ファームを更新できない |
| 4 | **GitHub Actions のビルドが実機で動く** | CI が緑でも意味がない |
| 5 | **`xiao_ble//zmk` というボード指定が正しい** | ZMK が起動しない |
| 6 | ZMK が USB キーボードとして認識される | 文字が出ない |

**4 と 5 が本命。** ボード名は `seeeduino_xiao_ble` → `xiao_ble//zmk` と
一度つまずいた箇所で、正しさは実機でしか確かめられない。

### C1 が確認しないこと

マトリクス方式・ダイオードの向き・ゴースト・キー配列。
**キーボードの設計に関わることは何ひとつ検証しない。** それは
[Task C2](task-c2-keyscan.md) の仕事。

### 分けておく価値

C2 で「押しても何も出ない」となったとき、原因の候補が減る。

| C1 を飛ばした場合 | C1 が通っている場合 |
|---|---|
| XIAO の故障／USB ケーブル／書き込み失敗／ボード指定ミス／ダイオードの向き／スイッチの足／ジャンパの位置 | **ダイオードの向き／スイッチの足／ジャンパの位置** |

**7 個から 3 個に減り、残る 3 個はすべて目で見て直せる。**

C2 の配線は C1 の上に**組み替えではなく追加**でできる（XIAO の位置はそのまま、
スイッチを 2 個足してジャンパを差し替える）。無駄になる作業はほとんどない。

---

## 2. 用意するもの

| 品目 | 数 | 備考 |
|---|---|---|
| XIAO nRF52840 | 1 | |
| ピンヘッダ 7 ピン | **2 本** | 基板の**両側**に必要（後述） |
| タクトスイッチ | 2 | |
| ブレッドボード 30 列 × 10 行 | 1 | |
| ジャンパ線 | 5 本 | |
| USB-C ケーブル | 1 | **データ通信対応のもの。充電専用では書き込めない** |

**ダイオードは使わない。** ZMK が XIAO の内部プルアップを有効にし、
スイッチで GND へ落とすだけの構成のため（`GPIO_ACTIVE_LOW | GPIO_PULL_UP`）。

---

## 3. ピンヘッダの半田付け

XIAO はヘッダ未実装で出荷される。ブレッドボードに挿すには**両側 7 ピンずつ、
計 14 ピン**を立てる。C1 で使う GND は右列、D0・D1 は左列にあるので、
片側だけでは足りない。

XIAO nRF52840 のピン配置。左列が D0〜D6、右列が 5V GND 3V3 D10 D9 D8 D7

> 上の図は**本番の**割り当てを示したもの。C1 で使うのは **D0・D1・GND** の 3 本だけ。

### ピンの数え方

**ピン番号のシルクは基板の裏面にしかない。** ブレッドボードに挿すと下を向いて
見えなくなるので、位置で覚えること。USB コネクタを**奥**に向けて上から見たとき:

- **左列**（上から）**D0 D1** D2 D3 D4 D5 D6
- **右列**（上から）5V **GND** 3V3 D10 D9 D8 D7

---

## 4. 配線

30 列 10 行のブレッドボード上の C1 の配置。XIAO を 1〜7 列に、タクトスイッチを 10 列と 14 列の下半分に挿し、18 列を GND バスにする

### 挿す場所の一覧

| # | 部品 | 挿す場所 |
|---|---|---|
| 1 | XIAO nRF52840 | 1〜7 列。上側の足が **h 行**、下側の足が **d 行**。USB は左へはみ出す |
| 2 | タクトスイッチ **1** | **10 列と 12 列**（足は **b 行と e 行**） |
| 3 | タクトスイッチ **2** | **14 列と 16 列** |
| 4 | ジャンパ | **a 行**の 1 列 → 10 列（**D0** へ） |
| 5 | ジャンパ | **a 行**の 2 列 → 14 列（**D1** へ） |
| 6 | ジャンパ | **a 行**の 12 列 → 18 列（**GND バス**へ） |
| 7 | ジャンパ | 16 列の **a 行** → 18 列の **b 行**（GND バスへ） |
| 8 | ジャンパ | **2 列の j 行** → 18 列の **c 行**（**GND を上半分から引く**） |

**スイッチの足が入る列（10・12・14・16）で使える穴は a 行だけ。**
c 行と d 行はスイッチ本体の下に隠れる。

**溝をまたぐのは 8 番のジャンパ 1 本だけ。** GND だけが XIAO の上側にあるため。

### 間違えやすいところ

**2 列は「下半分が D1、上半分が GND」で別の配線。** 中央の溝で分かれている。

| | 1 列 | 2 列 |
|---|---|---|
| 上半分（**h 行**） | 5V | **GND** |
| 下半分（**d 行**） | **D0** | **D1** |

**XIAO のピン間隔は 0.6 インチ（15.24mm）で、基板の外形 17.8mm とは違う。**
挿さるのは **d 行と h 行**であって、c 行ではない。

### タクトスイッチをどちら向きに挿すか

**必ずテスターで確かめること。品種によって向きが逆になる。**

4 本足のタクトスイッチは、同じ辺から出た 2 本が内部で常時つながっており、
押して初めてつながるのは**反対の辺との間**。どちらの間隔が広いかは品種で違う。

| 品種 | 常時導通する 2 本の間隔 | 押して導通する 2 本の間隔 |
|---|---|---|
| 6mm 角の定番品 | 4.5mm（狭いほう） | 6.5mm（**広いほう**） |
| 別品種の例（このプロジェクトの手持ち品） | 7.62mm ＝ 3 マス（**広いほう**） | 5.08mm ＝ 2 マス（狭いほう） |

**「広いほうがスイッチ側」と決めつけない。** 当初この文書にはそう書いていたが、
6mm 角の本体寸法から導いた話であって、他の品種には通用しなかった。

**10 秒でできる確認。** テスターを導通モードにして、足の組み合わせを当たる。

- **押したときだけ鳴る 2 本** → これがスイッチとして使う 2 本
- **押さなくても鳴る 2 本** → 内部でつながっている。この 2 本の間には何も入れない

**この 2 本が何マス離れているかを測ってから配置を決める。** 配置図の穴番号は
その寸法に合わせて作ってある。

配置は電気的に検算してある（各スイッチが D0／D1 と GND を正しく結ぶこと、
D0 と D1 が短絡しないこと、GND が 5V や 3V3 と短絡しないこと）。

---

## 5. ファームウェアの書き込み

1. [GitHub Actions の最新の成功ビルド](https://github.com/ms0216/hhkb-split/actions)を開く
2. 下部の Artifacts から `firmware` をダウンロードして展開
3. 中の **`proto_direct-xiao_ble__zmk-zmk.uf2`** を使う
4. XIAO を USB でつなぐ
5. 基板上の **RESET ボタンを素早く 2 回**押す
6. `XIAO-SENSE` という名前のドライブがマウントされる
   （通常版でもこの名前になる。Sense を買ったわけではない）
7. そこへ `.uf2` をコピーする。自動で再起動して書き込み完了

このシールドは `CONFIG_ZMK_BLE=n` にしてある。BLE を有効にしたままだと、
キー入力が BLE 側へ送られていて「USB に何も出ない」という切り分けの難しい
状態が起こりうるため。**USB 接続のまま、普通のキーボードとして文字が入る。**

書き込み後は OS がキーボードとして認識する。設定ウィザードが出たら閉じてよい。

---

## 6. 判定

テキストエディタを開いて、2 つのスイッチを押す。

| 押すスイッチ | 期待 | 実測 |
|---|---|---|
| 10 列（D0） | **a** | **a**（2026-08-07 確認） |
| 14 列（D1） | **b** | **b**（2026-08-07 確認） |

**✅ C1 は 2026-08-07 に合格した。** これで次が確定した。

- XIAO の個体・USB ケーブル・書き込み手順が健全
- **GitHub Actions のビルドが実機で動く**
- **`xiao_ble//zmk` というボード指定が正しい**
- ZMK が USB キーボードとして認識される（`kUSBVendorString = "ZMK Project"`）

そのまま [Task C2](task-c2-keyscan.md) へ進む。

---

## 7. うまくいかないとき

> **2026-08-07 に実際にはまった内容と復旧手順は
> [xiao-flash-recovery.md](xiao-flash-recovery.md) に記録した。**
> 中古・転用品の XIAO を使う場合は先に読むこと。

### 正常だが紛らわしい macOS の挙動（エラーではない）

| 現象 | 意味 |
|---|---|
| **エラーコード -36** | **正常。** 書き込み完了で XIAO が再起動しドライブが消えたため |
| `cp: ... Device not configured` | 同上。ターミナルの `cp` でも出る |
| **「ディスクの不正な取り出し」通知** | 同上。むしろ**書き込みが受理された証拠** |
| キーボード設定アシスタントが開く | **正常。** 治具はキーが 2 個なので応えられない。閉じてよい |

### 「アクセサリの接続を許可しますか？」が出る

**「許可」を押す。** macOS Ventura 以降、初めて挿す USB 機器は許可するまで
ブロックされる。許可しないと機器は見えているのに動かない。

`ioreg -p IOUSB -w0` で `!registered, !matched` と出ていたらこれ。

### ドライブがマウントされない

1. RESET のダブルクリックが速すぎるか遅すぎる。間隔を変えて何度か試す
2. **USB ケーブルが充電専用**。これが最も多い原因なので、別のケーブルで試す
3. USB ハブ経由なら、PC に直挿しで試す

### ドライブは出るが文字が入らない

1. **スイッチの足**を疑う。テスターの導通モードで「押したときだけ鳴る」
   組み合わせか確認する
2. **GND の配線**を疑う。GND は**上半分の 2 列**（下半分の 2 列は D1）
3. ジャンパが隣の穴に挿さっていないか目視する

### 押していないのに文字が出続ける

スイッチの足を**同じ辺から 2 本**選んでいる。内部でつながっているので
常時オンになる。溝をまたいで挿し直す。

### `a` と `b` が入れ替わって出る

配線は正しく、**D0 と D1 のジャンパが逆**なだけ。実害はないが、
C2 に進む前に直しておくと混乱しない。

### 書き込みは通ったのに、USB に何も現れない

**フラッシュを読み返して確かめる。** ブートローダは `CURRENT.UF2` として
現在のフラッシュ内容を読み出せるので、本当に書けているかを確認できる。

```bash
cp /Volumes/XIAO-SENSE/CURRENT.UF2 ./current.uf2
```

手順は [xiao-flash-recovery.md](xiao-flash-recovery.md) 参照。
中古・転用品の XIAO では **SoftDevice が消されていて**アプリに制御が
渡らないことがある（実際にそうだった）。

### 片方だけ出ない

出ない方のスイッチとジャンパ 2 本（D0/D1 側と GND 側）だけを見ればよい。
出ている方と同じ配線になっているか比べる。

---

## 8. 次にやること

C1 が通れば、**XIAO・USB ケーブル・書き込み手順・ZMK のビルドがすべて健全**だと
確定する。以降の失敗は配線かファーム設定に絞り込める。

そのまま [Task C2（キースキャンの実測検証）](task-c2-keyscan.md) へ。
**XIAO の位置はそのままでよい。** スイッチを 2 個足し、ダイオード 4 本を加えて、
ジャンパを差し替える。

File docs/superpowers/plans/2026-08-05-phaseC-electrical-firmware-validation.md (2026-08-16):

# フェーズ1: 電気・ファームウェア検証 実装計画

> [!WARNING]
> **Task 2 と Task 3 はこの計画のままでは実施しない（2026-08-07）。**
>
> キースキャンをチャープレックスから「行×列マトリクス ＋ 74HC595」へ変更した。
> nRF52840 の 3.3V ではダイオードの電圧降下だけで 2 キー同時押しのゴーストを
> 消せないことが計算で判明したため。判断根拠は
> [decisions/2026-08-07-keyscan.md](../../hardware/decisions/2026-08-07-keyscan.md)、
> 差し替え後の手順は [task-c2-keyscan.md](../../hardware/task-c2-keyscan.md)。
>
> 以下の記述はチャープレックス前提のまま残してある（経緯の記録として）。

> **For agentic workers:** REQUIRED SUB-SKILL: Use superpowers:subagent-driven-development (recommended) or superpowers:executing-plans to implement this plan task-by-task. Steps use checkbox (`- [ ]`) syntax for tracking.

**Goal:** PCB を発注する前に、ブレッドボード上で「チャープレックス配線・BLE 分割・乾電池給電・HHKB キーマップ」の4つが成立することを実測で確定させる。

**Architecture:** ZMK の設定リポジトリを本プロジェクト内の `firmware/` に置き、GitHub Actions でファームウェアをビルドする。XIAO nRF52840 を 2 個使い、ブレッドボードに少数のキーだけを配線して、方式の可否を1つずつ潰す。ローカルに Zephyr SDK を入れる必要はない。

**Tech Stack:** ZMK Firmware / Zephyr devicetree / GitHub Actions / Seeed XIAO nRF52840 (`seeeduino_xiao_ble`)

## Global Constraints

- 対象仕様書: [docs/superpowers/specs/2026-08-04-hhkb-split-keyboard-design.md](../specs/2026-08-04-hhkb-split-keyboard-design.md)
- ZMK ボード名は `seeeduino_xiao_ble` を使う。他のボードに置き換えない（技適の要件）。
- 左右間の無線接続は必須要件。有線分割（TRRS）にフォールバックしない。
- HHKB に存在しない機能（RGB / OLED / エンコーダ / タップダンス / ホールドタップ / コンボ / マクロ）は最終ファームに入れない。検証用の一時ファームでは使ってよい。
  - ⚠️ **訂正（2026-08-16）: 状態表示の LED はこの除外に当たらない。**
    **実機 HHKB には前面に LED インジケーターがある**（P3PC-6641-05）。
    キーの下を光らせる RGB とは別物で、**最終ファームに入れる**。
    → [decisions/2026-08-16-status-led.md](../../hardware/decisions/2026-08-16-status-led.md)
- キーマップのレイヤー番号は以下で固定する。以降の全タスクがこの番号を前提にする。

  | 番号 | 名前 | 役割 |
  |---|---|---|
  | 0 | `BASE_MAC` | Mac モードのベース配列（起動時の既定） |
  | 1 | `BASE_WIN` | Windows モードのベース配列 |
  | 2 | `FN` | HHKB の Fn 面 |
  | 3 | `SYS` | BT 切替・OS モード切替 |

- `Fn + Ctrl` の再現方法: `FN` レイヤー上の Ctrl の位置に `&mo 3` を置く。これにより「Fn を押しながら Ctrl」で `SYS` レイヤーに入り、Ctrl 単独では通常の Ctrl のまま残る。ZMK の conditional-layers は「レイヤー同士」の組み合わせしか扱えないため、この方式を採る。
- GPIO 割り当ては以下で固定する。XIAO nRF52840 で ADC が使えるのは D0〜D5 のみ（P0.02/P0.03/P0.28/P0.29/P0.04/P0.05）であり、電池電圧測定に 1 本必要なため、チャープレックスは D2 以降を使う。

  | | チャープレックス | 電池電圧 ADC | 空き |
  |---|---|---|---|
  | 左（6ピン） | D3, D4, D5, D6, D7, D8 | D0 | D1, D2, D9, D10 |
  | 右（7ピン） | D2, D3, D4, D5, D6, D7, D8 | D0 | D1, D9, D10 |

---

## 事前に用意するもの

このフェーズは基板を作らずに進めるため、以下だけで開始できる。

| 品目 | 数量 | 用途 | 概算 |
|---|---|---|---|
| Seeed XIAO nRF52840（Sense でない通常版） | 2 | 左右の MCU | ¥3,600 |
| ブレッドボード | 2 | 左右 | ¥1,000 |
| ピンヘッダ（XIAO 用、2.54mm 7ピン） | 4 | XIAO をブレッドボードに挿すため。**要はんだ付け** | ¥200 |
| ジャンパワイヤ | 1 セット | 配線 | ¥800 |
| タクトスイッチ（2.54mm ピッチ） | 12 | 検証用キー | ¥300 |
| 1N4148（スルーホール） | 12 | チャープレックス用ダイオード | ¥200 |
| 抵抗 1MΩ | 4 | 電池電圧の分圧 | ¥100 |
| 単3電池ボックス（2本用・リード線付き） | 2 | 乾電池給電 | ¥400 |
| ショットキーダイオード 1N5817 | 2 | 電池側の逆流防止 | ¥200 |
| スライドスイッチ | 2 | 電源 | ¥200 |
| **デジタルテスター（µA レンジのあるもの）** | 1 | **逆流・消費電流の実測に必須** | ¥3,000〜 |
| USB-C ケーブル（データ通信対応） | 2 | 書き込み・給電 | 手持ち可 |

**注意**: XIAO nRF52840 にはピンヘッダが付属していないため、最初にはんだ付けが必要。ここが本フェーズで唯一のはんだ作業。

**GitHub アカウントとリモートリポジトリが必要**。ファームウェアは GitHub Actions でビルドするため、本プロジェクトを GitHub にプッシュできる状態にしておく。

---

## File Structure

```
.github/workflows/build.yml          ZMK 公式の再利用ワークフローを呼ぶだけ
firmware/
  build.yaml                         ビルド対象（ボード × シールド）の一覧
  config/
    west.yml                         ZMK 本体の取得先
    boards/shields/proto_direct/     Task 1: 疎通確認用（direct GPIO・2キー）
      Kconfig.shield
      proto_direct.overlay
      proto_direct.keymap
      proto_direct.conf
    boards/shields/proto_cplex/      Task 2: チャープレックス検証用（単体）
      Kconfig.shield
      proto_cplex.overlay
      proto_cplex.keymap
      proto_cplex.conf
    boards/shields/hhkb_split/       Task 3 以降: 本番シールド（左右）
      Kconfig.shield
      hhkb_split.dtsi                左右共通（チャープレックス・電池・トランスフォーム）
      hhkb_split_left.overlay
      hhkb_split_right.overlay
      hhkb_split_left.conf
      hhkb_split_right.conf
      hhkb_split.keymap              左右共通のキーマップ
docs/
  hardware/charlieplex-mapping.md    Task 2 の実測結果（ピン組合せ → 位置の対応表）
  hardware/power-measurements.md     Task 4・5 の実測結果
  hardware/wireless-latency.md       Task 3 の体感評価記録
```

検証用シールド（`proto_direct` / `proto_cplex`）は本番シールドと分けて残す。後で不具合が出たときに最小構成へ戻れるため、消さずに保持する。

---

## Task 1: ZMK ビルド環境と最小疎通

XIAO 1個・キー2個で「ファームを作って書き込むとキー入力になる」ところまでを通す。以降のタスクはすべてこの往復の上に乗る。

**Files:**
- Create: `.github/workflows/build.yml`
- Create: `firmware/build.yaml`
- Create: `firmware/config/west.yml`
- Create: `firmware/config/boards/shields/proto_direct/Kconfig.shield`
- Create: `firmware/config/boards/shields/proto_direct/proto_direct.overlay`
- Create: `firmware/config/boards/shields/proto_direct/proto_direct.keymap`
- Create: `firmware/config/boards/shields/proto_direct/proto_direct.conf`

**Interfaces:**
- Produces: ビルド基盤（`.github/workflows/build.yml` と `firmware/build.yaml`）。以降の全タスクは `firmware/build.yaml` に `shield:` を追加するだけでビルド対象を増やせる。
- Produces: シールドディレクトリの置き場所 `firmware/config/boards/shields/<name>/`。

- [ ] **Step 1: XIAO にピンヘッダをはんだ付けする**

XIAO nRF52840 2 個の両側 7 ピンに、2.54mm ピンヘッダをはんだ付けする。ブレッドボードにピンヘッダを挿し、その上に XIAO を載せて固定してからはんだ付けすると、ピンが傾かない。

確認: ブレッドボードに挿してぐらつかず、隣接ピン同士がブリッジしていないこと（テスターの導通モードで隣接ピン間が導通しないことを見る）。

- [ ] **Step 2: GitHub リモートリポジトリを作成して接続する**

```bash
cd "/Users/m/Library/CloudStorage/OneDrive-個人用/workspace/2608042258_HHKB_devided"
gh repo create hhkb-split --private --source=. --remote=origin
git push -u origin master
```

`gh` が未インストールなら `brew install gh && gh auth login` を先に実行する。

期待: `git remote -v` で origin が表示され、GitHub 上にリポジトリが見えること。

- [ ] **Step 3: ビルドワークフローを作成する**

`.github/workflows/build.yml`:

```yaml
name: Build ZMK firmware

on:
  push:
  pull_request:
  workflow_dispatch:

jobs:
  build:
    uses: zmkfirmware/zmk/.github/workflows/build-user-config.yml@main
    with:
      build_matrix_path: firmware/build.yaml
      config_path: firmware/config
```

ZMK 公式の再利用ワークフローを呼ぶ。`config_path` と `build_matrix_path` を指定しているので、ZMK 標準のリポジトリ構成（ルート直下に `config/`）でなくても動く。

- [ ] **Step 4: ビルド対象と ZMK 本体の取得先を定義する**

`firmware/build.yaml`:

```yaml
include:
  - board: seeeduino_xiao_ble
    shield: proto_direct
```

`firmware/config/west.yml`:

```yaml
manifest:
  remotes:
    - name: zmkfirmware
      url-base: https://github.com/zmkfirmware
  projects:
    - name: zmk
      remote: zmkfirmware
      revision: main
      import: app/west.yml
  self:
    path: config
```

- [ ] **Step 5: 疎通確認用シールドを定義する**

`firmware/config/boards/shields/proto_direct/Kconfig.shield`:

```
config SHIELD_PROTO_DIRECT
	def_bool $(shields_list_contains,proto_direct)
```

`firmware/config/boards/shields/proto_direct/proto_direct.overlay`:

```dts
/ {
	chosen {
		zmk,kscan = &kscan0;
	};

	kscan0: kscan_0 {
		compatible = "zmk,kscan-gpio-direct";
		wakeup-source;
		input-gpios
			= <&xiao_d 0 (GPIO_ACTIVE_LOW | GPIO_PULL_UP)>
			, <&xiao_d 1 (GPIO_ACTIVE_LOW | GPIO_PULL_UP)>
			;
	};
};
```

`&xiao_d` は Zephyr の XIAO ボード定義にあるピンコネクタのラベルで、`<&xiao_d 0>` が基板シルクの D0 に対応する。P0.02 のような生のポート番号を書かなくてよい。

`firmware/config/boards/shields/proto_direct/proto_direct.keymap`:

```dts
#include <behaviors.dtsi>
#include <dt-bindings/zmk/keys.h>

/ {
	keymap {
		compatible = "zmk,keymap";

		default_layer {
			bindings = <&kp A &kp B>;
		};
	};
};
```

`firmware/config/boards/shields/proto_direct/proto_direct.conf`:

```
CONFIG_ZMK_KEYBOARD_NAME="proto direct"
```

- [ ] **Step 6: コミットしてビルドを走らせる**

```bash
git add .github firmware
git commit -m "feat: ZMK ビルド環境と疎通確認用シールドを追加"
git push
```

- [ ] **Step 7: ビルドの成功を確認してファームを取得する**

```bash
gh run watch
gh run download --name firmware --dir /tmp/zmk-firmware
ls /tmp/zmk-firmware
```

期待: `proto_direct-seeeduino_xiao_ble-zmk.uf2` が存在すること。

ビルドが失敗した場合は `gh run view --log-failed` でログを読む。よくある失敗は `west.yml` のインデント誤りと、シールド名とディレクトリ名の不一致（`Kconfig.shield` の `shields_list_contains` の引数はディレクトリ名と完全一致していなければならない）。

- [ ] **Step 8: 配線して書き込む**

ブレッドボード配線:
- タクトスイッチ 1: 片側を XIAO の `D0`、もう片側を `GND`
- タクトスイッチ 2: 片側を XIAO の `D1`、もう片側を `GND`

書き込み:
1. XIAO を USB-C で Mac に接続する
2. XIAO 上のリセットボタンを**素早く 2 回**押す
3. Finder に `XIAO-SENSE` という名前のドライブが現れる
4. `proto_direct-seeeduino_xiao_ble-zmk.uf2` をそのドライブにドラッグ&ドロップする
5. ドライブが自動的にアンマウントされ、XIAO が再起動する

- [ ] **Step 9: 動作を確認する**

テキストエディタを開き、タクトスイッチを押す。

期待: スイッチ 1 で `a`、スイッチ 2 で `b` が入力される。

入力されない場合の切り分け順序:
1. Bluetooth ではなく USB で入力されているか（USB 接続時は USB が優先される）
2. macOS の「キーボード設定アシスタント」が開いていないか（開いていたら一度閉じる）
3. スイッチの導通（テスターで、押したときに導通すること）
4. `GND` が XIAO の GND ピンか（XIAO は両側に GND がある）

- [ ] **Step 10: コミット**

```bash
git add -A
git commit -m "feat: XIAO 単体での ZMK 疎通確認が完了"
git push
```

---

## Task 2: チャープレックス配線の検証

**このフェーズで最も重要なタスク。** 7 ピンで 42 個のキーを読めることを実測し、「どのピンの組み合わせが (row, col) のどことして報告されるか」の対応表を作る。この表がないと PCB の配線を決められない。

**Files:**
- Create: `firmware/config/boards/shields/proto_cplex/Kconfig.shield`
- Create: `firmware/config/boards/shields/proto_cplex/proto_cplex.overlay`
- Create: `firmware/config/boards/shields/proto_cplex/proto_cplex.keymap`
- Create: `firmware/config/boards/shields/proto_cplex/proto_cplex.conf`
- Create: `docs/hardware/charlieplex-mapping.md`
- Modify: `firmware/build.yaml`

**Interfaces:**
- Consumes: Task 1 のビルド基盤。
- Produces: `docs/hardware/charlieplex-mapping.md` — ピン組み合わせと `(row, col)` の対応表。Task 6 のキーマップと、フェーズ2 の PCB 配線がこれを参照する。
- Produces: チャープレックスの devicetree 記述パターン（`zmk,kscan-gpio-charlieplex` ノードと 7×7 の `zmk,matrix-transform`）。Task 3 の本番シールドがこれを流用する。

- [ ] **Step 1: 検証用の 8 キーを配線する**

D2〜D8 の 7 本を使う。チャープレックスでは、1 つのキーは「タクトスイッチ + ダイオードの直列」で 2 本のピンの間を繋ぐ。ダイオードの向きが位置を決める。

配線の規約（PCB でもこの規約を踏襲する）:

```
  ピンX ──[タクトスイッチ]──[1N4148 アノード→カソード]── ピンY
```

つまり **ダイオードのアノード側を X、カソード側（帯のある側）を Y** に向ける。X と Y を入れ替えたものは別のキーになる。

検証用に、対応表の当たりをつけやすい 8 通りを配線する:

| 検証キー | X（アノード側） | Y（カソード側） |
|---|---|---|
| K1 | D2 | D3 |
| K2 | D3 | D2 |
| K3 | D2 | D4 |
| K4 | D2 | D8 |
| K5 | D8 | D2 |
| K6 | D5 | D6 |
| K7 | D7 | D8 |
| K8 | D8 | D7 |

K1/K2、K4/K5、K7/K8 はピンの組み合わせが同じで向きだけが逆。これが別々のキーとして認識されれば、チャープレックスが正しく機能している証拠になる。

- [ ] **Step 2: チャープレックス用シールドを定義する**

`firmware/config/boards/shields/proto_cplex/Kconfig.shield`:

```
config SHIELD_PROTO_CPLEX
	def_bool $(shields_list_contains,proto_cplex)
```

`firmware/config/boards/shields/proto_cplex/proto_cplex.overlay`:

```dts
#include <dt-bindings/zmk/matrix_transform.h>

/ {
	chosen {
		zmk,kscan = &kscan0;
		zmk,matrix-transform = &default_transform;
	};

	kscan0: kscan_0 {
		compatible = "zmk,kscan-gpio-charlieplex";
		wakeup-source;
		gpios
			= <&xiao_d 2 GPIO_ACTIVE_HIGH>
			, <&xiao_d 3 GPIO_ACTIVE_HIGH>
			, <&xiao_d 4 GPIO_ACTIVE_HIGH>
			, <&xiao_d 5 GPIO_ACTIVE_HIGH>
			, <&xiao_d 6 GPIO_ACTIVE_HIGH>
			, <&xiao_d 7 GPIO_ACTIVE_HIGH>
			, <&xiao_d 8 GPIO_ACTIVE_HIGH>
			;
	};

	default_transform: keymap_transform_0 {
		compatible = "zmk,matrix-transform";
		columns = <7>;
		rows = <7>;
		map = <
			RC(0,0) RC(0,1) RC(0,2) RC(0,3) RC(0,4) RC(0,5) RC(0,6)
			RC(1,0) RC(1,1) RC(1,2) RC(1,3) RC(1,4) RC(1,5) RC(1,6)
			RC(2,0) RC(2,1) RC(2,2) RC(2,3) RC(2,4) RC(2,5) RC(2,6)
			RC(3,0) RC(3,1) RC(3,2) RC(3,3) RC(3,4) RC(3,5) RC(3,6)
			RC(4,0) RC(4,1) RC(4,2) RC(4,3) RC(4,4) RC(4,5) RC(4,6)
			RC(5,0) RC(5,1) RC(5,2) RC(5,3) RC(5,4) RC(5,5) RC(5,6)
			RC(6,0) RC(6,1) RC(6,2) RC(6,3) RC(6,4) RC(6,5) RC(6,6)
		>;
	};
};
```

対角（`RC(0,0)` など）は物理的に存在しないが、トランスフォームには含めておく。存在しない位置は押されないので害はなく、番号がずれないぶん対応表を読み解きやすい。位置番号は左上から順に 0〜48 になる。

`firmware/config/boards/shields/proto_cplex/proto_cplex.conf`:

```
CONFIG_ZMK_KEYBOARD_NAME="proto cplex"
CONFIG_ZMK_USB_LOGGING=y
```

`CONFIG_ZMK_USB_LOGGING=y` にすると、USB シリアル経由でキー押下のログが出る。これが対応表を作る手段になる。

- [ ] **Step 3: キーマップを定義する**

`firmware/config/boards/shields/proto_cplex/proto_cplex.keymap`:

49 個の位置すべてに異なるキーコードを割り当て、押したときに何が入力されるかで位置を特定できるようにする。

```dts
#include <behaviors.dtsi>
#include <dt-bindings/zmk/keys.h>

/ {
	keymap {
		compatible = "zmk,keymap";

		default_layer {
			bindings = <
				&kp N0 &kp N1 &kp N2 &kp N3 &kp N4 &kp N5 &kp N6
				&kp A  &kp B  &kp C  &kp D  &kp E  &kp F  &kp G
				&kp H  &kp I  &kp J  &kp K  &kp L  &kp M  &kp N
				&kp O  &kp P  &kp Q  &kp R  &kp S  &kp T  &kp U
				&kp V  &kp W  &kp X  &kp Y  &kp Z  &kp F1 &kp F2
				&kp F3 &kp F4 &kp F5 &kp F6 &kp F7 &kp F8 &kp F9
				&kp F10 &kp F11 &kp F12 &kp MINUS &kp EQUAL &kp LBKT &kp RBKT
			>;
		};
	};
};
```

各行が `row`、各列が `col` に対応する。例えば `RC(2,4)` の位置を押すと `l` が入力される。

- [ ] **Step 4: ビルド対象に追加してビルドする**

`firmware/build.yaml` を次の内容に更新する:

```yaml
include:
  - board: seeeduino_xiao_ble
    shield: proto_direct
  - board: seeeduino_xiao_ble
    shield: proto_cplex
```

```bash
git add -A
git commit -m "feat: チャープレックス検証用シールドを追加"
git push
gh run watch
gh run download --name firmware --dir /tmp/zmk-firmware
```

期待: `proto_cplex-seeeduino_xiao_ble-zmk.uf2` が生成されること。

ビルドが `zmk,kscan-gpio-charlieplex` を認識せずに失敗する場合は、`west.yml` の `revision` が古い ZMK を指している可能性がある。`revision: main` になっていることを確認する。

- [ ] **Step 5: 書き込んで 8 キーを実測する**

Task 1 Step 8 と同じ手順で書き込む。テキストエディタを開き、K1〜K8 を 1 つずつ押して、入力された文字を記録する。

期待する結果の性質:
- 8 キーすべてが**それぞれ異なる文字**を入力する
- K1 と K2（D2↔D3 の向き違い）が異なる文字になる
- K4 と K5、K7 と K8 も同様に異なる

**このタスクの合否判定**: 上記 3 点がすべて満たされれば、チャープレックス方式は成立する。1 つでも満たされない（同じ文字が出る、何も出ない、複数文字が出る）場合は Step 8 の分岐へ進む。

- [ ] **Step 6: 対応表を書き起こす**

`docs/hardware/charlieplex-mapping.md` を作成する。実測した文字から `(row, col)` を逆引きし、次の形式で記録する。

```markdown
# チャープレックス配線 対応表

XIAO nRF52840 / ZMK `zmk,kscan-gpio-charlieplex`
`gpios` の並び順: D2, D3, D4, D5, D6, D7, D8（インデックス 0〜6）

配線規約: ピンX ──[スイッチ]──[1N4148 アノード→カソード]── ピンY

## 実測結果（2026-08-XX）

| 検証キー | X（アノード） | Y（カソード） | 入力された文字 | 対応する位置 |
|---|---|---|---|---|
| K1 | D2 | D3 | （実測値） | RC(?,?) |
| K2 | D3 | D2 | （実測値） | RC(?,?) |
| K3 | D2 | D4 | （実測値） | RC(?,?) |
| K4 | D2 | D8 | （実測値） | RC(?,?) |
| K5 | D8 | D2 | （実測値） | RC(?,?) |
| K6 | D5 | D6 | （実測値） | RC(?,?) |
| K7 | D7 | D8 | （実測値） | RC(?,?) |
| K8 | D8 | D7 | （実測値） | RC(?,?) |

## 導かれた規則

row = （実測から判明した規則を記述）
col = （実測から判明した規則を記述）

## 42 位置の全対応表

| row \ col | 0 (D2) | 1 (D3) | 2 (D4) | 3 (D5) | 4 (D6) | 5 (D7) | 6 (D8) |
|---|---|---|---|---|---|---|---|
| 0 (D2) | — | | | | | | |
| 1 (D3) | | — | | | | | |
| 2 (D4) | | | — | | | | |
| 3 (D5) | | | | — | | | |
| 4 (D6) | | | | | — | | |
| 5 (D7) | | | | | | — | |
| 6 (D8) | | | | | | | — |
```

8 点の実測から規則を導いたら、残る 34 位置は規則から埋める。**規則を導いたあと、必ず未検証の位置を 2 つ選んで配線し直し、予測どおりの文字が出ることを確かめる**（規則の外挿が正しいことの確認）。

- [ ] **Step 7: コミット**

```bash
git add -A
git commit -m "feat: チャープレックス配線を実測し対応表を作成"
git push
```

- [ ] **Step 8（Step 5 が失敗した場合のみ）: duplex マトリクスへの切替を判断する**

チャープレックスが動かない場合、仕様書の「既知のリスク」に従い duplex マトリクス（ダイオード 2 個/キー、`zmk,kscan-gpio-matrix` を 2 系統）へ切り替える。この場合:

- 右 34 キー: 4 行 × 5 列の duplex（実質 40 キー）で 9 ピン。空き 2 ピン。
- 左 27 キー: 3 行 × 5 列の duplex（実質 30 キー）で 8 ピン。空き 3 ピン。

切替を決めた場合はこの計画を中断し、仕様書 §4 のキースキャン方式を更新したうえで計画を書き直す。**独断で進めず、必ず判断を仰ぐこと。**

---

## Task 3: BLE 分割の検証

XIAO 2 個を左右に見立てて ZMK の分割構成を組み、左右同時押しが正しく扱われることと、無線の遅延が実用範囲であることを確認する。

**Files:**
- Create: `firmware/config/boards/shields/hhkb_split/Kconfig.shield`
- Create: `firmware/config/boards/shields/hhkb_split/hhkb_split.dtsi`
- Create: `firmware/config/boards/shields/hhkb_split/hhkb_split_left.overlay`
- Create: `firmware/config/boards/shields/hhkb_split/hhkb_split_right.overlay`
- Create: `firmware/config/boards/shields/hhkb_split/hhkb_split_left.conf`
- Create: `firmware/config/boards/shields/hhkb_split/hhkb_split_right.conf`
- Create: `firmware/config/boards/shields/hhkb_split/hhkb_split.keymap`
- Create: `docs/hardware/wireless-latency.md`
- Modify: `firmware/build.yaml`

**Interfaces:**
- Consumes: Task 2 の `docs/hardware/charlieplex-mapping.md`（トランスフォームの `map` を書くために必要）。
- Produces: 本番シールド `hhkb_split_left` / `hhkb_split_right`。Task 5〜7 はこのシールドを編集していく。
- Produces: キーマップの物理配置順（左 27 キー → 右 34 キーの計 61 個を、上段左から順に並べる）。Task 6 がこの順序でキーマップを書く。

- [ ] **Step 1: 本番シールドの骨格を作る**

`firmware/config/boards/shields/hhkb_split/Kconfig.shield`:

```
config SHIELD_HHKB_SPLIT_LEFT
	def_bool $(shields_list_contains,hhkb_split_left)

config SHIELD_HHKB_SPLIT_RIGHT
	def_bool $(shields_list_contains,hhkb_split_right)
```

`firmware/config/boards/shields/hhkb_split/hhkb_split.dtsi`（左右共通の土台）:

```dts
#include <dt-bindings/zmk/matrix_transform.h>

/ {
	chosen {
		zmk,kscan = &kscan0;
	};
};
```

- [ ] **Step 2: 左シールドを定義する**

`firmware/config/boards/shields/hhkb_split/hhkb_split_left.overlay`:

左は 6 ピン（D3〜D8）で 27 キー。検証段階ではキーを 4 個だけ配線するので、トランスフォームには 6×6 の全位置を並べておき、実際に配線した位置だけを押す。

```dts
#include "hhkb_split.dtsi"

/ {
	chosen {
		zmk,matrix-transform = &left_transform;
	};

	kscan0: kscan_0 {
		compatible = "zmk,kscan-gpio-charlieplex";
		wakeup-source;
		gpios
			= <&xiao_d 3 GPIO_ACTIVE_HIGH>
			, <&xiao_d 4 GPIO_ACTIVE_HIGH>
			, <&xiao_d 5 GPIO_ACTIVE_HIGH>
			, <&xiao_d 6 GPIO_ACTIVE_HIGH>
			, <&xiao_d 7 GPIO_ACTIVE_HIGH>
			, <&xiao_d 8 GPIO_ACTIVE_HIGH>
			;
	};

	left_transform: keymap_transform_l {
		compatible = "zmk,matrix-transform";
		columns = <6>;
		rows = <6>;
		map = <
			RC(0,1) RC(0,2) RC(0,3) RC(0,4) RC(0,5) RC(1,0)
			RC(1,2) RC(1,3) RC(1,4) RC(1,5) RC(2,0) RC(2,1)
			RC(2,3) RC(2,4) RC(2,5) RC(3,0) RC(3,1) RC(3,2)
			RC(3,4) RC(3,5) RC(4,0) RC(4,1) RC(4,2) RC(4,3)
			RC(4,5) RC(5,0) RC(5,1)
		>;
	};
};
```

対角（`RC(n,n)`）は物理的に存在しないため除外し、残る 30 位置のうち先頭 27 個を使う。**この `map` の並び順が、キーマップの左 27 キーの並び順（HHKB 配列の左半分を上段左から順に読んだ順序）に一対一で対応する。**

`firmware/config/boards/shields/hhkb_split/hhkb_split_left.conf`:

```
CONFIG_ZMK_KEYBOARD_NAME="HHKB Split"
CONFIG_ZMK_SPLIT=y
CONFIG_ZMK_SPLIT_ROLE_CENTRAL=y
```

- [ ] **Step 3: 右シールドを定義する**

`firmware/config/boards/shields/hhkb_split/hhkb_split_right.overlay`:

右は 7 ピン（D2〜D8）で 34 キー。

```dts
#include "hhkb_split.dtsi"

/ {
	chosen {
		zmk,matrix-transform = &right_transform;
	};

	kscan0: kscan_0 {
		compatible = "zmk,kscan-gpio-charlieplex";
		wakeup-source;
		gpios
			= <&xiao_d 2 GPIO_ACTIVE_HIGH>
			, <&xiao_d 3 GPIO_ACTIVE_HIGH>
			, <&xiao_d 4 GPIO_ACTIVE_HIGH>
			, <&xiao_d 5 GPIO_ACTIVE_HIGH>
			, <&xiao_d 6 GPIO_ACTIVE_HIGH>
			, <&xiao_d 7 GPIO_ACTIVE_HIGH>
			, <&xiao_d 8 GPIO_ACTIVE_HIGH>
			;
	};

	right_transform: keymap_transform_r {
		compatible = "zmk,matrix-transform";
		columns = <7>;
		rows = <7>;
		map = <
			RC(0,1) RC(0,2) RC(0,3) RC(0,4) RC(0,5) RC(0,6) RC(1,0)
			RC(1,2) RC(1,3) RC(1,4) RC(1,5) RC(1,6) RC(2,0) RC(2,1)
			RC(2,3) RC(2,4) RC(2,5) RC(2,6) RC(3,0) RC(3,1) RC(3,2)
			RC(3,4) RC(3,5) RC(3,6) RC(4,0) RC(4,1) RC(4,2) RC(4,3)
			RC(4,5) RC(4,6) RC(5,0) RC(5,1) RC(5,2) RC(5,3)
		>;
	};
};
```

`firmware/config/boards/shields/hhkb_split/hhkb_split_right.conf`:

```
CONFIG_ZMK_KEYBOARD_NAME="HHKB Split"
CONFIG_ZMK_SPLIT=y
```

右には `CONFIG_ZMK_SPLIT_ROLE_CENTRAL` を書かない。これにより右が周辺側（peripheral）になる。

- [ ] **Step 4: 検証用の暫定キーマップを書く**

`firmware/config/boards/shields/hhkb_split/hhkb_split.keymap`:

61 キー分の bindings が必要。この段階では Task 6 の本番キーマップではなく、同時押しの検証に必要なキーだけを意味のある割り当てにし、残りは順番に並べておく。**左 27 個 → 右 34 個の順**で並べる。

```dts
#include <behaviors.dtsi>
#include <dt-bindings/zmk/keys.h>

/ {
	keymap {
		compatible = "zmk,keymap";

		default_layer {
			bindings = <
			// 左 27 キー（先頭を LSHIFT と LCTRL にして同時押しの検証に使う）
			&kp LSHIFT &kp LCTRL &kp N3 &kp N4 &kp N5 &kp N6
			&kp Q &kp W &kp E &kp R &kp T &kp Y
			&kp U &kp I &kp O &kp P &kp N1 &kp N2
			&kp N7 &kp N8 &kp N9 &kp N0 &kp MINUS &kp EQUAL
			&kp LBKT &kp RBKT &kp BSLH
			// 右 34 キー（先頭を A にして左 Shift との同時押しを見る）
			&kp A &kp B &kp C &kp D &kp E &kp F &kp G
			&kp H &kp I &kp J &kp K &kp L &kp M &kp N
			&kp O &kp P &kp Q &kp R &kp S &kp T &kp U
			&kp V &kp W &kp X &kp Y &kp Z &kp COMMA &kp DOT
			&kp SLASH &kp SEMI &kp SQT &kp GRAVE &kp TAB
			>;
		};
	};
};
```

- [ ] **Step 5: ビルドしてブレッドボードに配線する**

`firmware/build.yaml` を次の内容に更新する:

```yaml
include:
  - board: seeeduino_xiao_ble
    shield: proto_direct
  - board: seeeduino_xiao_ble
    shield: proto_cplex
  - board: seeeduino_xiao_ble
    shield: hhkb_split_left
  - board: seeeduino_xiao_ble
    shield: hhkb_split_right
```

配線（Task 2 の対応表を見て、狙った位置になるようダイオードの向きを決める）:
- 左ブレッドボード: `map` の 1 番目（LSHIFT）と 2 番目（LCTRL）の位置に 2 キー
- 右ブレッドボード: `map` の 1 番目（A）と 2 番目（B）の位置に 2 キー

```bash
git add -A
git commit -m "feat: 分割シールドを追加"
git push
gh run watch
gh run download --name firmware --dir /tmp/zmk-firmware
```

期待: `hhkb_split_left-seeeduino_xiao_ble-zmk.uf2` と `hhkb_split_right-seeeduino_xiao_ble-zmk.uf2` の 2 つが生成されること。

- [ ] **Step 6: 左右に書き込んでペアリングする**

1. 左の XIAO に `hhkb_split_left-...uf2` を書き込む
2. 右の XIAO に `hhkb_split_right-...uf2` を書き込む
3. 両方に USB で給電した状態にする（この時点ではまだ乾電池を使わない）
4. 左右が自動的に接続されるのを待つ（数秒〜十数秒）
5. Mac の Bluetooth 設定を開き、`HHKB Split` を探してペアリングする

左右が繋がらない場合は、両方のリセットボタンを 1 回ずつ押して再起動する。それでも繋がらない場合は、両方をブートローダーモードにして `settings_reset` ファーム（ZMK 公式が配布）を書き込み、設定を消してからやり直す。

- [ ] **Step 7: 左右同時押しを検証する**

テキストエディタで以下を実行し、結果を記録する。

| 検証内容 | 操作 | 期待する結果 |
|---|---|---|
| 左修飾 + 右キー | 左 LSHIFT を押しながら 右 A | `A`（大文字） |
| 左修飾を離す前後 | 左 LSHIFT を押す → 右 A を押す → 右 A を離す → 左 LSHIFT を離す | `A` 1 文字のみ |
| 左修飾 2 つ + 右キー | 左 LSHIFT と 左 LCTRL を押しながら 右 B | Shift+Ctrl+B として認識される（エディタのショートカットで確認） |
| 高速な左右交互打鍵 | 左 LCTRL の位置と右 A を交互に 20 回以上高速で叩く | 取りこぼし・順序の入れ替わりが起きない |
| 右キー連打 | 右 A を 30 回連打 | 30 文字入力される |

- [ ] **Step 8: 遅延の体感を記録する**

`docs/hardware/wireless-latency.md` を作成し、Step 7 の結果と体感を記録する。

```markdown
# BLE 分割の遅延評価

測定日: 2026-08-XX
構成: XIAO nRF52840 ×2、左 central / 右 peripheral、ZMK revision main
ホスト: macOS（BLE 接続）

## 同時押しの検証結果

（Step 7 の表をそのまま貼り、各行に実測結果と OK/NG を追記する）

## 体感

- 左半分（central）の打鍵: （記述）
- 右半分（peripheral）の打鍵: （記述）
- 左右の差を感じるか: （記述）

## 判定

（実用に足るか。詰める必要があるか）
```

**判定が「詰める必要がある」の場合のみ** Step 9 に進む。問題なければ Step 9 を飛ばす。

- [ ] **Step 9（必要な場合のみ）: BLE 接続間隔を詰める**

`hhkb_split_right.conf` に以下を追加し、周辺側の接続間隔を最短（7.5ms）に寄せる。

```
CONFIG_BT_PERIPHERAL_PREF_MIN_INT=6
CONFIG_BT_PERIPHERAL_PREF_MAX_INT=6
CONFIG_BT_PERIPHERAL_PREF_LATENCY=0
CONFIG_BT_PERIPHERAL_PREF_TIMEOUT=400
```

値の単位は 1.25ms 刻みなので `6` = 7.5ms。再ビルド・再書き込みして Step 7 を再実行し、`docs/hardware/wireless-latency.md` に前後の比較を追記する。

**有線分割（TRRS）への切替は行わない**（Global Constraints 参照）。ここで解決できない場合は判断を仰ぐ。

- [ ] **Step 10: コミット**

```bash
git add -A
git commit -m "feat: BLE 分割の動作と左右同時押しを検証"
git push
```

---

## Task 4: 乾電池給電と逆流の実測

XIAO の 3V3 ピンに単3電池 2 本から給電し、USB を挿したときに電池側へ電流が逆流しないことを実測で確かめる。**仕様書で「検証必須項目」としている箇所。**

**Files:**
- Create: `docs/hardware/power-measurements.md`

**Interfaces:**
- Consumes: Task 3 で書き込み済みの左右ファーム（そのまま使う）。
- Produces: `docs/hardware/power-measurements.md` — 消費電流と逆流電流の実測値。フェーズ2 の電源回路設計がこの数値を根拠にする。

- [ ] **Step 1: 電池給電の回路を組む**

左の XIAO について、次の配線をブレッドボード上に作る。**まだ USB は挿さない。**

```
単3電池ボックス(+) ── スライドスイッチ ── 1N5817 (アノード) 
                                              │
                                        (カソード) ── XIAO の 3V3 ピン

単3電池ボックス(−) ── XIAO の GND ピン
```

1N5817 はショットキーダイオードで、順方向電圧降下が約 0.3V。アルカリ新品 3.2V なら XIAO には約 2.9V が供給される（nRF52840 の動作範囲 1.7〜3.6V 内）。

**向きを間違えないこと。** 帯のある側（カソード）が XIAO 側。

- [ ] **Step 2: 電池だけで動作することを確認する**

スライドスイッチを ON にする。

期待: 左の XIAO が起動し、Mac と BLE で接続され、配線済みのキーが入力できること。

動かない場合の切り分け:
1. 電池電圧をテスターで測る（2 本で 2.8V 以上あるか）
2. ダイオードの向き（3V3 ピン側で 2.9V 前後が測れるか）
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

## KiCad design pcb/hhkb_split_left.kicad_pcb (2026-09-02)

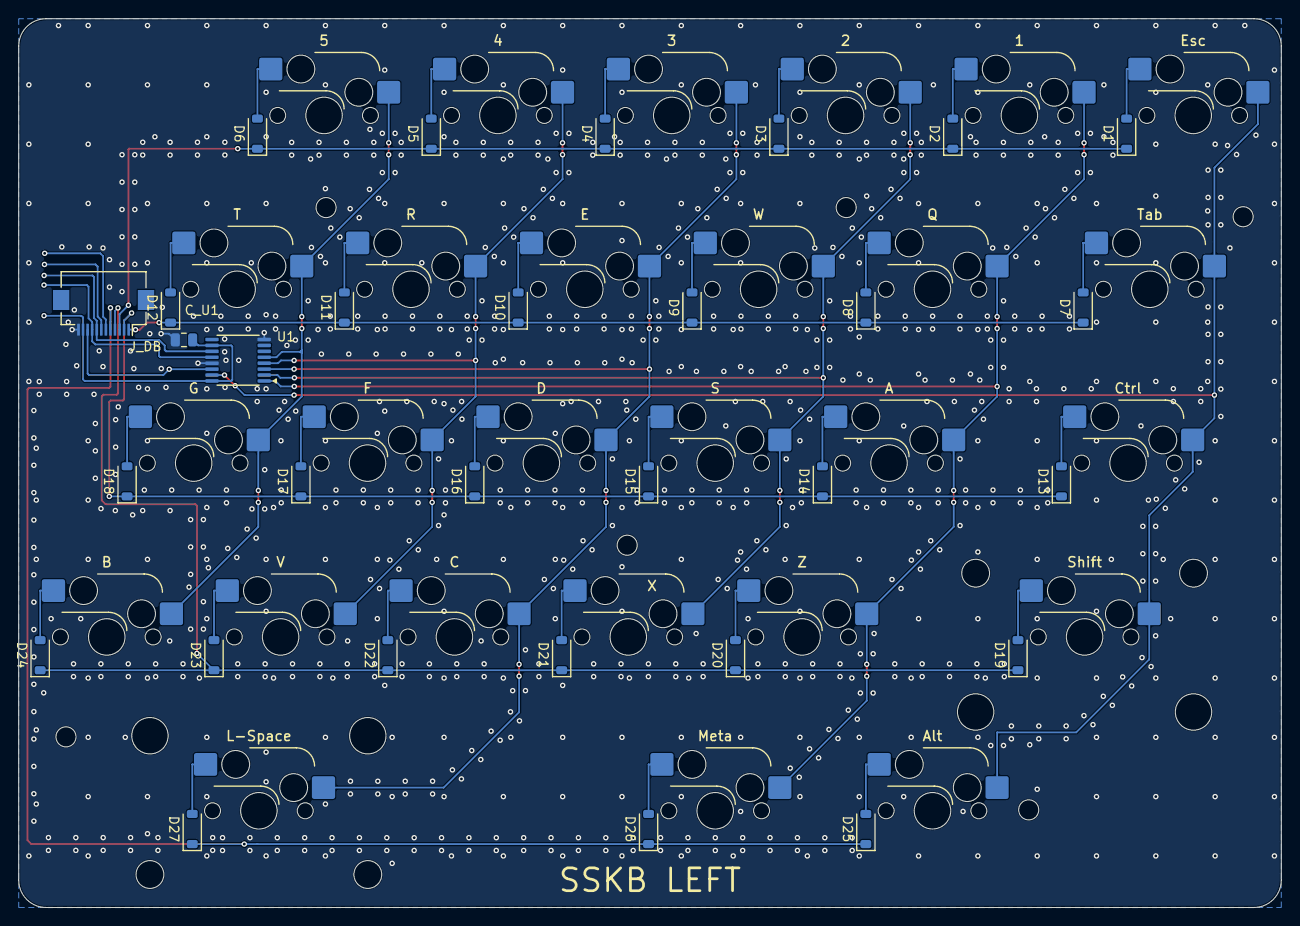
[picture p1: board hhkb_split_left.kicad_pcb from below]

Board: 2 copper layers, 138.4 x 97.4 mm, 65 parts (30 on the bottom side), 43 nets.

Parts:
C_U1: 100nF; C_0805_2012Metric
D1, D2, D3, D4, D5, D6, D7, D8, D9, D10, D11, D12, D13, D14, D15, D16, D17, D18, D19, D20, D21, D22, D23, D24, D25, D26, D27: BAT46W; D_SOD-123
H0, H1, H2, H3, H4, H5: MountingHole_2.2mm_M2
J_DB: FH12-12S-0.5SH(55); Hirose_FH12-12S-0.5SH_1x12-1MP_P0.50mm_Horizontal
ST19, ST27: Stabilizer_Cherry_MX_2.00u
SW1, SW2, SW3, SW4, SW5, SW6, SW8, SW9, SW10, SW11, SW12, SW14, SW15, SW16, SW17, SW18, SW20, SW21, SW22, SW23, SW24, SW25: CPG151101S11-2; SW_Hotswap_Kailh_MX_1.00u
SW7, SW26: CPG151101S11-2; SW_Hotswap_Kailh_MX_1.50u
SW13: CPG151101S11-2; SW_Hotswap_Kailh_MX_1.75u
SW19: CPG151101S11-2; SW_Hotswap_Kailh_MX_2.25u
SW27: CPG151101S11-2; SW_Hotswap_Kailh_MX_2.75u
U1: 74LVC595; TSSOP-16_4.4x5mm_P0.65mm

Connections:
COL0: SW1.1, SW7.1, SW13.1, SW19.1, SW25.1, U1.15
COL1: SW2.1, SW8.1, SW14.1, SW20.1, SW26.1, U1.1
COL2: SW3.1, SW9.1, SW15.1, SW21.1, U1.2
COL3: SW4.1, SW10.1, SW16.1, SW22.1, SW27.1, U1.3
COL4: SW5.1, SW11.1, SW17.1, SW23.1, U1.4
COL5: SW6.1, SW12.1, SW18.1, SW24.1, U1.5
CS: J_DB.9, U1.12
GND: C_U1.2, J_DB.12, U1.8, U1.13
ROW_A: D25.1, D26.1, D27.1, J_DB.5
ROW_B: D19.1, D20.1, D21.1, D22.1, D23.1, D24.1, J_DB.4
ROW_C: D1.1, D2.1, D3.1, D4.1, D5.1, D6.1, J_DB.3
ROW_D: D13.1, D14.1, D15.1, D16.1, D17.1, D18.1, J_DB.2
ROW_E: D7.1, D8.1, D9.1, D10.1, D11.1, D12.1, J_DB.1
SPI_MOSI: J_DB.10, U1.14
SPI_SCK: J_DB.8, U1.11
SW1_D: D1.2, SW1.2
SW2_D: D2.2, SW2.2
SW3_D: D3.2, SW3.2
SW4_D: D4.2, SW4.2
SW5_D: D5.2, SW5.2
SW6_D: D6.2, SW6.2
SW7_D: D7.2, SW7.2
SW8_D: D8.2, SW8.2
SW9_D: D9.2, SW9.2
SW10_D: D10.2, SW10.2
SW11_D: D11.2, SW11.2
SW12_D: D12.2, SW12.2
SW13_D: D13.2, SW13.2
SW14_D: D14.2, SW14.2
SW15_D: D15.2, SW15.2
SW16_D: D16.2, SW16.2
SW17_D: D17.2, SW17.2
SW18_D: D18.2, SW18.2
SW19_D: D19.2, SW19.2
SW20_D: D20.2, SW20.2
SW21_D: D21.2, SW21.2
SW22_D: D22.2, SW22.2
SW23_D: D23.2, SW23.2
SW24_D: D24.2, SW24.2
SW25_D: D25.2, SW25.2
SW26_D: D26.2, SW26.2
SW27_D: D27.2, SW27.2
V3V3: C_U1.1, J_DB.11, U1.10, U1.16

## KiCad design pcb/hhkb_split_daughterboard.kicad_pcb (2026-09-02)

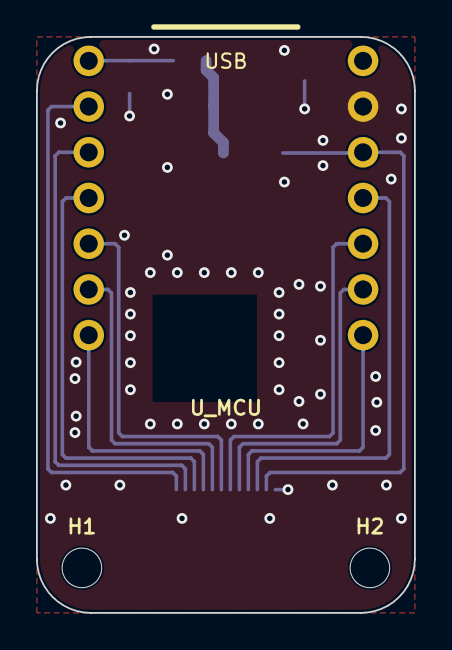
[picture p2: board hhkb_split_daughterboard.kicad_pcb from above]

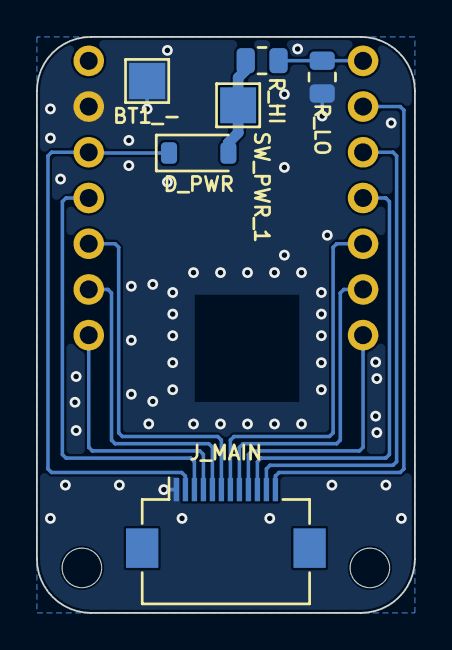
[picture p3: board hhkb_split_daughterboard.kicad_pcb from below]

Board: 2 copper layers, 21.0 x 32.0 mm, 9 parts (6 on the bottom side), 14 nets.

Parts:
BT1_-: battery_holder; TestPoint_Pad_2.0x2.0mm
D_PWR: B5819W; D_SOD-123
H1, H2: MountingHole_2.2mm_M2
J_MAIN: FFC 12P 0.5mm; Hirose_FH12-12S-0.5SH_1x12-1MP_P0.50mm_Horizontal
R_HI: 1M; R_0805_2012Metric
R_LO: 1M; R_0805_2012Metric
SW_PWR_1: wire_pads; TestPoint_Pad_2.0x2.0mm
U_MCU: XIAO nRF52840; XIAO_nRF52840

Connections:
CS: J_MAIN.4, U_MCU.D7
GND: BT1_-.1, J_MAIN.1, R_LO.2, U_MCU.GND
ROW_A: J_MAIN.8, U_MCU.D5
ROW_B: J_MAIN.9, U_MCU.D6
ROW_C: J_MAIN.10, U_MCU.D3
ROW_D: J_MAIN.11, U_MCU.D2
ROW_E: J_MAIN.12, U_MCU.D1
SPARE: J_MAIN.7, U_MCU.D4
SPARE2: J_MAIN.6, U_MCU.D9
SPI_MOSI: J_MAIN.3, U_MCU.D10
SPI_SCK: J_MAIN.5, U_MCU.D8
V3V3: D_PWR.1, J_MAIN.2, U_MCU.3V3
VBATT_SENSE: R_HI.2, R_LO.1, U_MCU.D0
VBATT_SW: D_PWR.2, R_HI.1, SW_PWR_1.1

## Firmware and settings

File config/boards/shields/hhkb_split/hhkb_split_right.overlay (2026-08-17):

/*
 * 右半分（34 キー）。分割の周辺側（ペリフェラル）。
 *
 * 列は 9 本。595（SN74LVC595A）は 8 出力なので 2 個を数珠つなぎにして出力 0..8 を使う
 * （ngpios = 16）。最上段が 9 キーあるため。
 * 右半分の基板上では列 0..7 だが、キーマップ全体では列 6..13 に当たるので、
 * col-offset で 6 だけずらす。これが ZMK の分割の標準的な書き方。
 */
#include "hhkb_split.dtsi"

&default_transform {
	col-offset = <6>;
};

/* 右だけ 595 を 2 個つなぐ。数珠つなぎのぶん取りこぼしやすくなるので、
 * 速い打鍵での確認を Task C2-b の重点項目にしている。 */
&shifter {
	ngpios = <16>;
};

&kscan0 {
	col-gpios
		= <&shifter 0 GPIO_ACTIVE_HIGH>
		, <&shifter 1 GPIO_ACTIVE_HIGH>
		, <&shifter 2 GPIO_ACTIVE_HIGH>
		, <&shifter 3 GPIO_ACTIVE_HIGH>
		, <&shifter 4 GPIO_ACTIVE_HIGH>
		, <&shifter 5 GPIO_ACTIVE_HIGH>
		, <&shifter 6 GPIO_ACTIVE_HIGH>
		, <&shifter 7 GPIO_ACTIVE_HIGH>
		, <&shifter 8 GPIO_ACTIVE_HIGH>
		;
};

	/*
	 * **J_DB から遠い行ほど、パッド列の外側(12番寄り)へ。**
	 * （2026-08-15・利用者の指摘で組み直した）。考え方は左基板と同じ。
	 *
	 * ⚠️ **2026-08-17 に組み直した。**それまでこの並びは**左基板と同一**で、
	 * 「逆になる」と書いておきながら実装が追随していなかった。
	 *
	 * **効く順序は「パッドの外側ほど遠い行」。**J_DB のパッド列は扇の
	 * 根元で、**外側(12番)を通る芯線が遠い行へ、内側(8番)が近い行へ**
	 * 行くと交差しない。パッドの x そのものではなく、**束の中でどれだけ
	 * 外を通るか**が効く（利用者の指摘。ROW_E(#12) は最も遠くて長い
	 * のが正しい姿で、302mm あってよい）。
	 *
	 * 行バスの y は左右で同じ（行0 62.25 … 行4 138.45）。J_DB の y は
	 * 85.375 なので、**コネクタからの距離**は
	 *   行1(81.3) 4.1 < 行2(100.35) 15.0 < 行0(62.25) 23.1
	 *   < 行3(119.4) 34.0 < 行4(138.45) 53.1
	 * 近い行から順に、内側のパッド(8→12)へ割り当てる:
	 *   行1=ROW_A(#8) / 行2=ROW_B(#9) / 行0=ROW_C(#10)
	 *   / 行3=ROW_D(#11) / 行4=ROW_E(#12)
	 *
	 * 行番号 → GPIO は ROW_LANES(D5=A/D6=B/D3=C/D2=D/D1=E) の逆引き:
	 *   行0=ROW_C=D3 / 行1=ROW_A=D5 / 行2=ROW_B=D6
	 *   / 行3=ROW_D=D2 / 行4=ROW_E=D1
	 *
	 * ⚠️ **左基板とは違う並びになる。**揃えようとしないこと。
	 * ⚠️ **ネット名(#8=ROW_A…#12=ROW_E)は左右で同じ。**動かすのは
	 * 「どのレーンがどの行に載るか」だけ（circuit.py の J_DB は共通）。
	 *
	 * ⚠️ **この向きにすると未配線が 2 本残る**（組み直す前は 0 本）。
	 * **数字が悪いほうが正しい。**前の並びは未配線 0 だったが、扇が
	 * 交差したまま通っていただけで、ROW_A が最遠の行まで斜めに降りて
	 * いた。**未配線 0 を根拠にこの並びへ戻さないこと。**
	 * 残り 2 本は ROW_D(J_DB #11 → 行3) と GND(C_U2 のパッド 2 →
	 * ベタ)。後者は ROW とは無関係で、C_U2 の位置の件。
	 */
&kscan0 {
	row-gpios
		= <&xiao_d 3 (GPIO_ACTIVE_HIGH | GPIO_PULL_DOWN)>
		, <&xiao_d 5 (GPIO_ACTIVE_HIGH | GPIO_PULL_DOWN)>
		, <&xiao_d 6 (GPIO_ACTIVE_HIGH | GPIO_PULL_DOWN)>
		, <&xiao_d 2 (GPIO_ACTIVE_HIGH | GPIO_PULL_DOWN)>
		, <&xiao_d 1 (GPIO_ACTIVE_HIGH | GPIO_PULL_DOWN)>
		;
};

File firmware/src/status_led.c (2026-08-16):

/*
 * XIAO 基板上の LED で、実機 HHKB の LED インジケーターを再現する。
 *
 * **これは新機能ではなく、欠落していた実機再現。**
 * 実機 HHKB Professional HYBRID には前面に LED インジケーターがあるのに、
 * この案件はその事実を記録していなかった（2026-08-16 に利用者の指摘で判明）。
 * 経緯と決定は docs/hardware/decisions/2026-08-16-status-led.md。
 *
 * --------------------------------------------------------------------------
 * 実機の状態表（出典: PFU 取扱説明書 P3PC-6641-05・2023 年 6 月）
 * --------------------------------------------------------------------------
 *   消灯                              接続モード / OFF モード
 *   青色点滅（1 秒に 2 回）            ペアリング待機モード
 *   青色点滅（1 秒に 4 回）            ペアリングモード
 *   青色点灯                          接続待機モード
 *   橙色 1 回点滅を 30 秒間隔          電池残量が少ない
 *   橙色 2 回点滅を 15 秒間隔          電池を交換
 *   電源オン時                        青色に点灯したあと、消灯
 *
 * **接続中は「消灯」が実機の正しい挙動。**常時点灯ではないので、
 * 乾電池 2 本でも電流の心配がほぼ無い（実機も同じ理由と思われる）。
 *
 * --------------------------------------------------------------------------
 * ⚠️ 実機に無い状態がある（**完全分割型ゆえ**）
 * --------------------------------------------------------------------------
 * 実機は一体型なので、状態表に「**右手と繋がっているか**」が無い。
 * だが左手は独立した 2 つの接続を持つ:
 *   - ホストへの広告・接続   … 実機の青がそのまま当たる
 *   - **右手のスキャン・接続** … **実機に対応が無い**
 *
 * 右手が落ちると利用者から見て「**キーの右半分が反応しない**」という
 * 最も切実な故障になる。ここに表示が無いのは実用上まずいので、
 * **実機に無い緑**を当て、**ホスト未接続より優先**する。
 *
 * --------------------------------------------------------------------------
 * ⚠️ ZMK に「広告中」「スキャン中」の事象は無い
 * --------------------------------------------------------------------------
 * 広告もスキャンも app/src/split/bluetooth/central.c と ble.c の内部に
 * 閉じていて、イベントマネージャに出てこない。よって
 * **「繋がっていない」を広告／ペアリング待機の代理として使う。**
 * 実機の状態表とは意味が厳密には一致しない。割り切りである。
 *
 * --------------------------------------------------------------------------
 * ⚠️ LED は 3 個ではなく **RGB 1 個**（Seeed Wiki: "3-in-one LED"）
 * --------------------------------------------------------------------------
 * 赤 P0.26 / 緑 P0.30 / 青 P0.06 が 1 パッケージの共通アノード。
 * **1 個なので赤+緑を同時に点けると、同じ一点が橙色に光る**
 * （3 個離れていたら 2 箇所が光るだけで橙には見えない）。
 * 極性は devicetree の GPIO_ACTIVE_LOW が持つので、**ここに反転を書かない**。
 *
 * SPDX-License-Identifier: MIT
 */

#include <zephyr/devicetree.h>
#include <zephyr/drivers/gpio.h>
#include <zephyr/kernel.h>
#include <zephyr/logging/log.h>

#include <zmk/activity.h>
#include <zmk/event_manager.h>
#include <zmk/events/activity_state_changed.h>
#include <zmk/events/battery_state_changed.h>

#if IS_ENABLED(CONFIG_ZMK_SPLIT)
#include <zmk/events/split_peripheral_status_changed.h>
#include <zmk/split/transport/types.h>
#endif

#if IS_ENABLED(CONFIG_ZMK_SPLIT) && !IS_ENABLED(CONFIG_ZMK_SPLIT_ROLE_CENTRAL)
#include <zmk/split/bluetooth/peripheral.h>
#include <zmk/split/transport/peripheral.h>
#endif

#if IS_ENABLED(CONFIG_ZMK_SPLIT_ROLE_CENTRAL)
#include <zmk/ble.h>
#include <zmk/events/ble_active_profile_changed.h>
#include <zmk/split/transport/central.h>
#include <zmk/split/transport/types.h>
#endif

LOG_MODULE_REGISTER(hhkb_status_led, CONFIG_ZMK_LOG_LEVEL);

/* **エイリアスが無い基板では黙って無効化せず、ここで落とす。**
 * xiao_ble//zmk は Zephyr の xiao_ble.dts を #include するだけで
 * leds も aliases も削っていないことを上流で確認済み。 */
BUILD_ASSERT(DT_HAS_ALIAS(led0), "この基板に led0 のエイリアスが無い");
BUILD_ASSERT(DT_HAS_ALIAS(led1), "この基板に led1 のエイリアスが無い");
BUILD_ASSERT(DT_HAS_ALIAS(led2), "この基板に led2 のエイリアスが無い");

static const struct gpio_dt_spec led_r = GPIO_DT_SPEC_GET(DT_ALIAS(led0), gpios);
static const struct gpio_dt_spec led_g = GPIO_DT_SPEC_GET(DT_ALIAS(led1), gpios);
static const struct gpio_dt_spec led_b = GPIO_DT_SPEC_GET(DT_ALIAS(led2), gpios);

/* 実機の状態表に対応する色。橙は赤+緑（RGB 1 個なので混色になる）。 */
enum led_color {
    COLOR_OFF,
    COLOR_BLUE,   /* ホスト系。実機どおり */
    COLOR_AMBER,  /* 電池系。実機どおり */
    COLOR_GREEN,  /* **右手と繋がっていない。実機に無い・分割型固有** */
};

/*
 * 表示すべき状態。**上ほど優先。**
 * 同時に複数成立しうるので、必ず 1 つに畳んでから点ける
 * （状態ごとに別の work を走らせると競合して色が混ざる）。
 */
enum led_state {
    STATE_BOOT,             /* 起動直後: 青点灯 → 消灯 */
    STATE_RECOVERED,        /* **復帰の合図**: 1 秒点灯 → 消灯。色は復帰した系統 */
    STATE_BATT_REPLACE,     /* 橙 2 回点滅 / 15 秒 */
    STATE_BATT_LOW,         /* 橙 1 回点滅 / 30 秒 */
    STATE_LINK_LOST,        /* 分割・ホストの未接続。**交互に出す**（下記） */
    STATE_IDLE,             /* 消灯 */
};

/*
 * **1 つのリンクの状態。**分割（左右間）とホストで独立に持つ。
 *
 * 決定表: docs/hardware/decisions/2026-08-16-led-state-table.md
 *   未ボンド        … 相手を知らない＝ペアリング待ち。**速い点滅（1 秒に 4 回）**
 *   ボンド済み未接続 … 相手は知っていて探している。**遅い点滅（1 秒に 2 回）**
 *   接続済み        … 消灯
 */
enum link_state {
    LINK_UNBONDED,
    LINK_DISCONNECTED,
    LINK_CONNECTED,
};

/* --- 実機の表から来る時定数 ------------------------------------------- */
#define BOOT_ON_MS       3000  /* 「青色に点灯したあと、消灯」 */
#define RECOVERED_ON_MS  1000  /* 復帰の合図。実機も機器切替で「点灯 → 消灯」 */
#define SLOW_BLINK_MS     250  /* **1 秒に 2 回** = 250ms on/off。ボンド済み・未接続 */
#define FAST_BLINK_MS     125  /* **1 秒に 4 回** = 125ms on/off。未ボンド */
#define PULSE_MS          120  /* 橙の 1 回ぶんの点灯 */
#define PULSE_GAP_MS      280  /* 橙 2 回点滅の間隔 */
#define BATT_LOW_MS     30000  /* 橙 1 回点滅を 30 秒間隔 */
#define BATT_REPLACE_MS 15000  /* 橙 2 回点滅を 15 秒間隔 */

/* 電池の 2 段階。ZMK の % は zmk_battery_state_changed で降ってくる。
 * **打ち止め電圧の判定は low_battery_off.c の担当**で、こちらは表示だけ。
 * 同じ数字を 2 か所に書かないため、ここは % の閾値のみを持つ。 */
#define BATT_LOW_PCT     15
#define BATT_REPLACE_PCT  5

/* **左（セントラル）と、分割でない構成だけが持つ。**
 * 右にホストとの接続は無いので、変数ごと存在させない
 * （存在させると「更新されないまま既定値」で青が点滅し続ける）。 */
#if IS_ENABLED(CONFIG_ZMK_SPLIT_ROLE_CENTRAL) || !IS_ENABLED(CONFIG_ZMK_SPLIT)
#define HAS_HOST_LINK 1
static enum link_state host_link = LINK_DISCONNECTED;
#else
#define HAS_HOST_LINK 0
#endif

/* 分割リンク。分割でなければ「繋がっている」扱いで、表示に出さない。 */
#if IS_ENABLED(CONFIG_ZMK_SPLIT)
#define HAS_SPLIT_LINK 1
static enum link_state split_link = LINK_DISCONNECTED;
#else
#define HAS_SPLIT_LINK 0
#endif

/*
 * 「相手と繋がっているか」。左では右手、右では左（セントラル）を指す。
 *
 * ⚠️ **初期値は左右で違う。**
 *   左（セントラル）… 毎 tick に transport の get_status() で読み直すので
 *                      初期値は事実上使われない。true でよい。
 */
static uint8_t battery_pct = 100;
static bool booting = true;

/*
 * **復帰の合図を出すためのもの。**
 *
 * 接続中は消灯（実機どおり）なので、**繋がった瞬間に消えるだけ**だと
 * 見ていない限り気づけない（2026-08-16 に利用者の指摘）。
 * 直前まで未接続だったなら、消える前に 1 秒点灯して知らせる。
 *
 * ⚠️ **色は「復帰した系統」の色。**分割が繋がったなら緑、ホストなら青。
 * 青で一律にしていたのを利用者に指摘されて直した:
 * 「左右間の接続に関するものが緑なのであれば、左右接続の瞬間は緑点灯
 * であるべきでは？」——**色に意味を持たせると決めた以上、合図も同じ色。**
 */
static enum led_color announce_color; /* COLOR_OFF なら合図なし */
static enum zmk_activity_state activity = ZMK_ACTIVITY_ACTIVE;

static void set_color(enum led_color c) {
    gpio_pin_set_dt(&led_r, c == COLOR_AMBER);
    gpio_pin_set_dt(&led_g, c == COLOR_AMBER || c == COLOR_GREEN);
    gpio_pin_set_dt(&led_b, c == COLOR_BLUE);
}
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

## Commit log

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2026-08-05 採寸前の品番同定を必須手順として明記
    スケール基準の記述に残っていた「294 x 108mm」を公称の 294 x 120 x 40mm に修正。
    高さ40mm(キートップ上面まで)は採寸結果の独立した検算に使える。
    PFU 解説記事は複数モデルの写真が混在しているため、採寸前に1枚ずつ品番を
    同定する手順を追加。奥行方向の量は電池の有無で10mm変わるため品番確定が必須。
    一方キートップの段差と傾き角はキャップ形状で決まるため品番差の影響を受けない、
    という切り分けも記載した。
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2026-08-05 断面を実機写真に合わせて修正: 台形は誤りだった
    ユーザー指摘を受けて実機写真(pdweb 97_11.jpg の前縁接写)と照合したところ、
    「垂直な前後面をもつ台形」というモデル化が実機と一致しないことが判明:
    1. 前面は垂直でなく下ほど奥へ傾く(最前点は上端付近)
    2. ベゼル上面から前面への移行は大きなRで丸い
    3. 側面中ほどに上下シェルの合わせ目が走る
    4. 合わせ目より下は内側に絞られ底は一回り小さい
    5. キーは窪んだトレイの中にありベゼルのリムが立ち上がる
    1と2を断面モデルに反映(前面の傾き12°、前縁R6mm。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
2026-08-05 断面モデルの誤りを4点修正(上面の湾曲・背面・キャップ非対称・窪み)
    ユーザー指摘を受けて自分の出力を洗い直し、以下を修正:
    1. 上面を直線から曲線へ。前縁17mmと後縁31.8mmを直線で結んでいたが、
    実機の上面は緩やかな凹曲線(PFUの側面写真の赤い注釈線が示すとおり)。
    弦に対し中央がTOP_SAG下がる放物線で近似。
    2. 背面も前面同様に垂直でない。丸み+傾いた面として作り直した。
    3. キーキャップ断面が左右対称だったのを非対称に修正。topre_key は前後の
    壁角を別々に定義しており(背面86°=ほぼ垂直、前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
2026-08-05 スイッチプレートの生成と自己検証を実装 (Task B1)
    tools/gen_plate.py: layout.py のキー座標から左右のプレートを生成する。
    配列の値は一切持たず、layout.py 経由でのみ取得する。
    左 146.11 x 103.25 x 1.5mm (27キー) / 右 179.45 x 103.25 x 1.5mm (34キー)。
    左は原機294mmのほぼ半分に収まった。
    図示による検証で設計の欠落を発見し修正:
    - 2u以上のキー(左Shift/Enter 2.25u、L/R-Space 3u)にスタビライザー開口が
    無かった。このままでは大きいキーが傾いて使えない。
    - 寸法は推測せず、swillkb Plate & Case Builder の実装 swill/kad の key.go から
    取得(Ge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
2026-08-06 ボトムケースの生成と自己検証を実装 (Task B2 前半)
    tools/gen_case.py: プレートと同じ輪郭のトレイ型ケース。上面は打鍵面と同じ
    7.3° に傾き、プレートがそのまま天板になるサンドイッチ構造。
    左 146.11 x 103.25 x 29.23mm / 右 179.45 x 103.25 x 29.23mm、いずれも水密。
    高さの調整つまみは PLATE_TOP_FRONT の1つだけ。スイッチとキーキャップの実寸が
    分かったら、ホーム段のキートップが31.6mmになるようこれを動かす。基板には影響
    しない。
    実装中に3つの不具合を検出し修正:
    1. builder.part への直接代入がビルダー状態を更新せず、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
    [gen_case.py]
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2026-08-07 組み立て干渉の検査を追加し、実バグ5件を修正
    個々の部品が正しくても、組み合わせて初めて分かる不具合がある。
    tools/gen_assembly.py でケース/プレート/電池蓋/チルト脚/単3電池を
    実際に組み上げ、総当たりで干渉体積を測る。
    tools/interface.py を新設。プレート・ケース・基板が共有する「凍結すべき境界」
    (外形・取付ネジ位置・キー開口・傾斜)を一箇所に集めた。ケースは刷り直せるが
    プレートと基板は発注するため、この境界を基板発注前に確定させる必要がある。
    検出して修正した実バグ:
    1. プレートにネジ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
    [gen_case.py, interface.py]
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2026-08-07 WIP: 占有空間から組み直し、コブ無しで電池を収めた
    前回のコブ方式をやめ、占有空間を先に配置する方針で組み直したところ、
    より良い解が見つかった。
    単3を**左右方向に2本直列**で寝かせると占有空間は 109 x 15.5mm となり、
    前後に並べる(奥行30mm)より薄い。傾いた基板の下の「奥側の背の高い領域」に
    収まるため、後部コブが不要になった。ケース奥行は 102.41mm のまま
    (コブ方式では 116.41mm になっていた)。分割版として小さく収まる。
    あわせて修正:
    - 電池室の天井を撤去。電池の上には基板が来るので板は不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
    [gen_case.py]
2026-08-07 組み立て干渉を解消。全検証が通過
    干渉は 4件・約30,000mm^3 から 0 になった。
    最後まで残っていた原因は**共有定義への委譲漏れ**だった。gen_case が
    ボス位置の独自実装を持ち続けており、プレート(共有定義)とケース(独自実装)で
    ネジ位置が食い違い、さらにボスが電池室の中に立っていた。
    テストが「プレートの穴 vs 共有定義」しか見ておらず、ケースの実物と
    照合していなかったため長く気づけなかった。
    修正:
    - _boss_positions を共有定義 boss_positions_plan へ委譲(独自実装を削除)
    - 後ろ側の中間ボスを電池(幅109mm)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
    [gen_case.py, interface.py]
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2026-08-07 ZMK のビルド失敗を修正: 配置とボード名
    実際にビルドを回して2件の誤りが判明した。
    1. 配置が入れ子だった
    firmware/config に置いていたが、ZMK のワークフローは
    west init -l <config_path> -> ワークスペースは config の親に作られる
    west update -> リポジトリ直下で実行される
    という前提なので、config の親がリポジトリ直下でないと
    "no west workspace found" で失敗する。
    ZMK 標準の配置（リポジトリ直下の config/ と build.yaml）に移した。
    2. ボード名が旧形式だった
    ZMK が Zephyr 4.1 へ移行し、ZMK ツリーのボ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
    [check_zmk_config.py]
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2026-08-07 プレートの縁を実機どおりにし、取付ネジをキーの隙間へ移した
    取付穴が基板の外形をはみ出す不具合の修正。3 つの変更が絡む。
    1. 縁の余白を左右と前後で分けた（interface.PLATE_MARGIN_X / _Y）
    実機は一律ではない。幅 294 − キー 15u で片側 4.125mm、
    奥行 108 − キー 5u で片側 6.375mm。一律 4.0mm にしていたため
    前後が実機より 2.4mm 狭く、ネジを置く余地が無くなっていた。
    実機に合わせたことでプレート奥行が 103.25 → 108.00mm となり、
    **実機への忠実度が上がると同時に設計上の詰まりも解けた。**
    2. 取付ネ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
    [find_mounts.py, gen_case.py, interface.py]
2026-08-07 フェーズ D1 完了。基板の外形・キー配置・取付穴を生成し、DRC を通した
    tools/gen_pcb.py を追加。pcbnew の Python API で .kicad_pcb を組み立てる。
    寸法は一切持たず、interface.py（凍結境界）と layout.py から導く。
    左 140.36 x 102.00mm スイッチ 27 / スタビ 2 / 取付穴 7
    右 173.70 x 102.00mm スイッチ 34 / スタビ 2 / 取付穴 7
    envelopes.py が build123d に依存していて KiCad の Python から読めなかったため、
    PCB_INSET とキー中心の座標変換（plate_positions）を interface.py へ移した。
    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
    [hhkb_split_left.kicad_pcb, hhkb_split_right.kicad_pcb]
2026-08-07 フェーズ D2a 完了。マトリクスの配線を基板に載せ、DRC を通した
    61 キーぶんのダイオードを裏面に置き、行と列のネットを割り当てた。
    左 5 行 × 6 列 スイッチ 27 / ダイオード 27 / ネット 38 本
    右 5 行 × 8 列 スイッチ 34 / ダイオード 34 / ネット 47 本
    行列の割り当ては tools/matrix.py がファームウェアの matrix-transform
    （hhkb_split.dtsi）から読む。**基板とファームで別々に表を持つと、いつか
    片方だけ直して破綻する。** 出所を 1 つにした。
    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
    [hhkb_split_left.kicad_pcb, hhkb_split_right.kicad_pcb]
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2026-08-07 マトリクスを配線。その過程でキーの並び順の取り違えを発見して修正した
    配線を入れた結果、DRC が異常な長さの配線を検出し、根本原因が分かった。
    【最大の発見】layout.split_halves は x 順（列方向）でキーを返すのに、
    キーマップと matrix-transform は行順を前提にしている。それを突き合わせて
    いたため、**61 キー全部の行列割り当てを取り違えていた**。
    しかも私のテストは通っていた。「基板の割り当て」と「期待値」の両方に
    同じ誤った並びを使っていたため、自分自身との一致を確かめていただけだった。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
    [hhkb_split_left.kicad_pcb, hhkb_split_right.kicad_pcb]
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2026-08-07 配線の DRC 違反を解消し、電気設計を見直して文書化
    **配線**
    列の縦配線をキー中心 +2.2〜6.0mm の帯に移した。ここが唯一の空き。
    スタビライザー穴（+6.23〜10.22mm）は NPTH なので両面とも通れない。
    段を飛ばす列は find_clear_x() で穴を避ける x を探す。
    左: 違反 0 / 未配線 0
    右: 違反 0 / 未配線 0
    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
    [hhkb_split_left.kicad_pcb, hhkb_split_right.kicad_pcb]
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2026-08-07 アンテナ・製造規則・シルク・左右表示を直す（開いた見直しで出た 4 件）
    **#4 子基板が電池から 1.0mm しか離れていなかった（今日作り込んだ欠陥）**
    XIAO のアンテナは USB と反対の端にある。単3 電池は金属の塊で、至近距離では
    2.4GHz のアンテナを大きく狂わせる。左右間の BLE 接続は中核要件なのに、
    その通信距離を自分で潰していた。電池を外へ寄せて子基板の場所を作ったとき、
    **幾何の干渉だけを見て電波を見ていなかった。**
    子基板を内側の壁ぎわへ寄せ、隙間 12.2mm を確保（DB_ANTENNA_KEEPOUT=10.0）。
    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
    [hhkb_split_left.kicad_pcb, hhkb_split_right.kicad_pcb]
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2026-08-07 RESET をケースを開けずに押せるようにし、奥の留め方は未解決として記録
    **RESET（open-gaps #9 を解決）**
    XIAO 自身のリセットボタンは上を向いており、真上に本体基板が来るので
    押せない。ブートローダに入るには RESET を素早く 2 回押す必要があり
    （Task C1 で実際に使った）、これが無いとファームを壊したときケースを
    開けるまで復旧できない。しかも開けるにはキーキャップを外す必要があった。
    子基板に押しボタンを載せ、コブの奥の壁に φ2.5 の穴を開けてクリップで突く。
    クリップが本当に通ることを test_a_c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
    [circuit.py, gen_case.py]
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2026-08-07 RESET の穴が子基板の外を向いていたのを直す
    奥の壁に開けていた RESET の穴は、横へ 16.0mm ずらす設計だった。
    **子基板の幅は 20mm（±10）なので、穴の先に基板が無かった。**
    クリップを差しても何も無い空間を突くだけになる。
    test_a_clip_can_reach_the_reset_button は「壁を貫通しているか」しか
    見ておらず、**その先にボタンがあるか**を見ていなかった。
    今日ずっと出ている「別のものを検査していた」型そのもの。
    **穴をケースの底へ移した。**
    - 高さ合わせが要らなくなる（壁だと側面押しのボタンと z を合わせる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
    [gen_case.py]
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2026-08-07 コブに天井を張り、インサートナットを採用、RESET ボタンは廃止
    **電池コブに天井が無かった（open-gaps #14）**
    内側のくり抜きを奥まで通していたため、コブが上に開いたままで**電池が
    上から露出していた。**本体側はプレートと上ケースが覆うが、コブの上には
    何も載らないので、ケース自身が塞ぐ必要がある。
    **「メッシュが水密」は「箱として閉じている」を意味しない。**
    干渉検査も水密検査もこれを見つけられなかった。電池の真上に材料があるかを
    直接見る検査を足した。子基板の RST を調べていて偶然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
    [hhkb_split_left.kicad_pcb, hhkb_split_right.kicad_pcb]
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2026-08-07 帯の中心をソケットの非対称（-2.6〜+7.2mm）を織り込んだ位置へ。右 37→32 件。スイッチ数の検査が電源スイッチを巻き込んでいたのも修正
    [hhkb_split_left.kicad_pcb, hhkb_split_right.kicad_pcb]
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2026-08-07 V3V3 のベタ案: ビア位置の修正では解決しないことを記録。次はゾーンが実際に塗られているかを疑う
    [hhkb_split_left.kicad_pcb, hhkb_split_right.kicad_pcb]
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2026-08-07 計画を 2 点修正（Task 1 の実行で判明したこと）
    1. 陳腐化検査をバイトの sha256 から canonical fingerprint へ。
    KiCad は保存のたびに UUID とフットプリントの書き出し順を変えるため、
    設計が同じでもバイト列は毎回変わる（同じスクリプトを 2 回走らせて
    11632 行の差。正規化すると設計は完全一致）。バイト比較のままだと
    gen_pcb.py を走らせただけで検査が落ち、何も変わっていないのに
    Freerouting を回し直すことになる。tools/boardhash.py を足す。
    「同じなら同じ・違えば違う」を実測で確認済み。
    2. 走査の番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
2026-08-09 検査の甘さを測って締め、CI で黙って飛んでいた穴を塞いだ
    **「通った」を信じる前に、検査がどれだけ緩いかを測った。**
    1. 許容値が実測よりどれだけ大きいかを全対で出した。CONTACT 30 組のうち
    **17 組は実測 0.00 なのに 30mm^3 の窓**が開いていた。実測 0 の組は
    表から落として既定へ、残りは「実測＋わずかな余白」に締め、表に実測値を
    併記した。既定も **1.0 → 0.1mm^3**（左右 68 組の非接触対が厳密に 0.00 で
    あることを確かめたうえで）。インサートの修正を戻すと落ちることを確認。
    2. **CI で黙って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
    [circuit.py, gen_breadboard_c3.py, gen_case.py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]
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2026-08-10 スタビ開口に逃げを入れ、CI が実形状の検査に一度も到達していなかったのを直した
    **#30。**プレートのスタビ開口は swillkb の標準パスを kerf=0 のまま
    転記していて、実物と隙間 0 だった（12 箇所・各 0.02〜0.03mm）。
    - `gen_plate.stab_cutout_face` が多角形のオフセットで外へ広げる。
    28 点は点ごとに外向きが違うので、**手で ±kerf を並べていない**
    - `interface.STAB_KERF = CLEARANCE/2 + STAB_MODEL_OVERSIZE` = 0.15mm
    **「0.02〜0.03mm の膜」の正体を実測で特定した。**swillkb の胴は ±3.375
    （6.750mm）、kiswitch のハウジングは 6.804mm。**標準パスの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
    [interface.py]
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2026-08-10 BT_CLR のヘッダを入れ、設定の重複を掃除した
    dt-bindings/zmk/bt.h を include していなかったので devicetree が
    読めずビルドが落ちた。候補 A の設定が 2 回入っていたのも直した。
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2026-08-10 検証への回答で見つけた 3 つを直した: CI の重複 456 組・「毎回見る」の誇張・無音劣化
    - checks ジョブの bbox 層は REPLACED_BY_REAL が絡む組だけに絞った
    （両端とも real 層と同一形状の組 456 は実形状ジョブと完全な重複だった。
    CI 限定。kicad 無しローカルでは bbox 層が唯一の検査なので絞らない）
    - 一覧が現実とずれたら実形状ジョブで落ちる検査を足した（過小=穴、の向きも記載）
    - real=True なのに実形状が入っていなければ落ちる assert を足した
    （切り替え失敗が bbox 層の緑で隠れる形だった）
    - STRICT_HALF の綴り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
2026-08-11 干渉検査を 1 パスに統合した（#31 案 A・利用者の決定）
    質問は 2 つで、1 回の総当たりが両方に答える:
    1. 実物どうしがぶつからないか（実形状）
    2. 予約が守られているか（条件 1・2 の箱 × ケース等）
    箱は実形状の劣化版ではなく、2 に答える道具（認識の修正を #31 に記録）。
    - 手順 1: changed ゲートの filter が形の入力を覆うことを見張る検査を追加
    （test_ci_gate.py。実際に組んで open を監査。filter を狭めた自己破壊込み）
    - 手順 2: 予約の箱を実形状の組に残し、包含 5 組だけ除外（RESERVATION_CONTAINS）。
    checks ジ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
2026-08-11 使っていない XIAO 内蔵の分圧を、毎回起こしていた
    ビルドが落ちて分かった:
    devicetree error: 'power-gpios' appears in /vbatt ... but is not declared
    in 'properties:' in firmware/dts/bindings/sensor/hhkb,battery-alkaline.yaml
    **このノードはボード側の vbatt と合体していた**（同じパス・同じラベル）。
    xiao_ble//zmk の xiao_ble_zmk.dts が
    vbatt: vbatt {
    io-channels = <&adc 7>; ← XIAO 内蔵の分圧
    power-gpios = <&gpio0 14 (OPEN_DRAIN | ACTIVE_LOW)>;
    output-ohms = <510000>; full-ohms = <1510000>;
    };
    を持っており、こちらが上書きしない property は残る。io-channels と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
2026-08-13 KiCad の Python を固定パスから外し、無い環境では skip・要求時は fail にした
    CI の checks ジョブが 7 件ずっと赤だった原因。test_schematic /
    test_pinmap / test_pcb は pcbnew を使うのに、macOS の固定パスを
    subprocess.run へ直接渡していた。checks ジョブは KiCad を入れない
    （実形状は別ジョブの仕事）ので、**skip ではなく FileNotFoundError**
    で落ちていた。ERC の 3 件は kicad-cli 側が同じ形で、報告ファイルが
    出ないまま read_text で落ちていた。
    **赤が 7 件常駐すると、新しい赤がその中に紛れる。**今回の作業中、
    毎回「自分より前から赤か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
    [test_pinmap.py]
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2026-08-14 KiCad が無い環境で fixture が error になっていたのを skip にした
    b217fea の CI がまだ赤だった原因。real-shape は緑（FFC の修正は効いた）で、
    落ちていたのは checks の **error 6 件**。
    前回の修正が届いていなかった。**テスト本体に guard を置いても、
    fixture の中で先に落ちる。**test_schematic の `pair` fixture は
    `gen_sch.write` 経由で kicad-cli を呼んでおり（gen_sch.py が独自に
    固定パスを持っている）、そこで FileNotFoundError になっていた。
    **fixture の中で落ちると skip ではなく error になる。**
    conftest に require_kicad_cli() を足し、fixture の入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
    [drc.py]
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2026-08-14 警告を数え、浮いた GND を辿って消し、FFC の地面を繋いだ
    DRC の「違反 0」がエラーだけの数だった。--severity-error を外し、
    警告を別の数として記録・表示する。左 35 / 右 48 / 子基板 24、
    合計 107 件がそれまで構造的に見えなかった。合否はエラーだけで
    決める（警告を混ぜると、MX フットプリントが持つ穴の間隔で
    34 件が永久に赤になり、直せない赤が新しい赤を隠す）。
    浮いた GND の判定が「区画の中にビアかパッドがあるか」だった。
    それではビアの行き先を見ておらず、右基板では 23 区画すべてが
    「浮いてい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
    [hhkb_split_daughterboard.kicad_pcb]
2026-08-14 左右の基板を、前のセッションが引き直した状態で記録する
    作業ツリーに残っていた left / right の現物を入れる。ROW の割り当てを
    変えたあとの再配線で、配線とビアが引き直されている（左はビア 79 本、
    右は 41 本が別の位置へ）。route_right.json の unconnected も 0 → 1 に
    なっており、記録と現物の sha256 は一致している。
    left 違反 0 / 未配線 0 / 警告 35
    right 違反 0 / 未配線 1 / 警告 48
    ⚠️ **この 2 枚には 8ef4720 のコード変更が反映されていない。**
    浮いた GND の連結成分での判定、穴を障害物に入れる修正、ELEC_REF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
    [hhkb_split_left.kicad_pcb, hhkb_split_right.kicad_pcb]
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2026-08-14 実形状の干渉検査を、手元でも既定では走らせないようにした
    利用者の指摘「検査についてここ最近想定より大幅に長い時間がかかっている。
    原因を突き止め、削減できるなら削減して」。
    原因は `test_nothing_bites_into_anything_else`（実形状・左右 2 件）。
    **CI では前から別ジョブ（real-shape）に分離されていたのに、ローカルには
    門が無く毎回走っていた。**checks ジョブを skip する条件はあったが、
    `GITHUB_ACTIONS == "true"` を見ていたので手元には効かない。
    同じファイルの重い検査 4 件は `_github_actions_only` で既に
    `REQUIRE_KI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
2026-08-14 CLAUDE.md の検査時間を実測に直した
    48 分 → 9 分（`footprints()` の正規表現修正と、実形状の干渉検査の門）。
    実形状の干渉は既定で走らなくなったので、手元で見るときの叩き方も書いた。
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2026-08-16 D_PWR の実装向きが JLCPCB プレビューで疑わしい件を記録した（#42）
    JLCPCB の発注ページで D_PWR（B5819W・SOD-123）を見ると、KiCad 側の
    設計意図（カソード＝V3V3 側）と、プレビュー上の「+」マークの位置が
    食い違って見える。KiCad 側の設計データ（回路定義・pinmap・3D モデル・
    netlist.ipc）は一貫しているが、JLCPCB がそれをどちら向きで実装するかは
    検証できなかった。matthewlai/JLCKicadTools の Issue #28 で「同じ SOD
    パッケージでも LCSC 品番によって向きが違う」既知の限界が報告されている。
    このリポジトリの export_fab_rotation.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
2026-08-17 U1 を帯 1 へ移した配置で左を配線し直した（利用者の手配置を生成側に取り込み）
    利用者が KiCad 上で U1 を帯 0(166.5, 69.125, 180°) から
    帯 1(195.1375, 88.725, 0°) へ動かした。帯 0 は SPI の唯一の通り道で、
    その途中に U1 が居ると SCK/MOSI/CS が U1 の際で押し出されていた。
    生成側（PLACE）に取り込むため、表の項目に枠を 2 つ足した:
    3 つ目 = 裏面での向き（度）。Flip が必ず 180° を与えるので、
    0° を書けるようにした
    4 つ目 = 帯の中心からのずらし（mm）。既定 0
    C_U1 は今までどおり _place_beside が U1 から算出する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
    [hhkb_split_left.kicad_pcb]
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2026-08-21 COL7/COL8 をレーンへ繋いだ（8 本とも接続完了）
    利用者が COL7/COL8 の素案を引き、私が規則に合わせて微修正した。
    **COL8 は最終的に利用者が引き直したものが正しい。**
    ## 規則（8 本とも揃った）
    跨ぐ行 1 本につきビア 2 個（橋）＋ レーンへの合流 1 個
    COL1/2/5/6 キー4 / ビア7 （行 3 本）
    COL3/4 キー5 / ビア9 （行 4 本）
    COL7 キー2 / ビア5 （行 2 本）
    COL8 キー1 / ビア3 （行 1 本）
    **横線（レーン）を曲げるのではなく、縦線を伸ばしてビア 1 個で結線する**
    （利用者の指摘）。他の 6 本が最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
    [hhkb_split_right.kicad_pcb]
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2026-08-23 ビアと枝を消すコードを取り消した（板の側で消す。#49 は記録として残す）
    利用者「そんな変なコードにするなら、**『元からそんな配線やビアが
    なかった』という状態の方がいい**です。一旦私が PCB を編集するので、
    それに追従してください。」
    `794c44b` を revert（`_drop_useless_vias` と `DEAD_BRANCHES` を削除）。
    ## そのとおりだった
    **この道具の役目は板を写すことで、板を加工することではない。**
    加工の判定を書くたびに壊した——**同じ日に 2 回**:
    1. **ビアの判定**: 「片面にしか線が無い」で落としたら、列の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
    [hhkb_split_left.kicad_pcb, hhkb_split_right.kicad_pcb]
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2026-08-23 ★ 検査が全部緑になった（454 件・赤 0）。古い期待値を持つ検査を 3 件片づけた
    **main は 2026-08-16 から赤 6 件だった。**それが全部消え、増やしたものも無い。
    454 passed, 9 skipped （赤 0）
    ## 消した: test_resources の COMPONENTS（利用者「C で」）
    「基板に載せる部品と面積」を手で書いた表。**実基板と突き合わせたら
    8 項目のうち 5 項目が実在しなかった:**
    バルク 100uF → 2026-08-16 に削除（#44）
    ショットキー → 子基板にある
    分圧 1MΩ → 子基板にある
    電源スイッチのランド → 基板に載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
    [finalize_pcb.py]
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2026-08-23 #46 は 2026-08-17 に修正済みだった——一覧だけが古かったのを直した
    「節を直しても一覧を直さない」型（open-gaps 冒頭に自ら書いてある型）を
    また踏んでいた。dtsi は 25d9168（左・利用者指定 0/1/3）と 3be9698（右）で
    修正済み、配線も #48 で dtsi に合わせて引き直し済み。
    test_keyscan / test_firmware / test_pinmap 39 件緑を確認してから一覧を消した。
    gen_pcb.py の「ファームは後日」というコメントも現状に合わせた。
    （自律改善ブランチ。記録: docs/notes/autonomous-20260823.md）
    [gen_pcb.py]
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2026-08-23 スライサーのプロファイル選択を完全一致優先にし、A1 mini の印刷時間比較を記録
    部分一致だけだと辞書順で 0.2 ノズル用フィラメントが先に選ばれ、
    吐出上限で全部品の推定時間が 2 割増しに化けていた。修正後の実測:
    A1 mini（同梱 0.20mm Standard）は K1 Max 比 2.4〜4.3 倍
    （case_left 1h52m → 8h07m）。検討資料 #51 に追記。
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2026-08-24 #51 最終構成: 左右とも同一断面（余白 3.125）で実装した
    利用者との検討の結果（見た目・構造・強度を左右で変えない。幅の差は
    キー数の差だけにする）:
    - PLATE_MARGIN_X = 3.125 左右共通（右専用定数とヘルパーは削除）。
    幅は 左 144.4 / 右 177.7mm（右はベッド端の試し板 177.6 で実証済み）
    - 左のスイッチ帯 0.8mm 不足は SW_RIB 1.6→1.2（受け箱の壁・3 周）と
    REAR_LID_CLR 0.5→0.3（蓋の口の逃げ）で確保。蓋の掛かり代 2.0 は無傷
    - power_switch_x_center を「窪みと受け箱の両制約の交わりへ丸める」に
    修正（窪みの中央だけ見て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
    [gen_case.py, interface.py]
2026-08-24 #51 の基板一式——3 枚とも DRC 違反 0 / 未配線 0
    利用者が右の J_DB 周り 9 ネットを新しい位置へ引き直し（matrix_only）、
    V3V3 の切れ目と、写しの φ0.5→0.56 化で近すぎたビア 3 ペアも修正。
    写し（matrix_routing.json）→ gen_pcb（外形 左 138.4 / 右 171.7）→
    finalize --src unrouted → DRC の全経路を通した。部品位置の写しを含む。
    [hhkb_split_left.kicad_pcb, hhkb_split_right.kicad_pcb]
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2026-08-24 C_U2 の寄せ（利用者）を取り込み、番人 MAX_DECOUPLE_MM を根拠つきで 6.5 へ——**全検査 458 件緑**
    利用者が C_U2 を U2 の干渉限界まで寄せ（7.11 → 6.21mm）シルクも修正。
    上限 6.0 は「物理から決まらない・17mm 再発防止の番人」と自ら明記された
    経験則なので、実配置 6.21 + 余裕 0.3 = 6.5 へ更新（全ペアの現状:
    左 C_U1 4.97 / 右 C_U1 2.76 / 右 C_U2 6.21）。
    これで #51 関連の作業は完了:
    - 3 基板とも DRC 違反 0 / 未配線 0
    - 実形状の組み立て干渉 左右 0
    - 全検査 458 件緑・skip 9
    [hhkb_split_left.kicad_pcb, hhkb_split_right.kicad_pcb]
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2026-08-24 #49 オシロ用テストパッドを実装した（左 5・右 6・実装なしのランド）
    利用者の決定（Yes）。信号は SPI_SCK / SPI_MOSI / CS / V3V3 / GND、右は
    595 の数珠つなぎ U1_U2 も。ROW/COL はダイオードとソケットのパッドで
    見られるので出さない。kind `testpoint` を回路宣言・pinmap・
    parts.NOT_ASSEMBLED（BOM/CPL に出さない）・回路図の群・gen_pcb の
    絶対座標配置（TP_PLACE・本番の板の空きを実測して決めた）に通した。
    検査側の修正: TestPoint 系フットプリントの円コートヤードを
    _courtyard_bbox が読めず「コートヤード無し」と誤判定していた（四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
    [hhkb_split_left.kicad_pcb, hhkb_split_left.kicad_sch, hhkb_split_right.kicad_pcb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]
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2026-08-25 Revert "#49 オシロ用テストパッドを実装した"——利用者が取り消しを決定
    パッドから既存ネットへのスタブが引けず（利用者「試行錯誤したが諦める」）。
    代案（利用者提案）: 既存のビアのレジストを剥がしてリード線を半田付けできる
    ようにする。部品追加も配線も不要。別コミットで実装する。
    検査側の修正（_courtyard_bbox が fp_circle も読む）だけは有用なので残す。
    This reverts commits b8ea548 and 4f7bba2 (except the test improvement).
    [hhkb_split_left.kicad_pcb, hhkb_split_left.kicad_sch, hhkb_split_right.kicad_pcb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]
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2026-08-28 証拠ページ: FFC 側面図を描画結果で確認して修正（文字の重なり・矢印・右端の欠け）
2026-08-28 #19 J_DB の口を奥向きに回した（FFC は直線・A タイプで正しい）。左は配線無傷で DRC 0、右は J_DB 周りの引き直し待ち
    - 原因: 2026-08-08 の初回配置で Flip() の副作用の 180° をそのまま使い、誰も口の向きを決めていなかった（git 履歴で確認）
    - circuit.py: J_DB のピン表を J_MAIN の鏡像（n ↔ 13-n）に。裏面で 180° 回すとピン 1 の側が入れ替わるため。検査 2 本と決定文書を鏡像に更新
    - gen_pcb.py: J_DB に向き 0° と dy（左 -3.7 / 右 -0.4）。配置は matrix_only の現物が優先
    - 左 matrix_only: J_DB を 0°・3.7mm 奥へ → 12 パッドが同じ座標に戻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
    [hhkb_split_left.kicad_pcb, hhkb_split_left.kicad_sch, hhkb_split_right.kicad_pcb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]
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2026-08-30 発注前の最終確認: 外部ソースでの独立照合（視点 E）と、SOD-123 の警告漏れを修正
    利用者「基板発注後に誤りが見つかったら許しません」を受けて、
    A〜D とは別に**リポジトリの外**の一次情報と突き合わせた。
    A と evidence.py は同じ TI の表を同じ人が読んだもので、読み違いは
    両方に同じように入る（共倒れの穴）。そこを別の出所で塞いだ。
    - 595 16 ピン ← KiCad 公式 74xx.kicad_sym（別の作者）。電気的種別まで一致
    - 数珠つなぎの並び ← ZMK 実物の gpio_595.c
    （"lowest byte is for the first in the chain" + SPI_TRANSFER_MSB）
    → inde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
    [export_fab_rotation.py]
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2026-08-31 配置プレビューで「面」も見るよう §1 に足した（別プラグインでも同じ間違いがありうる）
    利用者の質問「そのままだと、どういうまずいことになっていた？」を受けて
    整理したところ、**私の修正が実際の発注に効かない可能性**に気づいた。
    open-gaps #52 のとおり、**この基板は export_fab.py ではなく別の KiCad
    プラグインで CPL を作る運用**。私が直したのはこのリポジトリ側だけで、
    **そのプラグインにも同じ間違い（IsFlipped を実装面と取り違える）が
    あるかは未確認**。
    → §1 の目視項目に「**配置プレビューを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
2026-09-05 Revert "gen_case: コブの天井を検討用に水平化（実形状検査は未実施）"
    This reverts commit 049f8c69be378775eb36abd374f3964d603f28c2.
    [gen_case.py]
2026-09-05 筐体を案 A（二枚貝の上シェル＋奥板）へ作り直す。#12 決着・電池箱を M2 締結
    利用者の指示（2026-09-05）: 実機再現を最優先に、組み立て性・見栄え・
    頑丈さ・印刷しやすさで筐体をゼロから見直す。発注済みの左基板・子基板は
    変えない。外した過去の決定は 3 つ（同一外形の落とし込み蓋／スライド＋
    ビードの電池蓋／コブ 18mm の凍結）。記録は
    docs/hardware/decisions/2026-09-05-case-redesign-plan-a.md。
    上シェル: ベゼル＋コブ天井＋スカート（合わせ目＝手前のリム面 9.49 より
    上の側壁を持つ。相欠き 3mm）。見せ面が一枚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
    [export_assembly.py, gen_case.py, part_kinds.py]
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2026-09-05 案 A: プレートのネジ逃げを縁まで開けた切り欠きに戻す。ボス角柱への検査の追従
    ネジを 0.59 内へ寄せた（MOUNT_Y 50.91）ので、プレートの逃げ穴が縁から
    0.48 の閉じた穴になっていた（test_no_cutout_reaches_the_edge が検出。割れる形）。
    円に加えて縁までの溝を切り、以前と同じ開いた切り欠きにする。
    test_mounts / test_pcb は「ボスは円柱 φ5.6」の前提だったので、角柱の内面
    （基板の縁 + CLEARANCE、平面図の座標）で見るように更新。
    133/133 緑（mounts・pcb・plate・topcase_geometry）。
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2026-09-06 位置決めピンを上シェルから下向きに戻し、電池の仕切り壁を外壁から子基板の手前まで伸ばす
    利用者の指示（2026-09-06）。棚と溝を廃止したので、裏返した上シェルへプレートを
    真上から入れる工程でピンがプレートの位置を決め、下シェルはピンを見ながら被せられる。
    ピンはインサートの座から下向き、リム面から下シェルのボスの穴へ 2.6
    （FRONT_PIN_INTO_LOWER。FRONT_PIN_H は消した）。
    仕切り壁はプレートの奥端の受けになったので、幅を電池ぶん（BATT_X）から
    外壁〜子基板の場所の手前（DB_W/2 + CLEARANCE）まで広げ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
    [gen_case.py, interface.py]
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2026-09-20 上シェルに、プレートの奥端を止める段を作る（刷れない 0.2 の膜しか無かった）
    利用者の試し刷り 2 回（2026-09-13〜20）: プレートが前後にガタつく。「奥側の壁が無い」。
    **原因**: 上シェルのプレートの奥端の後ろには、厚さ 0.2 の膜（y 53.362〜53.562・
    全幅・高さ約 2）しか無かった。座ぐりの奥端（h_body/2 − CLEARANCE）とコブの空洞の
    始まり（h_body/2）の 0.2 の食い違いの削り残しで、壁として作った物ではない。ノズル
    0.4 では出ない。**.blend では面として描かれるので壁に見える。**しかも板から 1.2
    離れていた。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
2026-10-07 firmware(検討用): 右手のスティックポッドのドライバ（K 案 v7 の下書き）を CI に通す
    買う前の確認（K_SPEC §6-1）。I2C を足してもリンクできるか、行のピンを奪わないか、
    分割の入力が通るかをビルドで見る。実機では未実行。
    - firmware/drivers/stick_pod*.c・behavior_stick_recal.c・binding
    - 追加シールド hhkb_stick_pod（hhkb_pod_right / hhkb_pod_remote / hhkb_pod_left）
    - i2c1 は共通の dtsi で止めておく（既定のピンが行 D5 に当たる）
    - build.yaml に「右にポッド」の 2 件を追加（ポッド無しの 2 件は基準として残す）
    - check_zmk_config.py: 空白区切りの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
    [check_zmk_config.py]
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2026-10-08 firmware(検討用): 固着の判定の幅を devicetree で変えられるようにする（stuck-stable-lsb・既定 3）
    倒れたままのスティックの読みが ±3LSB を超えて揺れると固着に入れず、流れ続けて眠れない（模擬の S9）。
    実物の揺れ幅を測ってから overlay の 1 行で決められるようにした。模擬では 8 にすると 5 分で止まる。
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2026-10-08 手順書 第 6 版・固着の修正の抜け道・中心の採用幅・ログ版の起動待ち
    5 回めの点検（組む人の目）の指摘を直す。
    - stick_pod.c: tilt_muted を、不在に入ったとき・静止で中心を見たときに解く（固着 → 不在 → 中心 → 同じ向きへ
    一杯に倒す、で移動が出なかった）。S24 を足した（直す前のドライバでは 0・直した後は 24019。最初に
    書いた場面は不在にならず、直す前でも通ってしまったので作り直した）
    - centre-stable-lsb: 中心を採用するときの「そろっている」幅を devicetree で（既定 3）
    - ログ版のビルドは起動から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
2026-10-14 rtt-debugging: 確かめた所と残りを分ける（CI 緑・+64% は実測）
    - CI でビルドが通ることを確認（run 38574345395・左右とも success）。
    .uf2 が実際に出来ていることも見た（戻り値ではなく出来た物で判定）
    - **DEBUG/ASSERT のぶん +64%**（右 213,504 → 349,952 バイト）。
    「常用ファームにしない」の根拠を推測から実測に差し替え
    - debugprobe のピンをソースの定義で確認（GP2=SWCLK / GP3=SWDIO / GP1=RESET）。
    **GP1→RST を足すと「リセット 2 度押し」が消える**ので勧める旨を追記
    - probe-rs のチップ名は手元に入れていないので未確認と明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
2026-10-14 #25b の修正が実機で効いていることを RTT で確認（USB 給電 3分48秒）
    **9/26 に踏んだのと同じ条件で soft off しなかった。**
    USB 給電・電源スイッチ OFF・分圧の読みが 0（ログの `battery level to 0`
    で確認）。判定が走る 65 秒・125 秒を通過し、`soft off` も `打ち止め` も 0 件。
    → c97f5f7（CONFIG_USB_DEVICE_STACK の門）は**実機で効いている**。
    コミットに「実機未確認」とあった項目を確認できた。
    **RTT が無ければ、この確認はできなかった**（右は USB ログだと
    USB を挿す＝条件が変わるので、同じ状態を観測できない）。
    ついでに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
2026-10-14 RTT が BLE のアサートで落ちた。静かな版を足す／595 の -11 を特定
    **2026-10-15、ポッド無しの `-rtt` を焼いたら起動 5.9 秒で停止した:**
    ASSERTION FAIL @ zephyr/.../lll_peripheral.c:342
    prepare_cb: Actual EVENT_OVERHEAD_START_US = 2105
    >>> ZEPHYR FATAL ERROR 3: Kernel oops / Halting system
    `LL_ASSERT_OVERHEAD` は無線イベントの準備が長引くと落ちる門で、
    **RTT の出力と SWD の読み出しがその時間を食う。**タイミング次第なので
    前日は同じ構成で 3 分 48 秒持っていた（その日のログにアサートは 0 件）。
    → **RTT 版は BLE 下で常用できない。**build.yaml の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
2026-10-14 rtt-quiet: ZMK_LOG_LEVEL ではビルドが落ちる。LOG_MAX_LEVEL を使う
    前のコミットの `-DCONFIG_ZMK_LOG_LEVEL=3` は**両方のビルドが落ちた**:
    error: ZMK_LOG_LEVEL (app/Kconfig:558) is assigned in a configuration
    file, but is not ...
    `ZMK_LOG_LEVEL` は `if !ZMK_LOGGING_MINIMAL` の中の **prompt 無し
    （default だけ）の記号**なので、コマンドラインからは与えられない。
    Zephyr 側の `LOG_MAX_LEVEL` に変更。こちらは prompt があり、
    「モジュールが指定した level がこれより大きければ飽和させる」ので
    **ZMK が自分で入れる ZMK_LOG_LEVEL=4 の上から効く。**
    しかも dbg を**コン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
2026-10-15 rtt-shell: プロンプトは出た。ただしコマンドは人のターミナルからしか打てない
    実機で確認（右手に焼いた）:
    21:01:46.484: rtt:~$ *** Booting Zephyr OS build 10ba6d0cb38b ***
    **`rtt:~$ ` が出て shell は動いている。**
    ⚠️ **AI 側からはコマンドを送れない。**`probe-rs attach` は対話端末
    （crossterm）を要求する:
    - stdin をパイプ → `Failed to create readline`
    - `script` で疑似端末 → `panicked ... reader source not set`
    **利用者が自分のターミナルで `probe-rs attach --chip nRF52840_xxAA
    --scan-region ram` を打つ**運用になる。.conf に注記した。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
2026-10-15 rtt-shell: shell と log を別の RTT チャンネルに分ける（ビルドが落ちていた）
    前のコミット（SHELL_LOG_BACKEND=n）で**ビルドが失敗した。**
    error: static assertion failed:
    "Conflicting log RTT backend enabled on the same channel"
    （subsys/shell/backends/shell_rtt.c:19 の BUILD_ASSERT）
    shell の RTT バックエンドと log の RTT バックエンドが、**どちらも
    既定でチャンネル 0** を使うため。上り buffer は 3 本あるので分ける:
    shell … 0（`probe-rs attach` が最初に見る）
    log … 1（`LOG_BACKEND_RTT_BUFFER=1`）
    ⚠️ `LOG_BACKEND_RTT_BUFFER_SIZE` は **index > 0 のときだけ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
2026-10-15 PM デバイス化をやめ、直接呼び出しだけにする（ビルドが落ちていた）
    前のコミット（267256d）で status_led.c を SYS_INIT から
    `DEVICE_DEFINE` + `PM_DEVICE_DEFINE` に変えたが、**CI でビルドが落ちた**:
    zephyr/sys/util.h:90: error: expected identifier or '(' before 'int'
    落ちたのは **ポッド無しの版**（`hhkb_split_right`）。`PM_DEVICE` を
    select しているのは `HHKB_STICK_POD` だけなので、そこでは `PM_DEVICE=n` になる。
    **直す方向を変えた。**SYS_INIT のままにして、消灯は
    `hhkb_status_led_off()` の直接呼び出しだけで確実にする。
    soft off を呼ぶのは low_battery_off.c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
2026-10-15 low_battery_off: idle で前提が崩れる件を記録（裏取り済み・未修正）
    **監査の指摘を ZMK のソースで確かめた。正しかった。**
    ZMK の app/src/battery.c:171-173 は `ZMK_ACTIVITY_IDLE`（既定 30 秒の無操作）
    で `k_timer_stop(&battery_timer)` を呼び、**電池の測定を止める。**
    だが low_battery_off.c のタイマーは止まらないので、**止まったあとの
    古いキャッシュを読んで数え続ける**（alk_channel_get は data->millivolts を
    そのまま返すだけで、測り直さない）。
    実害の向き:
    - 凍った値が打ち止めより上 … **いつまでも soft off しない**（撃ち漏らし）
    -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
2026-10-15 監査の記録: 着手した 3 件の状態を更新
    - soft off の LED … 直した。**実機で挙動不変を確認**（今朝の基準と差分なし）
    - 検出力を失っていた検査 … 直した
    - idle とタイマー … 裏取り済み・**未修正**（消費電流との相談なので判断待ち）
    **「#25b は実機で効いている」という今日の報告を訂正する節を足した。**
    あの確認は 3 分 48 秒で idle（30 秒）に入る前。示せたのは
    「USB 給電で誤発火しない」ことだけで、本来の仕事は未確認のまま。
    soft off の LED で直し方を一度間違えた件（PM デバイス化でビルドが落ちた）も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
